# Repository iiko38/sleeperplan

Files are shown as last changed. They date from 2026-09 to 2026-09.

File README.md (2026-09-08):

# Sleeperplan

**A local workshop tool for repeatable timber sleeper flower beds.**

A job file goes in. Labelled parts, exact stock allocations, saw bands, fixing coordinates, purchases, costs and technical drawings come out. The same positioned timber model drives the cut list, the fixing schedule, the SVG drawings, the optional PDF and the OpenSCAD model.

No LLM calls. Core planner runtime: Python 3.11+ and its standard library. Optional PDF dependency: ReportLab.

The planning engine remains deterministic and local/offline. A static client visualiser is now included under `site/` for showing 1/2/3 course options in-browser. It uses generated JSON artifacts and does not require a database.

## Start here on Windows

Extract the ZIP and open PowerShell **inside the `sleeperplan` folder**, alongside this README.

```powershell
py -m sleeperplan plan examples\neighbour.json --out build\neighbour
```

Open `build\neighbour\BUILD.md` and the files in `build\neighbour\drawings`. SVGs open locally in a browser or suitable image/vector viewer.

If OpenSCAD is installed, open the generated 3D model directly:

```cmd
view-cad.cmd build\neighbour\model.scad
```

Compare two and three courses:

```powershell
py -m sleeperplan compare examples\neighbour.json --courses 2 3 --out build\heights
```

To generate printable PDFs too:

```powershell
py -m pip install -e ".[pdf]"
py -m sleeperplan compare examples\neighbour.json --courses 2 3 --out build\heights-pdf --pdf
```

`height-comparison.pdf` is the same-scale comparison. `options-and-build.pdf` is a single combined document covering every requested height: an options table, the same-scale comparison drawing, then a per-option build section (build sequence, assembled view, one plan page per course, cutting diagrams, process and parts boards). Each height's directory also contains a full `workshop.pdf` with the parts and drilling/mark-out sheets.

For Linux, replace `py` with `python3` and use `/` in paths. Installing the package is unnecessary for the core commands when run from this folder. An optional `pip install -e .` also installs the `sleeperplan` command.

**Output directories must be new.** The tool refuses to overwrite an existing folder. Use a revision name such as `build\neighbour-r02`.

## What to edit for a real job

Copy `examples/neighbour.json` to a new file **in the examples folder** to preserve the relative catalogue path. Change the name, bed dimensions, number of courses and quantity. Measurements are **outside dimensions in whole millimetres**. Prices are **integer pence**.

The example is a **2,400 x 1,200 mm outside footprint**, not the neighbour's surveyed dimensions. It uses the same 100 x 200 mm timber section throughout, on edge: 100 mm wall thickness and 200 mm per course. Two courses are 400 mm; three are 600 mm. `orientation: "flat"` swaps these dimensions and selects different screw lengths.

```json
{
  "id": "front",
  "length_mm": 2400,
  "width_mm": 1200,
  "courses": 3,
  "quantity": 2,
  "corner_pattern": "alternating",
  "freeboard_mm": 50,
  "access_sides": 2,
  "site_type": "level_open_ground"
}
```

Put several designs in `beds` and the tool cuts them as **one batch**, sharing stock capacity and rounding screw packs once across the whole job. `examples/batch.json` demonstrates this. `examples/with-offcut.json` adds one measured piece of existing stock.

The catalogue is ordinary editable JSON in `catalogues/`. It contains a dated Wickes price snapshot, not a live stock integration. Duplicate the catalogue for a new date or a different uniform timber profile. Every stock length in one catalogue must have the stated section, treatment/material and finish. Do not mix mismatched timber under one profile.

The supplier description says Wickes in the Clapham / West Sussex area, as requested. **The exact branch is unconfirmed.** The official Worthing store is documented in `docs/SOURCES.md`; no branch availability has been asserted.

## The outputs

| File | Purpose |
|---|---|
| `plan.json` | Full model, normalised inputs, source URLs, date, review gates and input hash. |
| `parts.csv` | Unique piece IDs, lengths, course, orientation, assembly coordinates and allocated stock board. |
| `stock.csv` | Every purchased/existing sleeper used, trims, cost and remaining offcut. |
| `cuts.csv` | Sequential saw operations; exact kerf start, end and blade centre from the original stock datum A. |
| `fixings.csv` | Each screw's entry face, local/global coordinates, direction, receiving piece, nominal penetration and pilot status. |
| `shopping.csv` | Sleeper quantities, whole screw packs, spares and explicit extras/labour. All monetary columns are pence. |
| `web-manifest.json` | Static-web manifest for viewer/links/camera defaults. |
| `quality-report.json` | Deterministic export checks (sections, drawing inventory, callout coverage). |
| `operations.json` | Compiled ordered workshop schedule (receive/label/cut/treat, place/clamp, mark-STOP or drill + drive per fixing, dependencies). Drives the web assembly player. |
| `assembly-manual.pdf` | Optional IKEA-style step-by-step guide compiled from the same operations: one action per numbered panel, 3D keyframes with active/installed/ghost parts, scaled joint sections, explicit repeat counts and mark-out sheet references. |
| `BUILD.md` | Job-specific dimensions, review gates, workflow and assembly instructions. |
| `inventory-proposal.json` | Unused existing inventory and useful new offcuts; merge only after the physical job is completed. |
| `drawings/` | Assembled views, each course, cutting diagrams and an individual fixing sheet for every part. |
| `model.scad` | OpenSCAD geometry; set `explode_mm` to inspect courses and `show_fixing_paths` to show screw paths. |
| `workshop.pdf` | Optional vector workshop pack, generated from the same drawing scene graph. |

The comparison command creates complete **independent alternatives**. It does not consume inventory between options or add their purchases together. It resets review records because changing a design needs a new review.

## What is checked, not guessed

**Joinery.** With alternating corners, courses 1/3 use two full-length long members and shorter cross-members; course 2 reverses which sides pass through the corners. There are no mid-side splices. A length that cannot be cut as one piece is rejected, rather than quietly joined.

**Saw allowance.** Two exact 1,200 mm parts do not fit a 2,400 mm sleeper with a non-zero saw kerf. A final piece that exactly reaches a sound stock end does not get charged an imaginary final cut. End trims are explicit and include their own kerf. Tiny terminal slivers that require edge-shaving are rejected by this full-crosscut model.

**Stock optimisation.** A bounded exact dynamic programme enumerates feasible cutting patterns across stock lengths and finite inventory. Its objective is purchase price, then purchased sleeper count, then total input length. If its deterministic work budget is exhausted, it emits a valid greedy fallback labelled **heuristic**, never “optimal”. If that fallback fails it does not claim infeasibility was proven.

**Screw paths.** Corner and vertical fixing paths are checked against the actual positioned timber. Receivers must exist; tips must stay in the receiving member; modelled shafts must not collide. Upper-course screws are staggered to avoid previously installed screws. Extra intermediate entries are added when collision avoidance would otherwise exceed the configured maximum spacing. These are geometric checks, not strength calculations.

**Purchases and costs.** Screw packs round upwards after the configured spares allowance. Existing stock does not incur a second cash purchase, but its value is left as an explicit cost to resolve. Transport, fill, supports, liner, preparation, treatment, consumables and labour cannot vanish silently: missing values remain `null`/`UNPRICED`, and a complete-cost figure and margin target are withheld.

## Important: the supplied plans are drafts

The code is tested. **The construction detail has not been field-validated.** Do not use an unreviewed pack as a completed engineering design.

The starting Wickes catalogue confirms the screw products, sizes and prices, **not a specific pilot-hole diameter/depth**. All fixing centres are calculated, but `pilot_mode` deliberately starts as `unconfirmed`. After obtaining the actual product/timber instruction or recording an appropriate supervised trial, enter either:

* `pilot_mode: "pilot"`, with the confirmed `pilot_diameter_mm`, `pilot_depth_mm` and `pilot_evidence`; or
* `pilot_mode: "none"`, with evidence supporting no pilot for that exact use.

Both also require `pilot_evidence_kind`: `manufacturer_instruction` or `recorded_trial`. The value `fixture` marks test/demonstration data and **can never issue a workshop plan**, even with a matching approval hash.

There is no automatic “screw diameter minus 2 mm” rule.

Before releasing a pack, measure timber/kerf and review the site, supports and fixing design. Then bind the review to the exact physical design: run a draft plan, copy the printed `Physical design hash` into the job's review block as `approved_physical_design_hash`, and run:

```powershell
py -m sleeperplan plan examples\your-job.json --out build\your-job-reviewed --release --pdf
```

`--release` refuses missing checks, unconfirmed pilots, fixture evidence, out-of-scope sites/heights, and any mismatch between the recorded approval and the current physical design (a changed dimension, screw or machining spec invalidates the old approval; a price-only update does not — hardware selection is price-independent). A missing approval hash blocks draft/check as well (`release_ready: false`), so a draft never looks clearer than its release would be. A released status means the review was recorded, **not** that the software certified a structure. Any changed dimensions, hardware, stock or site require renewed review.

`examples/reviewed-example.json` and `catalogues/wickes-reviewed-2026-09-06.json` are **DEMONSTRATION fixtures** for the release gate. Their pilot "trials" and reviewer records are placeholders, not real workshop evidence.

Generated `build/` output is never distributed from the repo. The only tracked result bundles live under `published/`, which publication tests keep free of issued plans and hash-verified against their manifests.

Every export also compiles an ordered workshop schedule, `operations.json` — receive/label/cut/treat per board, place/clamp per course, then mark (STOP) or drill + drive per fixing with explicit dependencies. The customer site plays that schedule step by step with deterministic screw-insertion animation.

V1 covers **rectangular, open-bottom flower beds on level ground**, with nominal heights up to 600 mm for reviewed output. That height is a software scope boundary, not a universally safe height. Retaining walls, slopes, roofs/decks, hard-surface drainage details, structural calculations, bespoke support/bracing layouts and mid-side splice designs are not implemented. The app will not supply missing engineering by inventing it. See `docs/ENGINEERING.md`.

## Cost entry

Example **syntax**, not recommended prices:

```json
"costs": {
  "labour_minutes": 240,
  "labour_rate_pence_per_hour": 3000,
  "target_margin_bps": 2500,
  "extras": [
    {
      "id": "transport",
      "description": "Collection travel",
      "quantity": 1,
      "unit": "job",
      "unit_price_pence": 1500
    }
  ]
}
```

Here `2500` basis points means 25% gross margin, calculated as cost / (1 - margin), **not** a 25% markup. The target remains blank until every required cost line is supplied. Set a line explicitly to zero only when genuinely not required or already allowed elsewhere. This is an internal cost tool, not an invoice or VAT accounting system.

Fill litres come from the clear opening and specified freeboard. They do not include settlement/compaction allowances, existing soil, displaced supports or a planting recipe. Liner area is a net internal-wall measure, not a roll cutting/nesting plan. Price the actual required materials separately.

## Reproducibility and testing

```powershell
py -m unittest discover -v
py -m sleeperplan plan examples\neighbour.json --as-of 2026-09-06 --out build\reproduction
py -m sleeperplan check examples\neighbour.json --as-of 2026-09-06
```

`check` exits 3 for a geometrically valid but unreviewed draft, 2 for invalid/infeasible input, 0 for a clear review gate. Normal draft `plan` output exits 0 so design iterations are usable. `--release` turns missing review into an error.

The tests include an independent exhaustive subset solver for small cutting cases, seeded geometry/material-conservation cases, stock limits, screw-path collisions, golden worked examples, monetary rounding, review gates, deterministic exports, CLI behaviour and optional PDF generation. `docs/VALIDATION.md` records what was actually run and what remains to be tested on site / native Windows.

## Code map

```
sleeperplan/
  model.py       typed job, stock, timber and fixing records
  config.py      strict JSON/unit/money validation
  geometry.py    positioned pieces, connections and path checks
  cutting.py     exact cutting stock solver, fallback and saw bands
  costing.py     purchases, pack rounding, extras and labour
  planner.py     pipeline, provenance hash and review gates
  drawing.py     shared vector scenes and OpenSCAD export
  export.py      transactional CSV/JSON/drawing/build-note output
  pdf.py         optional print rendering
  cli.py         plan / check / compare
```

`AGENTS.md` gives coding agents the invariants to preserve. Start improvements by reproducing a physical or mathematical failure in a test. Scope now also includes the static customer visualiser in `site/`.

## Customer visualiser

`site/` is a static client-facing page for presenting offer options:

- 1, 2 and 3 course variants loaded from generated `web-manifest.json` bundles.
- Interactive 3D rotate/pan/zoom with Z-up orientation and visible course edges.
- Client-friendly metrics and process flow with links to assembled/process/manual/PDF artifacts.

Run locally:

```powershell
py -m http.server 4173
```

Then open:

```text
http://localhost:4173/site/
```

Optional direct offer links:

```text
http://localhost:4173/site/?offer=c1
http://localhost:4173/site/?offer=c2
http://localhost:4173/site/?offer=c3
```

## Repo harness

This repository follows the NAS repo-harness pattern with current-state files at repo root:

- `AGENTS.md`
- `state.yaml`
- `backlog.md`
- `implementationstatus.md`
- `checklists/2026-09-07-field-trial-wave.md`

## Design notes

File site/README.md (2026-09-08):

# Sleeperplan Viewer

Static customer-facing WebGL showcase for Sleeperplan offer options.

## Features

- Presents 1-course, 2-course and 3-course offer variants
- Interactive 3D orbit/pan/zoom using browser WebGL (Z-up, vendored three.js, no CDN dependency)
- Deterministic **assembly player**: play/pause/step/scrub through the compiled
  operation schedule (`operations.json`) — receive/label/cut per board,
  place/clamp per course, mark-STOP or drill + drive per fixing. Screw insertion
  is deterministic (`head(u) = E - d*(L+g)*(1-u)`); the final frame equals the
  approved model exactly.
- Status & blockers panel showing the loaded plan's real unresolved issues
- Uses manifest camera defaults for a zoomed-out start view; batch beds render
  side by side via display-only offsets
- Links to generated docs/drawings from the same bundle

## Run locally

```sh
python -m http.server 4173
```

Open `http://localhost:4173/site/` and use the option tabs.

Optional direct option query:

```txt
http://localhost:4173/site/?offer=c1
```

## Deploy

Deploy this folder with Vercel:

```sh
vercel --prod
```

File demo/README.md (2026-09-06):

# Worked outputs

Generated with Sleeperplan 0.1.0 and the dated Wickes catalogue, as of 6 September 2026.
These are hypothetical dimensions, not a survey of the neighbour's beds.
All packs deliberately remain DRAFT_MARK_OUT_ONLY: fixing pilots and site/connection details require review.

- `height-options/height-comparison.pdf`: same-scale two- and three-course comparison.
- `height-options/2-courses/workshop.pdf`: full 400 mm high example pack.
- `height-options/3-courses/workshop.pdf`: full 600 mm high example pack.
- `batch/`: three beds optimised as one cutting and purchasing job.
- `with-offcut/`: an existing measured sleeper/offcut included in the allocation.

The 2,400 x 1,200 mm outside footprint has a 2,200 x 1,000 mm clear opening.
Two courses: 6 purchased sleepers, 6 saw cuts, 30 fixing entries, GBP 189.30 timber and screws.
Three courses: 9 purchased sleepers, 8 saw cuts, 52 fixing entries, GBP 294.60 timber and screws.
Those are not complete installation prices: unresolved costs are explicitly unpriced in each plan.

See the main README for commands to generate a new job. Do not modify generated outputs to change a design; edit the input and regenerate into a new directory.

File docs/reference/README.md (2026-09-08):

# Reference: construction pack exemplar (commit 37db13b)

These files are an externally produced visual-construction pack for the
2400 x 1400 x 600 mm long-through model at repo commit `37db13b`. They set the
design standard for Sleeperplan's generated assembly manuals.

## Contents

- `Sleeperplan_Construction_Manual_37db13b_DRAFT.pdf` — 20-page visual step-by-step manual (landscape A4, course-coloured isometrics, stage-per-page narrative, do/don't callouts, per-course stack cards, drill/drive storyboard frames).
- `Sleeperplan_Workshop_Markout_37db13b_DRAFT.pdf` — 6-page workshop cut/mark-out reference cards.
- `Sleeperplan_Construction_PDF_Pack_37db13b_DRAFT.zip` — original distribution bundle.
- `pack/` — extracted bundle: `mark_out_2400x1400_three_courses.csv` (56-fixing register),
  `independent_checks.json`, `pack_manifest.json`, and the generator source
  (`pack/source/make_construction_pack.py`, `pack/source/review_model.py`).

## Provenance

- `pack_manifest.json`: source commit `37db13b`, model `examples/first-model-2400x1400.json`,
  model hash `94ab5b0d...`, status `DRAFT_VISUAL_CONSTRUCTION_PACK`.
- The geometry is an independent transcription (`review_model.py`) cross-checked against
  the committed r08 build artifacts; the pack's own manifest lists the unresolved items
  (pilot diameter/depth, head seat/recess, connection capacity, supports/drainage/site).
- **This is a DRAFT visual pack, not issued drilling instructions.** The manual itself
  says centres are known but drill settings are not; treat it exactly like our own
  DRAFT_MARK_OUT_ONLY outputs.

## How we use it

Adopted as the design target for `assembly-manual.pdf` (v0.5+): the "Book" page
system (kicker / declarative headline / callout boxes / course-colour coding /
stage aggregation instead of one page per fixing), ported to be **generated from
`operations.json` + `plan.json`** so it covers every height and footprint
automatically instead of being a hand-transcribed three-course exemplar.

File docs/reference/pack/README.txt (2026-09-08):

Sleeperplan construction PDF pack for commit 37db13b378fc868f2d4e6b73f8ba19f6e5f4b526

Files:
- Sleeperplan_Construction_Manual_37db13b_DRAFT.pdf : visual step-by-step construction manual
- Sleeperplan_Workshop_Markout_37db13b_DRAFT.pdf : workshop cut / mark-out reference cards
- mark_out_2400x1400_three_courses.csv : full transcribed 56-fixing register
- pack_manifest.json : provenance and unresolved release items

Status: DRAFT. Exact cutting locations and fixing centres are shown. Pilot-hole and head-seat instructions remain unconfirmed and are deliberately shown as TBC.

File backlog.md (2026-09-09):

# Sleeperplan Backlog & Roadmap

A deterministic, offline workshop tool for repeatable timber sleeper flower beds.

## Current Milestone: MVP Complete & Hardened (v0.1.0)
- [x] Deterministic 3D solids coordinate model with alternating corner joinery.
- [x] Exact DP cutting stock solver with bounded heuristic fallback.
- [x] Axis-aligned screw path clearance and 3D collision avoidance.
- [x] Global screw pack rounding with spares allowance.
- [x] Complete transactional exports: CSV BOMs, cut list, SVG technical drawings, OpenSCAD 3D model, vector PDF workshop pack.
- [x] Independent multi-option height comparison tool (`compare`).
- [x] Release review gating (`--release`) blocking unreviewed drafts or unconfirmed pilot specs.
- [x] 83-test comprehensive test suite with property and oracle checks.
- [x] Windows native execution verified (`health.cmd`, `health.ps1`, `sleeperplan.cmd`).
- [x] OpenSCAD workstation integration verified (`view-cad.cmd`, OpenSCAD 2021.01, health smoke compile).
- [x] Deterministic static web manifest + quality report export (`web-manifest.json`, `quality-report.json`).
- [x] Customer-facing static offer visualiser (`site/`) for 1/2/3 course options with interactive 3D and process walkthrough.
- [x] Vercel static deployment pipeline verified for `site/`.

## v0.2.0 / v0.3.0 Hardening (review-driven) — complete
- [x] Physical-design approval binding (`approved_physical_design_hash`); price-only revisions keep approval; machining changes invalidate it (v0.2.0).
- [x] Screw heads/seats declared unmodelled with explicit `head_seat_unmodeled` issue and docs (v0.2.0).
- [x] DEMONSTRATION fixture marking on reviewed example/catalogue with regression test (v0.2.0).
- [x] Combined `options-and-build.pdf` covering 1/2/3 course options + build guides (v0.2.0).
- [x] Deterministic operations model (`operations.json`) + web assembly player with deterministic screw-insertion animation (v0.3.0).
- [x] Price-independent screw selection; commercial rules excluded from physical hash; generator version included (v0.3.0).
- [x] Evidence-kind gate (`fixture` can never issue) (v0.3.0).
- [x] Unified draft/check/release readiness (`release_ready`) (v0.3.0).
- [x] Publication quarantine: stale packs removed, `published/` allowlist with identity checks; legacy viewer defaults to published pack and escapes HTML (v0.3.0).
- [x] Viewer hardening: DPR resize, per-bed display groups, recursive disposal, manifest/plan hash check, blockers panel (v0.3.0).
- [x] Print sizing: paginated parts/stock pages with readable continuation tables (v0.3.0).

---

## Next Milestone: Physical Shop & Field Validation

- [ ] **HIGH PRIORITY — 3-tier 9-sleeper optimisation:**
  - Replace the current 12-sleeper 2400 x 1400 example with a near-identical-width design that uses **9 x 2400 mm sleepers total**.
  - Six 2400 mm sleepers remain full length for the long sides; the remaining three 2400 mm sleepers each produce two short sides.
  - Do **not** preserve an exact 1400 mm outside width if that forces three extra sleepers. Accept a few millimetres of width change to fit real kerf efficiently.
  - Current integer-mm planner target: **1197 mm short sides / 1397 mm outside width**, which fits two identical shorts in a 2400 mm board under the existing conservative 3 mm kerf model (`1197 + 3 + 1197 + 3 = 2400`).
  - Re-run BOM, cuts, costs, operations, animation and PDF packs after the geometry change; regression-test that the 3-course option purchases exactly 9 sleepers.
  - Reconfirm against the measured real sleeper lengths and actual saw kerf before finalising the physical prototype.

- [x] **Session Harness Refresh (2026-09-07):**
  - Verified repo core harness files against `P:\homelab\patterns\repo-harness` (`AGENTS.md`, `state.yaml`, `backlog.md`, `implementationstatus.md`).
  - Added a dated active checklist under `checklists/` for the current field-validation wave.

- [ ] **Stock Dimension & Kerf Calibration:**
  - Measure 3-5 real 100 x 200 x 2400 mm sleepers from Wickes Worthing / regional store.
  - Measure actual saw kerf on 100x200 crosscuts with the target workshop circular/mitre saw.
  - Check end squareness and measure minimum squaring trim required on factory ends.
- [ ] **Fastener & Pilot Testing:**
  - Test drive Wickes 7x150 mm and 7x250 mm washer-head screws into scrap treated softwood sleepers.
  - Compare direct driving vs 4 mm / 5 mm pilot hole: measure split risk near edges/end-grain and torque resistance.
  - Document confirmed pilot diameter, depth, and driving technique in `docs/SOURCES.md`.
- [ ] **First Prototype Assembly (Controlled Trial):**
  - Cut and assemble a 2-course prototype according to generated `cuts.csv` and `BUILD.md`.
  - Validate physical alignment, hole mark-outs, and corner interlocks against SVG drawings.
  - Inspect vertical screw staggering in real timber.

---

## Future Feature Backlog (Post-Field Validation)

### Joinery & Structural Support
- [ ] **Support & Bracing Module:**
  - Automated corner post / internal stake sizing and screw calculation for beds on soft ground or heights > 400 mm.
  - Ground anchor and staking schedules.
- [ ] **Liner & Drainage Detailer:**
  - Per-bed liner cutting layout and membrane overlap calculation.
  - Freeboard and base gravel drainage calculator.

### Catalogue & Stock Expansion
- [ ] **Multi-Supplier Catalogues:**
  - Snapshots for Travis Perkins, B&Q, Jewson, and local timber merchants.
  - Support for alternate sleeper sections (e.g. 125 x 250 mm oak, 100 x 150 mm softwood).
- [ ] **Reusable Offcut Management:**
  - Automated ingestion of `inventory-proposal.json` from completed jobs into a workshop stock registry.

### Workshop Productivity
- [ ] **Mark-Out & Jig Templates:**
  - 1:1 printable drill hole drilling templates for corner and stack fixings.
  - Cut stop / stop-block setup sheet for batch cutting.

### Client Experience (Static Site)
- [ ] **Operations-driven PDF keyframes:**
  - Render step keyframes from `operations.json` into the printable packs so PDF and player share one schedule.
- [ ] **Joint Recipe & Machining Operations (blocked on physical trial):**
  - Per-joint recipe records (head seat, bore preparation, depth datum, evidence) consumed by operations, drawings and CSVs.
  - Per-recipe fastener cards instead of one card per SKU (F08).
- [ ] **Sales Narrative Pass:**
  - Add clearer option positioning text (best-fit use cases) without overstating engineering claims.
  - Add optional branded hero imagery/background assets while keeping page load fast.
- [ ] **Visual Comparison Enhancements:**
  - Add side-by-side mini thumbnails for 1/2/3 course profiles.
  - Add optional animated transition between course options.

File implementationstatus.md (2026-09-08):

# Implementation Status

## Current Snapshot
- **Version:** 0.3.0
- **Status:** Planner + operations model + assembly player live; approval/evidence/publication gates enforced; physical joint-recipe trial still required
- **Host Platform:** Windows 11 Native (Verified on `DESKTOP`)
- **Python Version:** CPython 3.12.10 (64-bit)
- **Test Results:** 99 tests passed (unittest, 100% passing)
- **Core Dependencies:** Standard Library only (`reportlab 4.5.1` for PDF export, `pytest 9.1.1` for test execution)

## Verified Functionality
1. **Core Geometry Engine:**
   - Uniform timber profiles on edge (e.g. 100x200 mm) or flat.
   - Alternating corner joints across courses (odd/even course interlocking).
   - Exact piece coordinates, clear opening, and cavity volume calculations.
2. **Cutting Stock Optimizer:**
   - Linear stock cutting optimizer using bounded exact dynamic programming.
   - Heuristic best-fit fallback when budget is exceeded (never claims false infeasibility).
   - Strict material conservation accounting for kerf and squaring trims.
3. **Fixing & Fastener Geometry:**
   - 3D axis-aligned clearance checking preventing screw collisions.
   - Vertical stack screw staggering between adjacent courses.
   - Full-penetration checks into target receiving timber.
4. **Costing & Procurement:**
   - Exact sleeper purchases from inventory and store catalogues.
   - Global screw pack rounding with spares allowance across whole batches.
   - Strict unknown-cost withholding (never silently assumes £0 for missing materials/labour).
5. **Multi-Format Export Pipeline:**
   - Technical mark-out and assembly drawings in SVG.
   - 3D OpenSCAD model generation (`model.scad`).
   - Vector PDF workshop packs and comparative height sheets (`workshop.pdf`, `height-comparison.pdf`).
   - CSV outputs: `cuts.csv`, `parts.csv`, `fixings.csv`, `stock.csv`, `shopping.csv`.
6. **Safety & Scope Enforcing Gates:**
   - Strict review gating (`--release`) rejecting drafts without recorded human measurement, site check, fixing check, and confirmed pilot hole evidence.
   - Hard boundary at 600 mm max height and open-bottom level-ground beds for v1 release.
7. **Static Web Export + Client Visualiser:**
   - Export now includes `web-manifest.json` (artifact/drawing pointers + viewer camera defaults) and `quality-report.json` (deterministic export checks).
   - Customer-facing static site in `site/` presents 1/2/3 course offer options with interactive 3D orbit/zoom/pan.
   - Course separation is visually explicit via per-piece black edge outlines; viewer uses Z-up axis to match generated geometry.
   - Client view includes at-a-glance metrics and process walkthrough, with direct links to assembled drawing, process sheet, manual, and printable PDF.
   - Vercel deployment verified and aliased to: `https://site-rho-six-fdck1jw7c6.vercel.app`.
8. **Combined Height-Options PDF:**
   - `compare --pdf` additionally renders `options-and-build.pdf`: options table, same-scale comparison, then per-option build sequence + course plans + cutting/process/parts/stock pages.
9. **Deterministic Operations Model + Assembly Player:**
   - `sleeperplan/operations.py` compiles an ordered, typed workshop schedule (`operations.json`, schema `sleeperplan.operations.v1`) from the same geometry: receive/label/cut/treat per board, place/clamp per course, mark-STOP or drill + drive per fixing, supports/final checks, with explicit dependencies.
   - The customer site plays that schedule: play/pause/step/scrub, pieces appear when placed, screws animate insertion via `head(u) = E - d*(L+g)*(1-u)` (final frame equals the approved model exactly), per-step camera framing, active-piece highlighting, per-bed display groups for batch jobs.
10. **Approval, Evidence and Publication Gates:**
    - `--release` binds `review.approved_physical_design_hash` to the current physical design hash (price-only revisions keep approval; dimension/hardware/machining changes invalidate it). Screw selection is price-independent, so repricing can never swap hardware under an approval.
    - `pilot_evidence_kind` (`fixture` | `manufacturer_instruction` | `recorded_trial`) is required for confirmed pilot modes; fixture evidence can never issue a workshop plan.
    - One readiness calculation shared by draft/check/release (`release_ready` field); publication tests keep the public tree (`published/`, `site/demo`) free of issued plans and verify manifest/plan identity.

## Developer Harness & Automation
- `health.cmd` / `health.ps1`: One-command comprehensive environment, dependency, OpenSCAD compile smoke, test suite, and CLI smoke test verification.
- `sleeperplan.cmd`: Root CLI runner directly delegating to `.venv`.
- `view-cad.cmd`: One-command OpenSCAD launcher for generated `model.scad` outputs.
- Directory junction `projects/sleeperplan` linked to `projects/sleepers`.
- Repo harness core files aligned with NAS pattern (`AGENTS.md`, `state.yaml`, `backlog.md`, `implementationstatus.md`) and active checklist tracking in `checklists/`.

## Next Operational Step
Execute physical shop measurement trial on Wickes sleepers and record pilot hole torque/split evidence to promote draft job files to reviewed release packs.

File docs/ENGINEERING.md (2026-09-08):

# Geometry contract, workshop conventions and limits

## One coordinate model

Each bed has its own local XYZ origin at its outside S/W bottom corner. S/N are labels, not compass directions. X follows the nominal long side; Y follows the other side; Z is height. S/N members are placed in +X; W/E members in +Y. All actual geometry uses positioned rectangular solids.

For outside length L, outside width W and wall thickness t:

- Odd alternating courses: S/N lengths L, W/E lengths W - 2t.
- Even alternating courses: S/N lengths L - 2t, W/E lengths W.
- Clear opening: (L - 2t) x (W - 2t).
- Top height: course count x course height.
- Fill volume: clear length x clear width x (height - freeboard), divided by 1,000,000 for litres.

The nominal profile is uniform across every piece. Edge/flat changes the section orientation, not its material. The photograph is inspiration only: no dimensions or buildable corner arrangement have been reverse-engineered from its perspective.

The compiler checks the expected ring area, absence of timber overlap and bed envelope for every course. Drawings never calculate a different length independently. Piece IDs include design, instance, course and side.

## Saw geometry

Every cutting stock item has gross length G, total start/end removals a/b, and kerf k. Usable length U = G - a - b. Trims include their kerf and are either zero or at least k. All cut coordinates are relative to the original stock datum A, before trimming.

A pattern containing n finished pieces with total finished length S is feasible precisely when:

```
S + k*(n-1) == U       # final piece reaches usable stock end: n-1 cuts
or
S + k*n <= U           # a final cut is made: n cuts
```

This is intentionally conservative about edge shaving. It does not assume that a terminal sliver narrower than k can be removed safely with a partially overhanging blade. A sound full-stock piece needs zero crosscuts. A full crosscut through a sleeper may need multiple tool passes; tool capacity and technique are not selected by this code.

Every board must conserve material:

```
gross length = finished parts + retained/discarded tail + complete trims + kerf from part-separating cuts
```

Actual dimensions, timber movement, knots, splits and blade wander can invalidate a nominal plan. Measure and regenerate; do not quietly shorten a component. To allow squaring of a nominal 2,400 mm sleeper, set the actual end removals and choose a feasible footprint. Full-length sides at 2,400 mm assume genuinely usable ends and adequate measured stock length.

The optimiser is exact for its encoded linear-stock/crosscut problem when `optimality_proven` is true. It is not optimising manufacturing time, tool changes, defects, grain, moisture, delivery charges, bulk-price tiers or a speculative resale value of offcuts. Fixed delivery/collection and other costs belong in explicit extras. Store availability is unconfirmed unless quantities are entered after checking.

The search bound counts work deterministically. A completed dynamic programme proves the lowest lexicographic objective over the enumerated stock model. A budget-limited best-fit-decreasing fallback is marked heuristic and may cost more. Independent tests compare exact results against a separate subset-partition solver.

## Fixing geometry is not connection engineering

Corner screws enter the OUTER broad face of the full-through member at t/2 from each end, at one-quarter and three-quarters of the course height. They traverse t before entering end grain of the perpendicular member. These positions form a proposed regular marking pattern, not a Eurocode/manufacturer-certified joint detail.

Stack screws enter the TOP face, on the cross-section centreline, and traverse one course height into the course below. The routine identifies the actual receiver and checks the path. It moves upper-course entries to avoid lower screws and the corner screws. Where a shift enlarges a gap beyond the configured maximum, an intermediate entry is added rather than accepting the gap.

The starting rules are **editable shop-layout assumptions**:

| Rule | Starting value | Meaning / limitation |
|---|---:|---|
| Nominal minimum penetration | 50 mm | Includes screw point; does not establish effective thread engagement or holding capacity. |
| Far-face clearance | 20 mm | Keeps a nominal straight tip away from the opposite timber face. |
| Stack end clearance | 80 mm | Geometric distance from receiving/through member ends for stack fixings only. |
| Side clearance | 20 mm | Geometric cross-section clearance for stack paths. |
| Stack target end inset | 200 mm | Increased when necessary for the section/end-clearance rule. |
| Stack maximum spacing | 600 mm | Layout rule, not proof of resistance to soil pressure. |
| Additional shaft separation | 12 mm | Added to both shaft radii for idealised path collision checks; not a full swept-tool or hardware-head model. |

For two perpendicular or parallel axis-aligned screw segments, minimum segment separation is computed from their interval separations on X/Y/Z. This is exact for these straight, axis-aligned paths. It does not model angled driving, large/irregular heads, countersinks, clamps, drill body access, dimensional tolerances or timber displacement. The installer must check these before execution.

The actual fastener selection must be suitable for treated timber, exterior exposure, end-grain withdrawal, loading and the full site. Manufacturer guidance and competent review take precedence over these geometric defaults. Brackets/posts/through-bolts or other supports may be required; this version does not design or draw them. Their materials and labour must be priced explicitly and their installation detail recorded separately.

**Screw heads, bearing seats, recesses and driver access are not modelled.** Only idealised shafts are collision-checked. On stacked courses a protruding head can stop the next sleeper sitting flat even though every shaft passes the clearance check; recessing a bearing seat deepens the effective hole and moves the tip, so tip clearance must be re-checked after any recess. The plan raises a `head_seat_unmodeled` issue whenever a bed has more than one course. Confirm the head-seat detail with the actual hardware before stacking; an approved joint recipe (hardware, head seat, bore preparation, depth datum, evidence) is a prerequisite for sellable kits.

**Pilot diameter and depth are not inferred.** The selected Wickes product pages did not establish those values. Confirm them against the actual product/timber and record the evidence. A recorded no-pilot instruction is distinct from an unknown pilot instruction. The release gate enforces that distinction, but cannot verify the truth of a human's evidence.

## Site and material limits

The executable v1 design envelope is a rectangular open-bottom flower bed on level ground, no mid-side splices and a reviewed-output height not above 600 mm. The software can draft higher alternatives to demonstrate why review is blocked. The envelope is a scope choice, not proof that every bed inside it is safe.

No structural design is supplied for retaining slopes, roofs/decks, hard surfaces, foundations, lateral loads, soil pressure, posts/bracing, accessibility, buried services or a load-bearing use. No guarantee of timber warranty after cutting is made. The cited Wickes timber instructions say to preserve cut ends, so follow the compatible treatment supplier's method. Follow tool and PPE instructions and assess safe lifting/transport; the stock can be heavy and wet timber weight varies.

Drainage is site-specific. A liner/protection layer must not create an undrained basin. RHS guidance distinguishes construction on hard surfaces; v1 refuses to release that site type because it has not implemented those drainage details. Fill calculations deliberately stop at cavity geometry and do not invent soil recipes, density-based bulk-bag conversions, settlement percentages or planting choices.

The “centre reach over 650 mm” warning is a user-fit prompt only; it is not an accessibility standard. A decorative bed with planting access around it differs from a productive bed worked from one side. Confirm the actual use and reach.

## Release and physical validation

All included examples are drafts. The three review flags plus reviewer/date/notes record that measurements, site/supports and fixings have been checked. `--release` requires them and confirmed pilot specifications, and refuses unsupported sites/heights. This is a workflow gate, not professional certification. Editing a reviewed job does not make its old review applicable to the new design; renew the review after every meaningful change. Height comparison resets reviews automatically.

**Approval binding.** The plan carries a `physical_design_hash` — a SHA-256 over the physical artefact only (generator version, profile, beds, orientation, stock lengths/trims, screw lengths/diameters/pilot spec, geometric rules). Prices, pack sizes, availability, commercial rules (spares allowance, price-age limits), provenance text, the review block and the as-of date are excluded, so a price-only revision does not invalidate a physical approval, while any change to dimensions, hardware or machining does. Hardware selection is itself price-independent (`length, diameter, id`): repricing can never swap the installed screw. `--release` requires `review.approved_physical_design_hash` to equal the current hash: a mismatch blocks release (`stale_approval`), and a missing hash blocks draft, check and release (`approval_hash_required`); plans carry the unified `release_ready` field. Workflow: run a draft plan, copy the printed physical design hash into the job's review block once the physical review is genuinely done, then release. `examples/reviewed-example.json` and `catalogues/wickes-reviewed-2026-09-06.json` are DEMONSTRATION fixtures for this gate — their reviewer/pilot text is not real evidence.

**Evidence kinds.** Confirmed pilot modes require `pilot_evidence_kind`: `manufacturer_instruction`, `recorded_trial`, or `fixture`. Fixture evidence is test/demonstration data and blocks issuance unconditionally (`fixture_evidence`), whatever the evidence text claims. Software cannot verify the truth of a human trial; it can refuse known test data.

**Operations schedule.** Every export compiles `operations.json` (`sleeperplan.operations.v1`): an ordered, typed list of workshop operations compiled from the same geometry — receive/label/cut/treat per stock board, place/clamp per course, then mark-STOP or drill + drive per fixing, then supports/final checks. Dependencies are explicit; a drive operation always follows its course clamp and its own preparation. Unknown physical values (pilot spec, head seat) surface as mark-out-only/STOP operations, never invented machining instructions. The web assembly player renders this schedule deterministically: displayed state is a pure function of plan + operation index + progress, and screw insertion uses `head(u) = E - d*(L+g)*(1-u)` so the final frame equals the approved modelled position exactly.

For the first real bed, use a controlled trial: measure stock/kerf; verify a full-size course; check the saw sequence against one physical board; confirm the exact pilot/driver setup and connection with a competent builder or supplier; then compare the installed course to the drawing. Verify supports and drainage before filling. Record changes and make regression tests before standardising a sellable kit.

Future development should follow failures found in that process. Likely useful extensions are a properly specified support/bracing module, surveyed site constraints, actual-vs-estimated labour, material valuation, price import and manufacturing jigs. A storefront is not needed to validate any of those fundamentals.

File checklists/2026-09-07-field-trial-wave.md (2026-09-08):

# Checklist - 2026-09-07: Field Trial Wave

## Context

This wave starts after MVP software validation and OpenSCAD workstation bedding-in.
The repo remains an offline planning tool and default outputs remain draft until physical evidence is captured.

## Non-Negotiables

- Preserve AGENTS.md invariants, especially geometry/cut/fixing single-model truth.
- Keep units strict (integer mm, integer pence) and avoid inferred pilot rules.
- Do not claim field validation without recorded evidence paths.
- Do not change release status for draft examples without fresh measured review data.

## Phase 1 - Harness And Tooling Baseline

- [x] Confirm OpenSCAD installation on workstation.
- [x] Confirm OpenSCAD compile smoke in health script (`demo/batch/model.scad` -> CSG).
- [x] Confirm repo harness core docs are present (`AGENTS.md`, `state.yaml`, `backlog.md`, `implementationstatus.md`).
- [x] Evidence: OpenSCAD version 2021.01 detected; `health.ps1` run passed with 83 tests and OpenSCAD smoke compile.

## Phase 2 - Physical Stock And Fastener Evidence

- [ ] Measure 3-5 real sleepers (actual section, length, squaring trim).
- [ ] Measure actual workshop kerf on target saw setup.
- [ ] Pilot tests for Wickes 7x150 and 7x250 screws (direct drive vs pilot diameters).
- [ ] Record evidence and source metadata in `docs/SOURCES.md`.
- [ ] Evidence:

## Phase 3 - Controlled Prototype Build

- [ ] Build one 2-course prototype from generated plan outputs.
- [ ] Validate cut list and fixing coordinates against physical assembly outcomes.
- [ ] Record any geometry or workflow deltas as reproducible tests before code changes.
- [ ] Evidence:

## Stop Conditions

- Any measured mismatch that breaks material conservation or fixing clearance assumptions.
- Any screw/pilot finding that invalidates current default fastener assumptions.
- Any release-gate bypass attempt without evidence updates.

## Current Next Step

Collect first stock and kerf measurements and add dated evidence to `docs/SOURCES.md`.

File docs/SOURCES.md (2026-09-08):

# Source register

Checked on **6 September 2026**. These are manual public-page snapshots, not scraped/live integrations. Prices are as displayed and exclude delivery. Recheck prices, product suitability and branch stock before buying. The repository does not copy product imagery or manufacturers' documents.

## Timber catalogue

**Wickes SKU 276785** — UC4 incised light green garden sleeper, nominal 100 x 200 x 2400 mm. Displayed promotional price GBP 28 (previous price shown GBP 33). Product page lists 38.40 kg, approximate sizes, ground-contact treatment and treatment of cut ends. The orientation in Sleeperplan is an explicit job setting; it is not inferred from Wickes' “height/thickness” field names.

https://www.wickes.co.uk/Wickes-UC4-Incised-Light-Green-Garden-Sleeper---100-x-200-x-2400mm/p/276785

**Wickes SKU 256948** — matching nominal 100 x 200 x 1800 mm sleeper. Displayed promotional price GBP 24 (previous price shown GBP 29). No weight is populated in our snapshot, so the software will not invent a complete collection weight for an order containing it.

https://www.wickes.co.uk/Wickes-UC4-Incised-Light-Green-Garden-Sleeper---100-x-200-x-1800mm/p/256948

## Candidate fasteners

**Wickes SKU 287686** — Timber Drive washer-head screw, 7 x 150 mm, pack of 25, GBP 9. The page describes Torx drive, exterior use and a weather-resistant coating for treated timber.

https://www.wickes.co.uk/Wickes-Timber-Drive-Washer-Head-Screws---7-x-150mm---Pack-of-25/p/287686

**Wickes SKU 287688** — matching 7 x 250 mm screws, pack of 25, GBP 12.30.

https://www.wickes.co.uk/Wickes-Timber-Drive-Washer-Head-Screws---7-x-250mm---Pack-of-25/p/287688

**Wickes search API cross-check (same product family):** `/search/suggestProductsSecure` returns the four 7 mm Timber Drive washer-head sizes as one range (`287685`, `287686`, `287687`, `287688`) with product-page links and image IDs `GPID_5000106026`..`GPID_5000106029`. Product pages expose manufacturer model numbers `NEW_45`..`NEW_48` for these four sizes.

https://www.wickes.co.uk/search/suggestProductsSecure?term=timber%20drive%20washer%20head%20screws

**Limitation:** these pages establish the listed products and prices, not the structural adequacy of this proposed bed connection, an exact pilot-hole specification or effective embedment. The catalogue leaves pilot mode unconfirmed. None of the numerical placement/clearance defaults is claimed to be a Wickes-approved engineering schedule.

## General construction context

**Wickes — How to build a raised sleeper bed.** General sequence and fixing guidance; describes two screws at a butt joint and support options. This does not certify our generated design.

https://www.wickes.co.uk/ideas-advice/raised-sleeper-bed

**Wickes — How to build and lay garden sleepers.** General cutting/joining guidance, including pilot holes and different fixing considerations for softwood/hardwood. It does not supply a verified bit diameter for the selected screw SKU.

https://www.wickes.co.uk/ideas-advice/sleeper-techniques

Additional extracted points from the same Wickes guidance snapshot:

- Softwood sleepers: piloting is described as "not always necessary" and dependent on tooling.
- Hardwood sleepers: pilot each fixing hole and use stainless screws (to reduce tannin-corrosion risk).
- Fixing length rule-of-thumb: screw length about one-third longer than timber depth.
- One Wickes sentence says to use a pilot bit matching screw diameter and length; this is recorded as source text only, not accepted as a validated sleeper-joint specification for this repo.

**Royal Horticultural Society — How to make a raised bed.** General raised-bed material, drainage and planting considerations. Hard-surface beds need different drainage detail; v1 keeps that outside its reviewed construction scope.

https://www.rhs.org.uk/garden-features/how-to-make-a-raised-bed

**Wickes — How to build a raised sleeper bed.** Reinforces overlap-and-screw approach and repeats hardwood-specific pilot-hole requirement in narrative guidance, but again provides no product-specific pilot diameter/depth values for Wickes screw SKUs.

https://www.wickes.co.uk/ideas-advice/raised-sleeper-bed

**FastenMaster TimberLOK product page (US).** States "No Pre-Drilling Required" for that structural screw line. This is useful as comparative context only; it is not a Wickes 287686/287688 instruction and should not be copied directly into UK sleeper plans.

https://www.fastenmaster.com/products/timberlok

**DIYdata wood screw pilot table (general carpentry reference).** Gives generic clearance/pilot tables by gauge and timber hardness (for example, larger pilot in hardwood than softwood). Useful for broad sanity checking only; not a manufacturer instruction for the selected Wickes timber-drive products.

https://www.diydata.com/carpentry/screw-holes/wood-screw-holes.php

## Manual structure references

**IKEA UK assembly-guides support page.** Used as a structure cue for manual flow (clear "find docs", ordered steps, and visual-first guidance style), not as technical authority for sleeper construction.

https://www.ikea.com/gb/en/customer-service/product-support/assembly-guides/

**IKEA product page document layout example (PAX frame).** Used as a formatting cue for grouping "Assembly and documents", "Good to know", and "Safety and compliance" sections.

https://www.ikea.com/gb/en/p/pax-wardrobe-frame-white-20214571/

## Branch clarification

The user's supplier description was Wickes in Clapham, West Sussex. The exact intended branch was not established. The official Wickes Worthing page lists **114 Dominion Road, Worthing, West Sussex, BN14 8JP**. That is a verified store listing, not confirmation that it is the branch intended, the nearest branch to the job or that any product is locally available.

https://www.wickes.co.uk/store/8221

## Evidence versus assumptions

Source-backed values: dated product dimensions, identifiers and displayed prices; the noted product weight; general supplier/RHS guidance.

Source-backed guidance now also includes: softwood-vs-hardwood pilot treatment from Wickes article guidance, and comparative manufacturer/reference context showing that predrill policy is product-family specific.

Software-derived values: lengths, ring geometry, saw coordinates, board allocation, part IDs, fixing path intersections, volumes and arithmetic totals.

Human/shop assumptions requiring review: actual measurements, kerf, end condition, fixing layout and suitability, exact pilot diameter/depth for Wickes 287686/287688 in this build, support/foundation design, drainage, stock availability, transport, labour and extra materials.

## Pilot-hole status for this repo

Current external research is still insufficient to claim a manufacturer-verified pilot diameter/depth for the specific Wickes screw SKUs used in this project (`287686`, `287688`) in 100 x 200 mm treated sleeper joints. Therefore, default catalogues remain `pilot_mode: "unconfirmed"` unless a documented physical trial or primary manufacturer instruction is recorded for the exact use case.

Additional negative evidence checks were run against likely Wickes media-document patterns for the Timber Drive range (`GPID_5000106026`..`GPID_5000106029`, `NEW_45`..`NEW_48`, and variants such as `_TECH_0`, `_INST_0`), and returned not found responses in this snapshot. This strengthens the decision to keep pilot mode unconfirmed by default.

Direct product API probes that might expose structured technical attachments (`/rest/v2/wickes/products/<sku>?fields=FULL`) returned access denied responses for these SKUs in this environment, so they did not provide usable pilot-hole data.

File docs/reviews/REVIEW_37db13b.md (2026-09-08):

# Sleeperplan — code review and assembly-instructions plan

**Repository:** `iiko38/sleeperplan`  
**Reviewed commit:** `37db13b378fc868f2d4e6b73f8ba19f6e5f4b526`  
**Review date:** 8 September 2026  
**Goal:** exact cuts, explicit drilling operations, visible screw insertion, and an IKEA-like colour manual generated from the same build model.

## Verdict

Keep the deterministic planner. It is a useful geometry, cutting and costing foundation. Do not treat the current outputs as a complete, drill-ready kit specification or an assembly animation.

The essential missing layer is an **ordered, validated list of workshop operations**. The repo knows where the timber and screws end up; it does not yet describe every action that gets them there. That list should drive both the PDF and the player. Adding a prettier picture or another separately written instruction template will not close the gap.

## Scope and verification

Read the handwritten planning/configuration, geometry/cutting/costing interfaces, CLI, export and PDF code, relevant drawing functions, both viewer implementations, all four test modules, catalogue/example changes, and selected generated packs at the pinned commit. Unchanged core modules were also cross-checked by their Git blob identities against the previously inspected source. This was not an audit of every line of vendored Three.js or every duplicated generated file.

GitHub Actions run `34240224252` is successful. Its four core jobs cover Windows and Ubuntu on Python 3.11 and 3.13; the separate PDF job also passed. The PDF-job log reports **91 tests, OK**, followed by a successful PDF smoke export. These are GitHub's executions, not a locally rerun full suite.

A local checkout could not be obtained because outbound GitHub access from the execution environment failed. Repository reads succeeded through the GitHub connection. The supplied `probes/review_probes.py` was executed locally: it copies the relevant selection/hash functions into small synthetic fixtures and reproduces renderer arithmetic. It does **not** execute the full application or a live browser. Fresh PDFs from this commit were not visually rendered in this review; print-size findings below are calculated from the renderer source, not claimed screenshot observations. No physical construction or connection testing took place. No repository files were changed.

## Improvements since the earlier review

- `planner.py` now exposes a physical-design hash and refuses an explicitly mismatched approval. `config.py` validates the hash format; CLI/build notes surface the hash.
- The source reviewed catalogue and example now identify their evidence as demonstrations instead of claiming a real workshop trial.
- `piece_scene` reserves a separate right-hand area for callout circles rather than laying those circles directly over the timber view.
- PDF parts boards can be split into 18-row pages. This is a useful start, although physical printed font sizes remain too small.
- CI for this commit is green. Do not carry forward the old failed-CI finding.

---

# Findings

Priorities here mean: **P1 — fix before issuing workshop/customer kit instructions; P2 — correctness or usability work required for the stated product; P3 — secondary hardening.** A missing product capability is identified as such, rather than presented as a newly introduced regression.

## F01 / P1 — old public output still claims reviewed status

**Locations:** `build/reviewed/BUILD.md`; new tracked `build/` outputs; `tools/viewer.py` default target.

The source catalogue now calls its pilot values demonstration placeholders, but `build/reviewed/BUILD.md` still opens with `REVIEWED_WORKSHOP_PLAN`, has no physical-design hash, and presents complete job costs. It is an older output that did not acquire the new warnings and approval logic. The legacy viewer defaults to `build/reviewed`, which increases the chance of opening it.

**Why it matters:** editing input evidence does not revoke already exported instructions. Making old outputs public can distribute the very unsupported approval that the new code attempts to correct.

**Change:** remove or clearly quarantine obsolete packs from the publishable tree; keep a small, explicit set of current draft examples. Restore a default ignore for working build directories and publish allowlisted, generated artefacts separately. Give published bundles a manifest containing source commit, generator version, resolved build hash, status and file checksums. A publication check must reject demonstration evidence paired with a reviewed/customer-issued status.

**Acceptance:** scanning the public example/export tree finds no demo-based `REVIEWED_WORKSHOP_PLAN`; published instructions can be traced to their exact source and evidence.

## F02 / P1 — price changes can change hardware without changing approval

**Locations:** `planner.py::physical_design`, `physical_design_hash`; `geometry.py::select_screw`; `tests/test_config_costs.py::test_price_only_change_keeps_physical_approval`.

`physical_design` hashes the candidate screw catalogue without pack prices or pack sizes. `select_screw` chooses the shortest fitting screw, then uses **price per screw** to break ties. Two same-length products with different diameters or pilot requirements can therefore switch places after repricing while the approved hash stays unchanged.

**Executed focused reproduction:** synthetic product A is 150 mm long, 7 mm diameter and initially cheaper than product B, which is 150 mm long and 9 mm diameter. Increasing only A's pack price changes selection to B. The physical-design hashes remain identical. This is a catalogue-extension defect; it does not claim the shipped two-length catalogue already makes that substitution.

The existing price-only test increases timber prices but does not exercise competing screw products.

**Change:** pin a screw/recipe selection in the approved build, or hash the resolved physical output, including selected fastener IDs, dimensions, machining recipes and relevant generator/recipe revision. Keep quote prices outside that record. If repricing really changes hardware or manufacturing instructions, it is not a price-only revision and must require renewed approval.

**Acceptance:** repricing cannot change any installed screw, machining operation or approved connection while leaving approval valid.

**Related lower-priority issue:** the hash includes all `Rules`, including spare percentage and price-age settings. A spare-percentage-only change invalidates the hash even though selected hardware is unchanged; the probe reproduces this too. Conversely, the hash does not include the physical generator version or resolved geometry, so changes in physical algorithms need an explicit version/hash policy.

## F03 / P1 — head-seat handling is warned about, not specified or enforced

**Locations:** `model.py::Screw`, `Fixing`; `geometry.py::make_fixing`; `planner.py::plan` (`head_seat_unmodeled`); viewer screw construction.

The hardware model still lacks head type, head dimensions, bearing-seat location, recess geometry, driver envelope and effective threaded engagement. The new head-seat message is explicitly non-blocking. A release can therefore succeed without a modelled or linked issued detail for an interface where the next course must sit over screw heads.

A note is an improvement in disclosure, not a physical solution. The exact default screw's seating behaviour must be confirmed rather than assumed to protrude or assumed to bury cleanly. Where a recess changes the bearing seat, the resulting shaft, tip and available timber geometry must be recalculated.

**Change:** add an approved joint/machining recipe and require it for affected interfaces. Either model the seating detail or make an explicitly reviewed, versioned supplementary detail a required part of the issued pack. The animation must show that same detail; it must not hide a protruding head merely to make the next course appear flush.

**Acceptance:** no issued sequence can place the next member over unresolved head geometry. Changes to the seat update penetration, collisions, machining depths and the approved build hash.

## F04 / P1 — demonstration evidence is text, not an enforced evidence type

**Locations:** `config.py::parse_screw`; `catalogues/wickes-reviewed-2026-09-06.json`; `planner.py::plan`; demo test in `tests/test_config_costs.py`.

For `pilot` or `none`, `parse_screw` requires a non-empty evidence string. The explicit text `DEMONSTRATION PLACEHOLDER - NOT REAL EVIDENCE` meets that requirement. The release checks do not distinguish a fixture from a manufacturer instruction or a recorded trial. The new test verifies the presence of warning words, not that demonstration data cannot produce an issued status once a matching approval hash is supplied.

**Change:** model evidence kind and provenance separately, for example `fixture`, `manufacturer_instruction`, `recorded_trial`, with the applicable hardware/joint/material, record ID and reviewer where relevant. Normal release must refuse fixtures. Fixture-only testing should not generate a real-looking issued status or publishable customer pack. This does not mean software can independently certify the truth of a human's trial; it means it can reject known test data.

**Acceptance:** the distributed demonstration catalogue cannot issue a real workshop plan, even with a correct copied hash.

## F05 / P2 — check and release disagree about missing approval

**Locations:** `planner.py::plan` (`elif approval is None and release`); `cli.py::main`.

A missing approval hash becomes a blocker only when `release=True`. With the other fields populated, a normal draft/check run can report `review_gate_clear=True` and exit 0, while release of the same job fails for the missing hash.

**Change:** calculate one full release-readiness result in all modes. Drafting may still export a valid draft, but it must report the same outstanding blockers. Release should decide whether those blockers prevent output, not whether they exist.

**Acceptance:** absent approval produces `release_ready=False` in a draft, a non-clear check result, and release refusal. Preserve a separate geometry-valid status for useful draft work.

## F06 / P1 product gap — neither viewer implements the requested assembly process

**Locations:** `site/app.js::buildSceneFromPlan`, `renderFrame`; `tools/viewer.py::generate_viewer_html`; `model.py`.

The main site places every timber solid and screw cylinder in its final position. Its animation frame loop updates camera controls and redraws the scene; it does not advance a construction timeline. Cylinders have no screw heads or drill features. Since their shafts are inside opaque timber, much of the fixing information is hidden.

The legacy viewer offers a useful course-explode slider and screw lines. That is a different, partly duplicated viewer, not a drill/cut/drive sequence. It drops receiver, pilot and detailed hardware information when converting CSV rows into its embedded scene data.

Missing capabilities include raw-stock cut stages, preconditions, drill approach and withdrawal, persistent holes, screw approach/insertion, clamping, tool changes, step selection, scrubbing and deliberate close-up cameras.

**Change:** keep the Three.js viewer and introduce a deterministic operation model. Drive the player and PDF steps from it. Use transparent or sectioned receiving timber for a drilling close-up and restore ordinary timber for the assembled view. Preserve IDs on scene objects so the active step can select the actual part and fixing.

**Acceptance:** one real modelled fixing can be followed from labelled stock to prepared joint, verified drilling operation, insertion and seated screw; then the same mechanism handles every fixing in every configured height.

## F07 / P2 — instruction order is duplicated and already inconsistent

**Locations:** `drawing.py::process_scene`; `export.py::build_notes`, `manual_notes`; `pdf.py::write_options_pdf`; `site/index.html`.

The process drawing says “Drill and drive” at step 5, then “Assemble course-by-course” at step 6. Other instructions say to assemble/clamp a course before fixing. Pre-drilling individual parts can be valid; driving into an absent receiver is not. The current prose does not encode that distinction.

Multiple templates separately write their own process. They will drift further when head preparation, supports or product-specific drilling is added. Some generic 7 mm pilot advisory text is emitted for all jobs, even though the catalogue accepts other diameters. It is labelled trial context, but should not appear as a generic fallback near an exact drilling schedule.

**Change:** generate descriptions and step numbering from typed operations and dependencies. Treat through-member preparation, receiver drilling and joint driving as distinct operations where the approved recipe requires them. Remove uncited, product-agnostic pilot-number suggestions from issued instructions.

**Acceptance:** every drive operation depends on the required members being placed and clamped and on all required preparation being complete. All output formats show the same ordering and requirements.

## F08 / P2 — one pilot setting per SKU cannot describe every joint

**Locations:** `model.py::Screw`; `geometry.py::make_fixing`; `drawing.py::fastener_scene`.

A catalogue screw has only a single pilot diameter and depth, copied to every fixing. This cannot express a different through-member bore, receiver pilot, approved head recess or operation-specific depth reference. The same screw could be used in multiple connection geometries.

`fastener_scene` groups solely by screw ID and takes its first fixing's through thickness and penetration as the representative section. That is only valid when all uses of the SKU share those properties. For a supported catalogue/profile extension where the same length serves different joint geometries, the diagram can describe one use as if it represents all uses.

**Change:** separate product properties from `JointRecipe` and per-fixing `MachiningOperation`. Group explanatory cards by recipe/geometry, not only screw SKU. Dimensions should identify whether depth is measured from the untouched outer face, approved seat or receiver face. Do not infer pilot diameter from nominal screw diameter.

**Acceptance:** one SKU used in two different valid recipes produces two correct preparation descriptions and sections, rather than inheriting the first one's values.

## F09 / P2 — parts pagination still produces tiny printed labels

**Locations:** `drawing.py::parts_scene`, `stock_scene`; `pdf.py::SceneFlow` in both PDF writers; `export.py::_populate`.

The renderer scales the whole vector scene to at most 770 × 525 points. With two fastener types (one row of fastener cards), a 12-part board has scene height 960 and its nominal 12-unit labels print at about **6.56 pt**. An 18-part page is 1140 units high and those labels print at about **5.53 pt**. These values were reproduced from the source arithmetic.

The stock-arrival board remains unpaginated. At 20 boards its 14-unit labels print at about **4.45 pt**. The separate SVG parts export still calls the unpaginated variant. Text widths are not measured before insertion into fixed columns.

**Change:** design in final page units, impose a minimum physical text size, and paginate by available page area. Separate the tool/hardware overview from repeated part tables so every continuation page does not carry a large header. Apply equivalent pagination rules to all intended printable formats.

**Acceptance:** workshop-critical text remains at an agreed minimum print size (recommend 9–10 pt minimum, larger for action instructions); no table/label overlap for maximum-length IDs and representative maximum-size batches. Do not pass the test simply by shrinking a complete scene.

## F10 / P2 — fixing callouts do not explain vertical drilling

**Locations:** `drawing.py::piece_scene`, `fastener_scene`.

Zoom callouts still select only the first three fixings, prioritising corners. A mixed corner/stack piece can therefore use all three bubbles on corners, leaving no stack example. In a stack-only example, the direction graphic reads `dx, dy, _`; a vertical direction `(0, 0, -1)` becomes a zero-length line in that calculation. The circular mark remains, but there is no explanatory view of the drilling direction/depth.

The current fastener section draws receiving material only for the nominal penetration distance. It should distinguish penetration depth from total receiving-member size so the illustration does not imply that the tip is at a real free edge.

**Change:** choose representative callouts per operation/recipe and draw a genuine local section or an explicit into-page symbol as appropriate. Show the bit, head seat, mating plane, receiver continuation and depth datum. Use a separate magnified instructional view rather than treating a larger dot as a drilled-hole explanation.

**Acceptance:** every distinct preparation/drive operation used in the plan has a readable detail, with a non-ambiguous direction and depth reference.

## F11 / P2 — high-DPI resize condition does not converge

**Location:** `site/app.js::renderFrame`.

After `setPixelRatio`, `canvas.width` and `canvas.height` are backing-buffer pixels, while `clientWidth` and `clientHeight` are CSS pixels. The frame loop compares these directly, so at DPR 2 it can call `setSize` and update the projection every frame despite no layout change. The supplied arithmetic probe reproduces 60 resize requests over 60 static frames. This is not a measured FPS or battery benchmark.

**Change:** track CSS dimensions and DPR separately, or use a resize observer and update only when either changes. Guard zero dimensions. Once a step player exists, stop continuous rendering while idle unless camera damping or an active animation requires it.

**Acceptance:** a static DPR-2 view does not repeatedly resize its drawing buffer; resizing/orientation changes still update the projection correctly.

## F12 / P2 — batch beds overlap in the main viewer

**Locations:** `site/app.js::buildSceneFromPlan`, `populateClientPanel`; `geometry.py::compile_geometry`; contrast `drawing.py::scad_model`.

The engine deliberately uses a separate local origin per bed. The main viewer adds every piece at its local coordinates in one scene without a per-bed display transform. Batch beds therefore overlap. Its metrics show `beds[0]` dimensions but a job-level cost. The supplied offer views contain one bed, so this is a supported-input extension problem, not a claim that the present offer demo contains overlapping beds.

OpenSCAD already applies per-bed display offsets, illustrating the missing adaptation in the web viewer.

**Change:** add explicit per-bed display groups/transforms, or restrict the viewer to one selected bed and clearly identify job totals separately. Display transforms must not alter manufacturing coordinates.

**Acceptance:** a three-bed fixture shows distinct beds and correctly scoped dimensions, counts and costs.

## F13 / P2 — the quality report is an inventory check, not visual validation

**Locations:** `export.py::_quality_report`; `tests/test_cli_exports.py`.

The report checks heading presence, expected drawing counts and callouts inferred from the fixing data. It does not inspect the rendered output. The PDF tests check a PDF header and repeatable bytes; the test named `test_options_pdf_covers_each_height` does not actually inspect per-height content.

**Change:** keep deterministic-output tests, but name them accurately and add semantic/visual checks: required operation coverage, correct labels and counts, minimum printed font size, no clipping, no overlaps, expected per-height sections and consistent build identities. Add browser tests for viewer controls and final animation transforms.

**Acceptance:** removing a drilling step, making a label unreadably small or mixing a manifest with the wrong plan causes a test failure.

## F14 / P3 — secondary viewer and export hardening

**Locations:** `site/app.js::clearGroup`, `loadManifestFromUrl`; `tools/viewer.py::generate_viewer_html`; comparison PDF overview.

- `clearGroup` disposes only immediate geometries. Timber meshes contain nested `EdgesGeometry` objects that are not explicitly disposed when offers are switched. Remove objects using the scene API and recursively dispose owned geometries; keep shared materials alive until application teardown.
- The main viewer does not validate the manifest schema or compare its plan hash to the loaded plan. A generic draft footnote exists in the HTML, but the panel does not expose the plan's actual unresolved blockers. Keep that footnote, add explicit status/blockers, and reject mismatched bundles.
- The legacy HTML generator interpolates the configurable plan title without HTML escaping. Treat incoming job/CSV values as untrusted in a public workflow; escape HTML and make embedded JSON safe for script contexts. This is a conditional injection exposure, not a finding that the current title contains malicious content.
- The combined options PDF mixes first-bed dimensions with whole-job counts/costs for multi-bed inputs. Make batch versus per-bed scope explicit.
- Two independent viewers and several prose-generating functions multiply maintenance work. Consolidate around one plan adapter and operation model rather than expanding both implementations.

---

# Recommended implementation

## 1. Keep the physical planner, add operations

Use a small typed model, not a new general-purpose framework. Suggested ownership:

| Module | Responsibility |
|---|---|
| `model.py` | Product, piece, joint, evidence and operation records |
| `machining.py` | Approved preparation/seat/receiver operations per joint |
| `assembly.py` | Ordered operations, dependencies and step grouping |
| `validation.py` or a small extension of `planner.py` | One readiness result and resolved build identity |
| `drawing.py` | Technical diagrams and instructional keyframes |
| `pdf.py` | Fixed-size page layout over the shared operations |
| `site/assembly-player.js` | Deterministic play/pause/step/scrub state |
| `site/scene-adapter.js` | Piece/fixing/tool objects and display-only transforms |

Do not split tiny concerns into dozens of services. These can begin as a few dataclasses and pure functions.

A useful operation has: unique ID; action type; stock, part and fixing IDs; dependency IDs; entry face and coordinate reference; axis; confirmed diameter/depth/seat parameters where applicable; tool/recipe/evidence IDs; before/after state; close-up camera hint; and a short instruction key. Unknown physical values remain unknown and block issued machining instructions.

Core actions include receive/inspect, label, cut, treat cut end, place, clamp, square/level check, drill, prepare seat, drive, inspect seat, add reviewed supports, and final check. Not every recipe requires every drilling operation.

## 2. First working sequence

Build one source-driven sequence for the current 2400 × 1400 long-through draft:

1. Select the one-, two- or three-course variant and show its scope/status.
2. Show each original stock board, labelled datum and required finished piece.
3. Show each cutting band's actual start/end, with keep/waste sides clearly identified.
4. Label the finished member and treat the cut end under the applicable instruction.
5. Place and clamp the first corner's two actual members.
6. Mark the exact centre, then display the recipe's preparation operations in order.
7. Show the screw outside the timber, aligned with the approved axis, then inserting and seating.
8. Repeat through all other required fixings, with a per-step count and the active fixing ID.
9. Add further courses only after the preceding interfaces are ready, using their own staggered coordinates.
10. Show the approved restraint/drainage detail before an issued pack depicts final filling.

The current first-model file is a draft, not a surveyed neighbour design. Its long-through variant and the older alternating-corner neighbour example must have separate expected counts and layouts; do not conflate their 56- and 52-fixing three-course patterns.

## 3. Deterministic animation

Each displayed state should be a pure function of **plan + operation ID + progress**. Seeking backwards or taking a PDF keyframe must produce the same geometry without depending on how many animation frames have previously run.

For a screw with known under-bearing length `L`, insertion direction `d`, final approved bearing point `E` and approach gap `g`, a simple insertion phase can place the head at:

`head(u) = E - d * (L + g) * (1 - u)`, for `0 <= u <= 1`.

The tip is `head(u) + d * L`; the shaft centre is `head(u) + d * L/2`. At the final frame this must agree with the approved geometric model. If `E` is a recessed bearing point, it must be derived from the actual approved preparation, not substituted to hide a seating problem. Product length conventions need to be explicit.

Pilot progress uses its approved drill depth, not the screw length. Provide local section/ghost timber when necessary to show what is happening. Thread rotation is illustrative unless genuine pitch/turn data is available; do not present an arbitrary spin as a validated installation setting.

No generative imagery is needed for dimensioned construction geometry. Use rendered or vector keyframes from the model. A PDF can use clean vector diagrams while the browser uses 3D meshes, provided both consume the same operation data and assertions.

## 4. Manual layout

Split the customer-friendly assembly guide from the dense workshop schedule, but bind both to the same revision. The visual guide should show one action per panel: active part/tool in colour, already-installed parts subdued, clear arrows, a small orientation thumbnail and a short sentence. Show where to clamp, the correct entry face, the depth datum, waste side and completion check.

Use a dedicated joint close-up rather than a whole-bed image to explain drilling. A magnified section should show the mating plane, preparation bore(s), head seat and tip within the full receiver. A repeated-operation count is useful only when the actual locations and details are equivalent; provide a location map for the other instances. Keep IDs and labels consistent with the physical kit.

Critical measurements belong on the relevant panel, not only in a distant CSV. Do not print a pseudo-1:1 jig without a verified physical scale and calibration marks. Do not silently round away a distinction needed by the approved machining tolerance.

## 5. Acceptance tests before calling it ready

- Repricing cannot silently select new hardware under an old approval.
- Fixtures and missing head/recipe details cannot produce an issued status.
- Draft/check/release share one complete readiness calculation.
- Every fixing has exactly one drive operation; required drill/seat tasks precede it.
- No drive occurs before the named through and receiving members are positioned and clamped.
- Final player positions agree with the plan's approved shaft/head/tip coordinates.
- Drilling uses its own diameter, depth and datum, including changes between recipes.
- All cuts conserve stock, kerf, trim and offcuts; visual blade bands use the same coordinates as the cutting list.
- One-, two- and three-course long-through and alternating variants are tested separately.
- Manifest, plan, CSVs, PDFs and animation share a validated resolved build identity.
- Printable pages pass minimum-font, clipping, overlap and required-content checks.
- High-DPI resizing converges; switching offers disposes old owned geometry.
- Batch views separate bed-local frames without altering manufacturing coordinates.
- Every issued support/head detail is included or explicitly linked and revision-controlled; unresolved detail is not replaced by a reassuring picture.

## Suggested order

**First:** quarantine stale approved outputs and repair evidence/hash/readiness handling.  
**Second:** specify one complete joint recipe with the actual hardware and timber; model head seating and tool preparation.  
**Third:** compile and animate one truthful corner sequence, including drilling and screw insertion.  
**Fourth:** extend to the whole bed and all heights; drive manual pages from the same operations.  
**Fifth:** add browser and print-layout acceptance tests, then publish a controlled draft/customer bundle.

The next milestone is not a nicer full-bed render. It is **one correct corner, explained completely**, whose data can scale to every corner, stack fixing, cut and manual page.

---

# Sources

All paths below are pinned to the reviewed commit; repository source is the primary evidence.

- Repository: https://github.com/iiko38/sleeperplan/tree/37db13b378fc868f2d4e6b73f8ba19f6e5f4b526
- CI run: https://github.com/iiko38/sleeperplan/actions/runs/34240224252
- PDF CI job: https://github.com/iiko38/sleeperplan/actions/runs/34240224252/job/102108179881
- Planner/hash/gates: https://github.com/iiko38/sleeperplan/blob/37db13b378fc868f2d4e6b73f8ba19f6e5f4b526/sleeperplan/planner.py
- Configuration/evidence: https://github.com/iiko38/sleeperplan/blob/37db13b378fc868f2d4e6b73f8ba19f6e5f4b526/sleeperplan/config.py
- Domain records: https://github.com/iiko38/sleeperplan/blob/37db13b378fc868f2d4e6b73f8ba19f6e5f4b526/sleeperplan/model.py
- Geometry/selection: https://github.com/iiko38/sleeperplan/blob/37db13b378fc868f2d4e6b73f8ba19f6e5f4b526/sleeperplan/geometry.py
- Cutting: https://github.com/iiko38/sleeperplan/blob/37db13b378fc868f2d4e6b73f8ba19f6e5f4b526/sleeperplan/cutting.py
- Export/quality: https://github.com/iiko38/sleeperplan/blob/37db13b378fc868f2d4e6b73f8ba19f6e5f4b526/sleeperplan/export.py
- Drawing: https://github.com/iiko38/sleeperplan/blob/37db13b378fc868f2d4e6b73f8ba19f6e5f4b526/sleeperplan/drawing.py
- PDF: https://github.com/iiko38/sleeperplan/blob/37db13b378fc868f2d4e6b73f8ba19f6e5f4b526/sleeperplan/pdf.py
- CLI: https://github.com/iiko38/sleeperplan/blob/37db13b378fc868f2d4e6b73f8ba19f6e5f4b526/sleeperplan/cli.py
- Main viewer: https://github.com/iiko38/sleeperplan/blob/37db13b378fc868f2d4e6b73f8ba19f6e5f4b526/site/app.js
- Main page: https://github.com/iiko38/sleeperplan/blob/37db13b378fc868f2d4e6b73f8ba19f6e5f4b526/site/index.html
- Legacy viewer: https://github.com/iiko38/sleeperplan/blob/37db13b378fc868f2d4e6b73f8ba19f6e5f4b526/tools/viewer.py
- Source demonstration catalogue: https://github.com/iiko38/sleeperplan/blob/37db13b378fc868f2d4e6b73f8ba19f6e5f4b526/catalogues/wickes-reviewed-2026-09-06.json
- Stale reviewed output: https://github.com/iiko38/sleeperplan/blob/37db13b378fc868f2d4e6b73f8ba19f6e5f4b526/build/reviewed/BUILD.md
- Current offer example: https://github.com/iiko38/sleeperplan/blob/37db13b378fc868f2d4e6b73f8ba19f6e5f4b526/examples/first-model-2400x1400.json
- Tests: https://github.com/iiko38/sleeperplan/tree/37db13b378fc868f2d4e6b73f8ba19f6e5f4b526/tests

All implementation proposals and acceptance thresholds in this review are recommendations, not claims that the current code already implements them or that a physical kit is certified.

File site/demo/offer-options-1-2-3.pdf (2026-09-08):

Sleeperplan | bff3700ad86b | DRAFT_MARK_OUT_ONLY | height options | 1

# SLEEPERPLAN / HEIGHT OPTIONS & BUILD GUIDE

## First rectangular bed draft - 2400 x 1400

As of 2026-09-06 | Generator 0.4.0 | Status DRAFT_MARK_OUT_ONLY
Independent alternatives at the same footprint: each option is planned from the same starting inventory and none consumes another. Purchases are not cumulative across options. Until the review gates are recorded, every option remains a draft for mark-out, not a build permission.
OPTION | OUTSIDE L x W x H (mm) | COURSES | PIECES | FIXINGS | SLEEPERS | SAW CUTS | TIMBER + SCREWS
1 course | 2400 x 1400 x 200 | 1 | 4 | 8 | 4 | 2 | GBP 113.00
2 courses | 2400 x 1400 x 400 | 2 | 8 | 32 | 8 | 4 | GBP 229.30
3 courses | 2400 x 1400 x 600 | 3 | 12 | 56 | 12 | 6 | GBP 354.60

How to read this pack: the option pages that follow give the build sequence, the assembled view, one plan page per course, the cutting diagram and the process/parts boards for that height. Full per-piece drilling coordinates stay in each option's own workshop.pdf and fixings.csv inside this compare folder.
Fill volumes are geometric cavity measures to the stated freeboard, without settlement or compaction allowances. Pilot entries marked UNCONFIRMED are mark-out only and are never a drilling instruction.

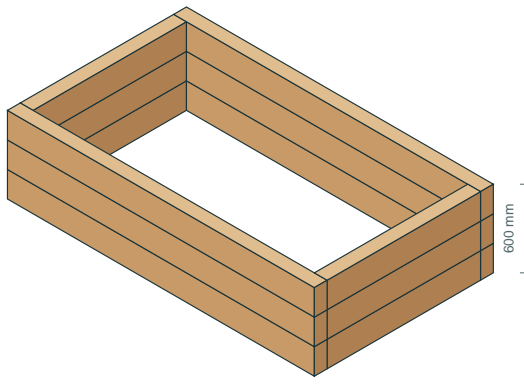
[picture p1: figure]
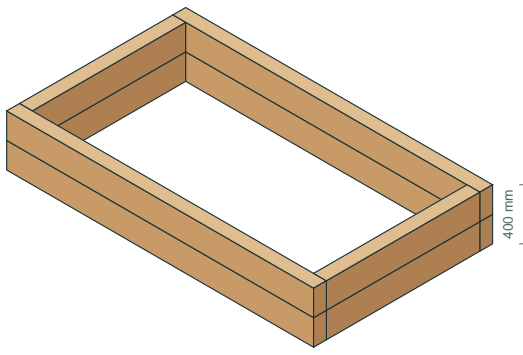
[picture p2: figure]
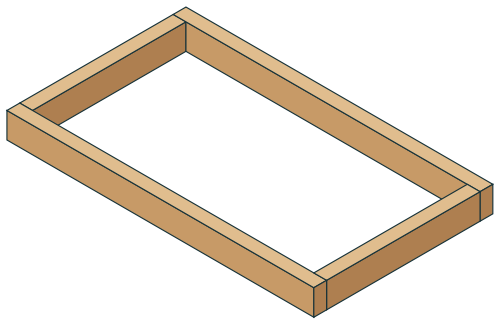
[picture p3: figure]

Sleeperplan | bff3700ad86b | DRAFT_MARK_OUT_ONLY | height options | 2

first-bed / height alternatives at the SAME scale

Draft alternatives, not cumulative purchases. Timber orientation and outside footprint are unchanged. 200 mm

### 1 course / 200 mm high

2400 x 1400 mm outside / 396 litres fill

### 2 courses / 400 mm high

2400 x 1400 mm outside / 924 litres fill

### 3 courses / 600 mm high

2400 x 1400 mm outside / 1452 litres fill

Sleeperplan | bff3700ad86b | DRAFT_MARK_OUT_ONLY | height options | 3

# OPTION 1 - 200 mm OUTSIDE HEIGHT (1 COURSE)

4 labelled pieces | 8 fixing entries | 4 purchased sleepers | 2 saw cuts | cutting exact | timber + screws GBP 113.00

Long-through corners: the same pair of sides passes through the corner on every course; follow each course page exactly.
Build sequence for this option:
1. Survey the footprint and access; confirm a level base and an open drainage path before any ground work.
2. Inspect and measure the timber; measure the real saw kerf with a test cut and set end trims before regenerating if they differ.
3. Cut stock exactly as the cutting pages show. Each kerf_start..kerf_end band is waste; coordinates run from the ORIGINAL stock datum A.
4. Label every produced piece with its ID and keep the A / TOP / OUTER orientation from the stock board.
5. Assemble course 1 square and level. Corner screws enter the OUTER side face of the through member, never its cut end.
6. Add each further course using its own plan page. Stack screws enter vertically through the TOP and are staggered against the course below.
7. Pilots: where the schedule says UNCONFIRMED, stop and confirm diameter/depth evidence before drilling. This is a hard stop, not advice.
8. Fit the separately reviewed supports, liner and drainage details, then fill to the stated freeboard and record actual purchases and offcuts.

Full per-piece drilling sheets for this option: 1-courses/workshop.pdf with cuts.csv and fixings.csv in the same folder.

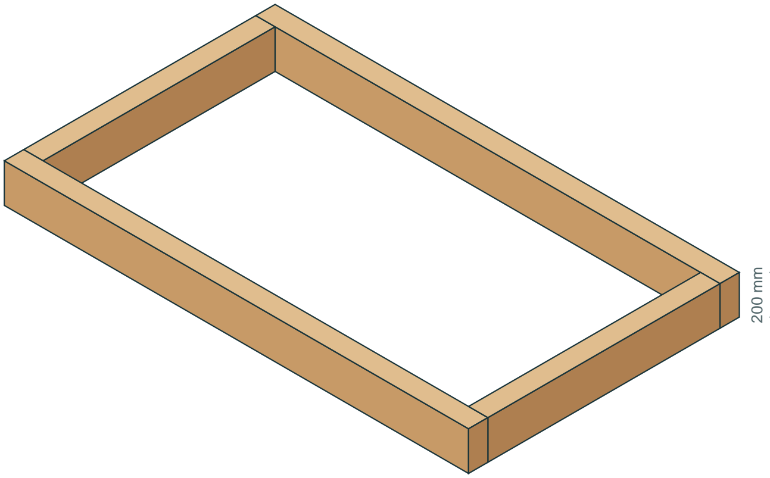
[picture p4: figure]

Sleeperplan | bff3700ad86b | DRAFT_MARK_OUT_ONLY | height options | 4

# first-bed-01 / 1 courses / assembled view

DRAFT_MARK_OUT_ONLY | Same timber section throughout | Schematic colour, not a finish sample

## Outside: 2400 x 1400 x 200 mm | Clear opening: 2200 x 1200 mm

Geometric fill: 396 litres at 50 mm below the top. No settlement allowance.

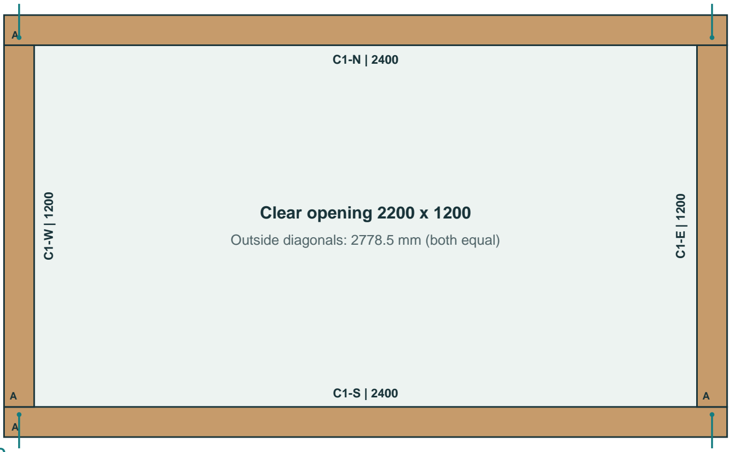
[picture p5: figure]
Clear opening 2200 x 1200

Sleeperplan | bff3700ad86b | DRAFT_MARK_OUT_ONLY | height options | 5

# first-bed-01 / course 1 / plan view

DRAFT_MARK_OUT_ONLY | All dimensions mm | Origin O = outside S/W corner | NOT a 1:1 template

### Outside 2400

Outside 1400

### Outside diagonals: 2778.5 mm (both equal)

O S / +X runs left to right; +Y runs towards N

Circles = top fixing entries. Arrows = two corner screws at different heights.
Piece sheets give the entry face, datum, coordinates and hardware. A is each piece's lower-X / lower-Y end.

Sleeperplan | bff3700ad86b | DRAFT_MARK_OUT_ONLY | height options | 6

# Stock allocation / cutting diagram

Measure every kerf band from ORIGINAL stock datum A. Finished pieces are exact; this drawing is NOT to scale for tracing.

### B001 | wickes-276785 | 2400 mm | 0 saw cuts | offcut 0 mm

first-bed-01-C1-N

2400

A

Waste kerf bands from original A (mm): none - use the sound full length

### B002 | wickes-276785 | 2400 mm | 0 saw cuts | offcut 0 mm

first-bed-01-C1-S

2400

A

Waste kerf bands from original A (mm): none - use the sound full length

### B003 | wickes-256948 | 1800 mm | 1 saw cuts | offcut 597 mm

first-bed-01-C1-E

1200

A

Waste kerf bands from original A (mm): 1200..1203

### B004 | wickes-256948 | 1800 mm | 1 saw cuts | offcut 597 mm

first-bed-01-C1-W

1200

A

Waste kerf bands from original A (mm): 1200..1203

Exact saw band positions and blade-centre coordinates are in cuts.csv. Kerf widths here may be exaggerated for visibility.

Sleeperplan | bff3700ad86b | DRAFT_MARK_OUT_ONLY | height options | 7

# Workshop process / script-driven sequence

DRAFT_MARK_OUT_ONLY | Follow these steps with BUILD.md, cuts.csv and fixings.csv
1. Receive and inspect timber stock; reject twisted/split members.
2. Label each stock board Bxx and mark datum A before any cut.
3. Execute cuts.csv in sequence; kerf_start..kerf_end is waste band.
4. Re-label produced parts and preserve A / TOP / OUTER orientation.
5. Drill and drive by piece fixing sheets (exact U, V, W coordinates).
6. Assemble course-by-course using per-course plan sheets.

CORRECT

Check entry face, direction arrow and quantity before each action.

INCORRECT

Never drill or drive when pilot_mode is UNCONFIRMED.

All positions, lengths and hardware IDs are generated from plan geometry; do not freehand from screenshots.

Sleeperplan | bff3700ad86b | DRAFT_MARK_OUT_ONLY | height options | 8

# Parts and fixings board / visual checklist

DRAFT_MARK_OUT_ONLY | Verify quantity and ID before each step

TOOLS / HANDLING

[2x] two people for long/heavy members
[CHECK] confirm A/TOP/OUTER labels [STOP] resolve blockers before drilling Hammer + driver/bit set + square/level FASTENERS

wickes-287686

7 x 150 mm
Need 8 entries

Pilot UNCONFIRMED

TIMBER PARTS

PIECE ID | BED | COURSE | SIDE | LENGTH | SECTION | BOARD | A DATUM
first-bed-01-C1-E first-bed-01 | 1 | E | 1200 | 100x200 | B003 | Lower X/Y end
first-bed-01-C1-N first-bed-01 | 1 | N | 2400 | 100x200 | B001 | Lower X/Y end
first-bed-01-C1-S first-bed-01 | 1 | S | 2400 | 100x200 | B002 | Lower X/Y end
first-bed-01-C1-W first-bed-01 | 1 | W | 1200 | 100x200 | B004 | Lower X/Y end

Use this board as the pre-flight checklist. Exact cut order and coordinates remain in cuts.csv and fixings.csv.

Sleeperplan | bff3700ad86b | DRAFT_MARK_OUT_ONLY | height options | 9

# Stock arrival, board IDs and datum A

Label before cutting; keep original A datum for every stock item

B001 | wickes-276785 | gross 2400 mm

A

2400 mm
B002 | wickes-276785 | gross 2400 mm

A

2400 mm
B003 | wickes-256948 | gross 1800 mm

A

1800 mm
B004 | wickes-256948 | gross 1800 mm

A

1800 mm

Use these B IDs in parts.csv and cuts.csv. Datum A in cut coordinates always refers to original stock, not the finished part.

Sleeperplan | bff3700ad86b | DRAFT_MARK_OUT_ONLY | height options | 10

# OPTION 2 - 400 mm OUTSIDE HEIGHT (2 COURSES)

8 labelled pieces | 32 fixing entries | 8 purchased sleepers | 4 saw cuts | cutting exact | timber + screws GBP 229.30

Long-through corners: the same pair of sides passes through the corner on every course; follow each course page exactly.
Build sequence for this option:
1. Survey the footprint and access; confirm a level base and an open drainage path before any ground work.
2. Inspect and measure the timber; measure the real saw kerf with a test cut and set end trims before regenerating if they differ.
3. Cut stock exactly as the cutting pages show. Each kerf_start..kerf_end band is waste; coordinates run from the ORIGINAL stock datum A.
4. Label every produced piece with its ID and keep the A / TOP / OUTER orientation from the stock board.
5. Assemble course 1 square and level. Corner screws enter the OUTER side face of the through member, never its cut end.
6. Add each further course using its own plan page. Stack screws enter vertically through the TOP and are staggered against the course below.
7. Pilots: where the schedule says UNCONFIRMED, stop and confirm diameter/depth evidence before drilling. This is a hard stop, not advice.
8. Fit the separately reviewed supports, liner and drainage details, then fill to the stated freeboard and record actual purchases and offcuts.

Full per-piece drilling sheets for this option: 2-courses/workshop.pdf with cuts.csv and fixings.csv in the same folder.

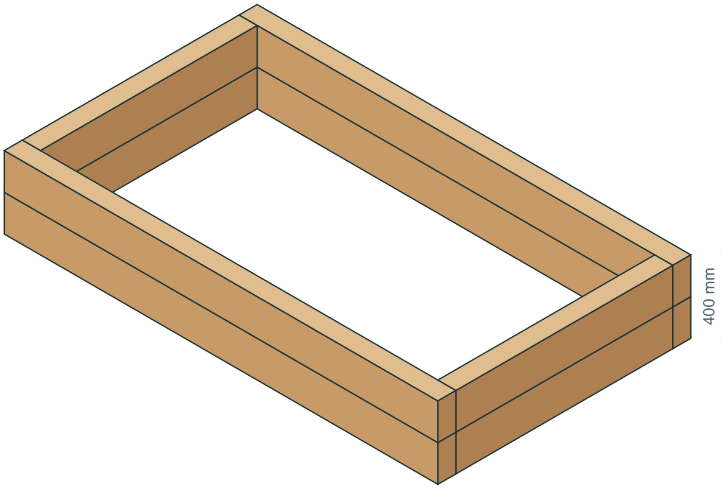
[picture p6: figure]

Sleeperplan | bff3700ad86b | DRAFT_MARK_OUT_ONLY | height options | 11

# first-bed-01 / 2 courses / assembled view

DRAFT_MARK_OUT_ONLY | Same timber section throughout | Schematic colour, not a finish sample

## Outside: 2400 x 1400 x 400 mm | Clear opening: 2200 x 1200 mm

Geometric fill: 924 litres at 50 mm below the top. No settlement allowance.

Sleeperplan | bff3700ad86b | DRAFT_MARK_OUT_ONLY | height options | 12

# first-bed-01 / course 1 / plan view

DRAFT_MARK_OUT_ONLY | All dimensions mm | Origin O = outside S/W corner | NOT a 1:1 template

### Outside 2400

Outside 1400

### Outside diagonals: 2778.5 mm (both equal)

O S / +X runs left to right; +Y runs towards N

Circles = top fixing entries. Arrows = two corner screws at different heights.
Piece sheets give the entry face, datum, coordinates and hardware. A is each piece's lower-X / lower-Y end.

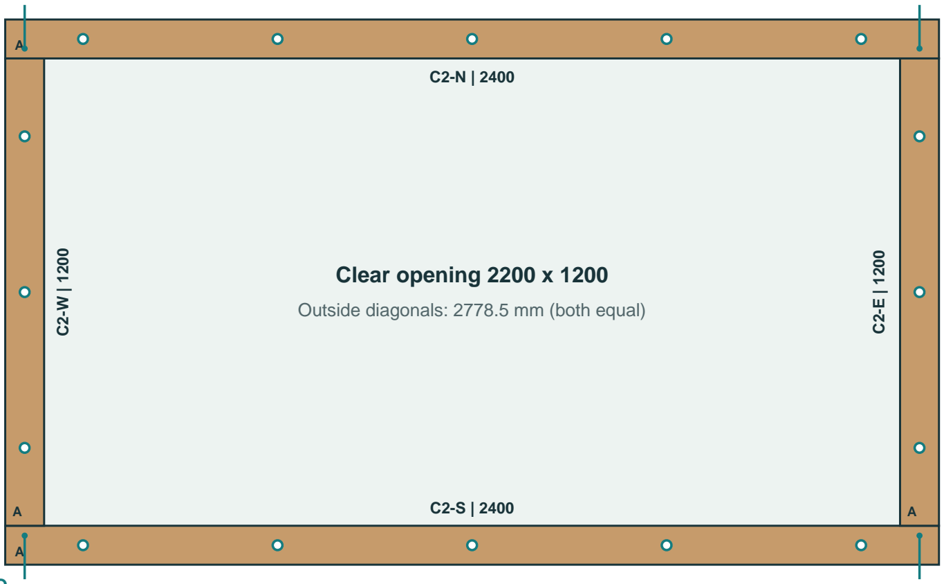
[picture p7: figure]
Clear opening 2200 x 1200

Sleeperplan | bff3700ad86b | DRAFT_MARK_OUT_ONLY | height options | 13

# first-bed-01 / course 2 / plan view

DRAFT_MARK_OUT_ONLY | All dimensions mm | Origin O = outside S/W corner | NOT a 1:1 template

### Outside 2400

Outside 1400

### Outside diagonals: 2778.5 mm (both equal)

O S / +X runs left to right; +Y runs towards N

Circles = top fixing entries. Arrows = two corner screws at different heights.
Piece sheets give the entry face, datum, coordinates and hardware. A is each piece's lower-X / lower-Y end.

Sleeperplan | bff3700ad86b | DRAFT_MARK_OUT_ONLY | height options | 14

# Stock allocation / cutting diagram

Measure every kerf band from ORIGINAL stock datum A. Finished pieces are exact; this drawing is NOT to scale for tracing.

### B001 | wickes-276785 | 2400 mm | 0 saw cuts | offcut 0 mm

first-bed-01-C1-N

2400

A

Waste kerf bands from original A (mm): none - use the sound full length

### B002 | wickes-276785 | 2400 mm | 0 saw cuts | offcut 0 mm

first-bed-01-C1-S

2400

A

Waste kerf bands from original A (mm): none - use the sound full length

### B003 | wickes-276785 | 2400 mm | 0 saw cuts | offcut 0 mm

first-bed-01-C2-N

2400

A

Waste kerf bands from original A (mm): none - use the sound full length

### B004 | wickes-276785 | 2400 mm | 0 saw cuts | offcut 0 mm

first-bed-01-C2-S

2400

A

Waste kerf bands from original A (mm): none - use the sound full length

### B005 | wickes-256948 | 1800 mm | 1 saw cuts | offcut 597 mm

first-bed-01-C1-E

1200

A

Waste kerf bands from original A (mm): 1200..1203

Exact saw band positions and blade-centre coordinates are in cuts.csv. Kerf widths here may be exaggerated for visibility.

Sleeperplan | bff3700ad86b | DRAFT_MARK_OUT_ONLY | height options | 15

# Stock allocation / cutting diagram

Measure every kerf band from ORIGINAL stock datum A. Finished pieces are exact; this drawing is NOT to scale for tracing.

### B006 | wickes-256948 | 1800 mm | 1 saw cuts | offcut 597 mm

first-bed-01-C1-W

1200

A

Waste kerf bands from original A (mm): 1200..1203

### B007 | wickes-256948 | 1800 mm | 1 saw cuts | offcut 597 mm

first-bed-01-C2-E

1200

A

Waste kerf bands from original A (mm): 1200..1203

### B008 | wickes-256948 | 1800 mm | 1 saw cuts | offcut 597 mm

first-bed-01-C2-W

1200

A

Waste kerf bands from original A (mm): 1200..1203

Exact saw band positions and blade-centre coordinates are in cuts.csv. Kerf widths here may be exaggerated for visibility.

Sleeperplan | bff3700ad86b | DRAFT_MARK_OUT_ONLY | height options | 16

# Workshop process / script-driven sequence

DRAFT_MARK_OUT_ONLY | Follow these steps with BUILD.md, cuts.csv and fixings.csv
1. Receive and inspect timber stock; reject twisted/split members.
2. Label each stock board Bxx and mark datum A before any cut.
3. Execute cuts.csv in sequence; kerf_start..kerf_end is waste band.
4. Re-label produced parts and preserve A / TOP / OUTER orientation.
5. Drill and drive by piece fixing sheets (exact U, V, W coordinates).
6. Assemble course-by-course using per-course plan sheets.

CORRECT

Check entry face, direction arrow and quantity before each action.

INCORRECT

Never drill or drive when pilot_mode is UNCONFIRMED.

All positions, lengths and hardware IDs are generated from plan geometry; do not freehand from screenshots.

Sleeperplan | bff3700ad86b | DRAFT_MARK_OUT_ONLY | height options | 17

# Parts and fixings board / visual checklist

DRAFT_MARK_OUT_ONLY | Verify quantity and ID before each step

TOOLS / HANDLING

[2x] two people for long/heavy members
[CHECK] confirm A/TOP/OUTER labels [STOP] resolve blockers before drilling Hammer + driver/bit set + square/level FASTENERS

wickes-287686

7 x 150 mm
Need 16 entries

Pilot UNCONFIRMED

wickes-287688

7 x 250 mm
Need 16 entries

Pilot UNCONFIRMED

TIMBER PARTS

PIECE ID | BED | COURSE | SIDE | LENGTH | SECTION | BOARD | A DATUM
first-bed-01-C1-E first-bed-01 | 1 | E | 1200 | 100x200 | B005 | Lower X/Y end
first-bed-01-C1-N first-bed-01 | 1 | N | 2400 | 100x200 | B001 | Lower X/Y end
first-bed-01-C1-S first-bed-01 | 1 | S | 2400 | 100x200 | B002 | Lower X/Y end
first-bed-01-C1-W first-bed-01 | 1 | W | 1200 | 100x200 | B006 | Lower X/Y end
first-bed-01-C2-E first-bed-01 | 2 | E | 1200 | 100x200 | B007 | Lower X/Y end
first-bed-01-C2-N first-bed-01 | 2 | N | 2400 | 100x200 | B003 | Lower X/Y end
first-bed-01-C2-S first-bed-01 | 2 | S | 2400 | 100x200 | B004 | Lower X/Y end
first-bed-01-C2-W first-bed-01 | 2 | W | 1200 | 100x200 | B008 | Lower X/Y end

Use this board as the pre-flight checklist. Exact cut order and coordinates remain in cuts.csv and fixings.csv.

Sleeperplan | bff3700ad86b | DRAFT_MARK_OUT_ONLY | height options | 18

# Stock arrival, board IDs and datum A

Label before cutting; keep original A datum for every stock item

B001 | wickes-276785 | gross 2400 mm

A

2400 mm
B002 | wickes-276785 | gross 2400 mm

A

2400 mm
B003 | wickes-276785 | gross 2400 mm

A

2400 mm
B004 | wickes-276785 | gross 2400 mm

A

2400 mm
B005 | wickes-256948 | gross 1800 mm

A

1800 mm
B006 | wickes-256948 | gross 1800 mm

A

1800 mm
B007 | wickes-256948 | gross 1800 mm

A

1800 mm
B008 | wickes-256948 | gross 1800 mm

A

1800 mm

Use these B IDs in parts.csv and cuts.csv. Datum A in cut coordinates always refers to original stock, not the finished part.

Sleeperplan | bff3700ad86b | DRAFT_MARK_OUT_ONLY | height options | 19

# OPTION 3 - 600 mm OUTSIDE HEIGHT (3 COURSES)

12 labelled pieces | 56 fixing entries | 12 purchased sleepers | 6 saw cuts | cutting exact | timber + screws GBP 354.60

Long-through corners: the same pair of sides passes through the corner on every course; follow each course page exactly.
Build sequence for this option:
1. Survey the footprint and access; confirm a level base and an open drainage path before any ground work.
2. Inspect and measure the timber; measure the real saw kerf with a test cut and set end trims before regenerating if they differ.
3. Cut stock exactly as the cutting pages show. Each kerf_start..kerf_end band is waste; coordinates run from the ORIGINAL stock datum A.
4. Label every produced piece with its ID and keep the A / TOP / OUTER orientation from the stock board.
5. Assemble course 1 square and level. Corner screws enter the OUTER side face of the through member, never its cut end.
6. Add each further course using its own plan page. Stack screws enter vertically through the TOP and are staggered against the course below.
7. Pilots: where the schedule says UNCONFIRMED, stop and confirm diameter/depth evidence before drilling. This is a hard stop, not advice.
8. Fit the separately reviewed supports, liner and drainage details, then fill to the stated freeboard and record actual purchases and offcuts.

Full per-piece drilling sheets for this option: 3-courses/workshop.pdf with cuts.csv and fixings.csv in the same folder.

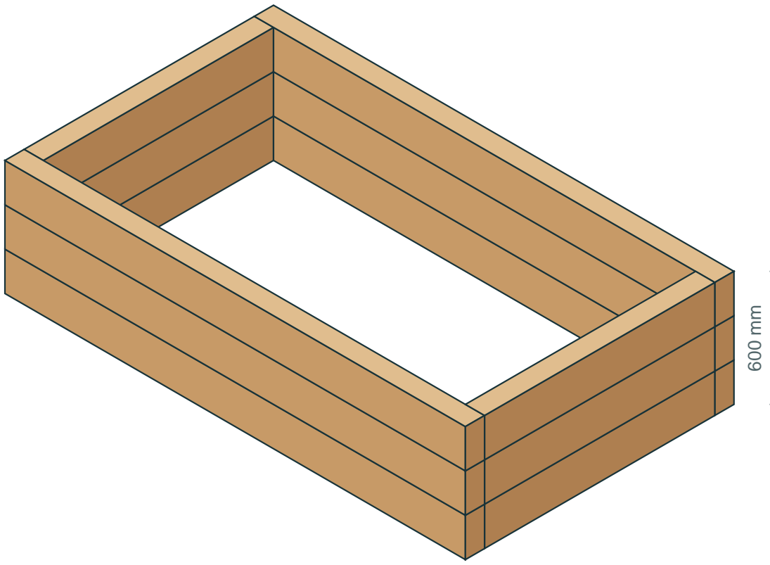
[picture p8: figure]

Sleeperplan | bff3700ad86b | DRAFT_MARK_OUT_ONLY | height options | 20

# first-bed-01 / 3 courses / assembled view

DRAFT_MARK_OUT_ONLY | Same timber section throughout | Schematic colour, not a finish sample

## Outside: 2400 x 1400 x 600 mm | Clear opening: 2200 x 1200 mm

Geometric fill: 1452 litres at 50 mm below the top. No settlement allowance.

Sleeperplan | bff3700ad86b | DRAFT_MARK_OUT_ONLY | height options | 21

# first-bed-01 / course 1 / plan view

DRAFT_MARK_OUT_ONLY | All dimensions mm | Origin O = outside S/W corner | NOT a 1:1 template

### Outside 2400

Outside 1400

### Outside diagonals: 2778.5 mm (both equal)

O S / +X runs left to right; +Y runs towards N

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

Sleeperplan | bff3700ad86b | DRAFT_MARK_OUT_ONLY | height options | 22

# first-bed-01 / course 2 / plan view

DRAFT_MARK_OUT_ONLY | All dimensions mm | Origin O = outside S/W corner | NOT a 1:1 template

### Outside 2400

Outside 1400

### Outside diagonals: 2778.5 mm (both equal)

O S / +X runs left to right; +Y runs towards N

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

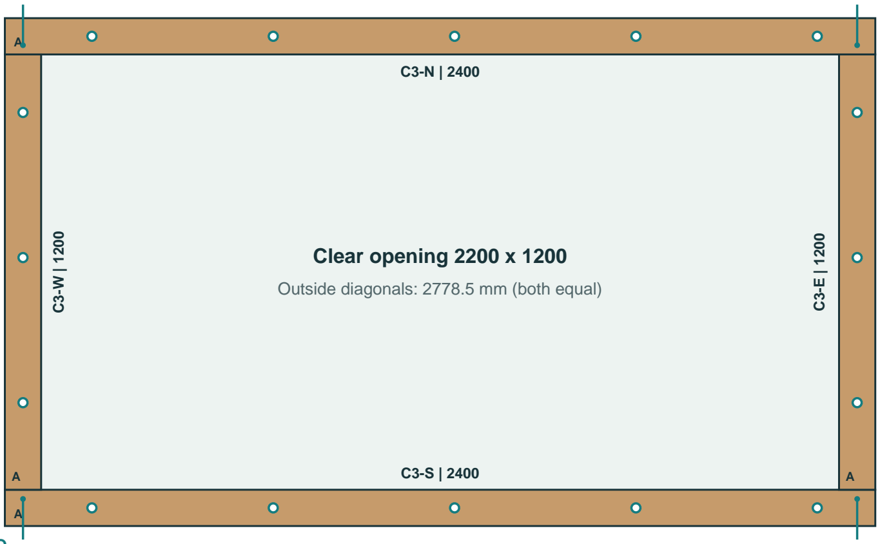
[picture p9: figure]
Clear opening 2200 x 1200

Sleeperplan | bff3700ad86b | DRAFT_MARK_OUT_ONLY | height options | 23

# first-bed-01 / course 3 / plan view

DRAFT_MARK_OUT_ONLY | All dimensions mm | Origin O = outside S/W corner | NOT a 1:1 template

### Outside 2400

Outside 1400

### Outside diagonals: 2778.5 mm (both equal)

O S / +X runs left to right; +Y runs towards N

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

Sleeperplan | bff3700ad86b | DRAFT_MARK_OUT_ONLY | height options | 24

# Stock allocation / cutting diagram

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

### B001 | wickes-276785 | 2400 mm | 0 saw cuts | offcut 0 mm

first-bed-01-C1-N

2400

A

Waste kerf bands from original A (mm): none - use the sound full length

### B002 | wickes-276785 | 2400 mm | 0 saw cuts | offcut 0 mm

first-bed-01-C1-S

2400

A

Waste kerf bands from original A (mm): none - use the sound full length

### B003 | wickes-276785 | 2400 mm | 0 saw cuts | offcut 0 mm

first-bed-01-C2-N

2400

A

Waste kerf bands from original A (mm): none - use the sound full length

### B004 | wickes-276785 | 2400 mm | 0 saw cuts | offcut 0 mm

first-bed-01-C2-S

2400

A

Waste kerf bands from original A (mm): none - use the sound full length

### B005 | wickes-276785 | 2400 mm | 0 saw cuts | offcut 0 mm

first-bed-01-C3-N

2400

A

Waste kerf bands from original A (mm): none - use the sound full length

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

Sleeperplan | bff3700ad86b | DRAFT_MARK_OUT_ONLY | height options | 25

# Stock allocation / cutting diagram

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

### B006 | wickes-276785 | 2400 mm | 0 saw cuts | offcut 0 mm

first-bed-01-C3-S

2400

A

Waste kerf bands from original A (mm): none - use the sound full length

### B007 | wickes-256948 | 1800 mm | 1 saw cuts | offcut 597 mm

first-bed-01-C1-E

1200

A

Waste kerf bands from original A (mm): 1200..1203

### B008 | wickes-256948 | 1800 mm | 1 saw cuts | offcut 597 mm

first-bed-01-C1-W

1200

A

Waste kerf bands from original A (mm): 1200..1203

### B009 | wickes-256948 | 1800 mm | 1 saw cuts | offcut 597 mm

first-bed-01-C2-E

1200

A

Waste kerf bands from original A (mm): 1200..1203

### B010 | wickes-256948 | 1800 mm | 1 saw cuts | offcut 597 mm

first-bed-01-C2-W

1200

A

Waste kerf bands from original A (mm): 1200..1203

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

Sleeperplan | bff3700ad86b | DRAFT_MARK_OUT_ONLY | height options | 26

# Stock allocation / cutting diagram

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

### B011 | wickes-256948 | 1800 mm | 1 saw cuts | offcut 597 mm

first-bed-01-C3-E

1200

A

Waste kerf bands from original A (mm): 1200..1203

### B012 | wickes-256948 | 1800 mm | 1 saw cuts | offcut 597 mm

first-bed-01-C3-W

1200

A

Waste kerf bands from original A (mm): 1200..1203

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

Sleeperplan | bff3700ad86b | DRAFT_MARK_OUT_ONLY | height options | 27

# Workshop process / script-driven sequence

DRAFT_MARK_OUT_ONLY | Follow these steps with BUILD.md, cuts.csv and fixings.csv
1. Receive and inspect timber stock; reject twisted/split members.
2. Label each stock board Bxx and mark datum A before any cut.
3. Execute cuts.csv in sequence; kerf_start..kerf_end is waste band.
4. Re-label produced parts and preserve A / TOP / OUTER orientation.
5. Drill and drive by piece fixing sheets (exact U, V, W coordinates).
6. Assemble course-by-course using per-course plan sheets.

CORRECT

Check entry face, direction arrow and quantity before each action.

INCORRECT

Never drill or drive when pilot_mode is UNCONFIRMED.

All positions, lengths and hardware IDs are generated from plan geometry; do not freehand from screenshots.

Sleeperplan | bff3700ad86b | DRAFT_MARK_OUT_ONLY | height options | 28

## Parts and fixings board / visual checklist (page 1 of 2)

DRAFT_MARK_OUT_ONLY | Verify quantity and ID before each step

TOOLS / HANDLING

[2x] two people for long/heavy members
[CHECK] confirm A/TOP/OUTER labels [STOP] resolve blockers before drilling Hammer + driver/bit set + square/level

FASTENERS

wickes-287686

7 x 150 mm
Need 24 entries

Pilot UNCONFIRMED

wickes-287688

7 x 250 mm
Need 32 entries

Pilot UNCONFIRMED

TIMBER PARTS

PIECE ID | BED | COURSE | SIDE | LENGTH | SECTION | BOARD | A DATUM
first-bed-01-C1-E first-bed-01 | 1 | E | 1200 | 100x200 | B007 | Lower X/Y end
first-bed-01-C1-N first-bed-01 | 1 | N | 2400 | 100x200 | B001 | Lower X/Y end
first-bed-01-C1-S first-bed-01 | 1 | S | 2400 | 100x200 | B002 | Lower X/Y end
first-bed-01-C1-W first-bed-01 | 1 | W | 1200 | 100x200 | B008 | Lower X/Y end
first-bed-01-C2-E first-bed-01 | 2 | E | 1200 | 100x200 | B009 | Lower X/Y end
first-bed-01-C2-N first-bed-01 | 2 | N | 2400 | 100x200 | B003 | Lower X/Y end
first-bed-01-C2-S first-bed-01 | 2 | S | 2400 | 100x200 | B004 | Lower X/Y end
first-bed-01-C2-W first-bed-01 | 2 | W | 1200 | 100x200 | B010 | Lower X/Y end
first-bed-01-C3-E first-bed-01 | 3 | E | 1200 | 100x200 | B011 | Lower X/Y end
first-bed-01-C3-N first-bed-01 | 3 | N | 2400 | 100x200 | B005 | Lower X/Y end

Use this board as the pre-flight checklist. Exact cut order and coordinates remain in cuts.csv and fixings.csv.

Sleeperplan | bff3700ad86b | DRAFT_MARK_OUT_ONLY | height options | 29

# Parts and fixings board / visual checklist (page 2 of 2)

DRAFT_MARK_OUT_ONLY | Verify quantity and ID before each step
TIMBER PARTS (continued)
PIECE ID | BED | COURSE | SIDE | LENGTH | SECTION | BOARD | A DATUM
first-bed-01-C3-S first-bed-01 | 3 | S | 2400 | 100x200 | B006 | Lower X/Y end
first-bed-01-C3-W first-bed-01 | 3 | W | 1200 | 100x200 | B012 | Lower X/Y end

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

Sleeperplan | bff3700ad86b | DRAFT_MARK_OUT_ONLY | height options | 30

# Stock arrival, board IDs and datum A (page 1 of 2)

Label before cutting; keep original A datum for every stock item

B001 | wickes-276785 | gross 2400 mm

A

2400 mm
B002 | wickes-276785 | gross 2400 mm

A

2400 mm
B003 | wickes-276785 | gross 2400 mm

A

2400 mm
B004 | wickes-276785 | gross 2400 mm

A

2400 mm
B005 | wickes-276785 | gross 2400 mm

A

2400 mm
B006 | wickes-276785 | gross 2400 mm

A

2400 mm
B007 | wickes-256948 | gross 1800 mm

A

1800 mm
B008 | wickes-256948 | gross 1800 mm

A

1800 mm

Use these B IDs in parts.csv and cuts.csv. Datum A in cut coordinates always refers to original stock, not the finished part.

Sleeperplan | bff3700ad86b | DRAFT_MARK_OUT_ONLY | height options | 31

# Stock arrival, board IDs and datum A (page 2 of 2)

Label before cutting; keep original A datum for every stock item

B009 | wickes-256948 | gross 1800 mm

A

1800 mm
B010 | wickes-256948 | gross 1800 mm

A

1800 mm
B011 | wickes-256948 | gross 1800 mm

A

1800 mm
B012 | wickes-256948 | gross 1800 mm

A

1800 mm

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

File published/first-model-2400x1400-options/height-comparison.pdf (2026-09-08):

## first-bed / height alternatives at the SAME scale

Draft alternatives, not cumulative purchases. Timber orientation and outside footprint are unchanged. 200 mm

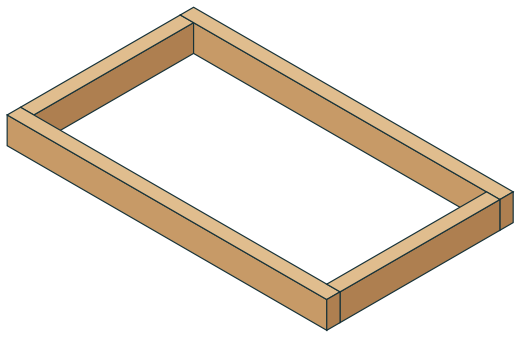
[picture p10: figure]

## 1 course / 200 mm high

2400 x 1400 mm outside / 396 litres fill

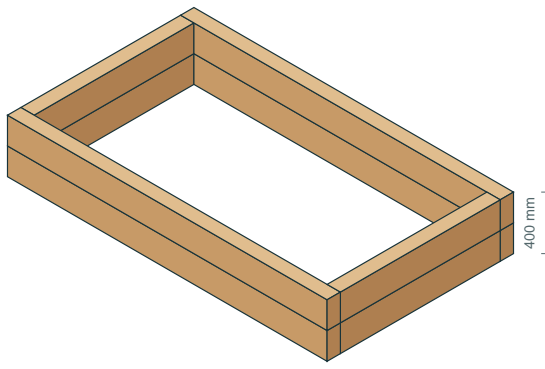
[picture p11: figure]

## 2 courses / 400 mm high

2400 x 1400 mm outside / 924 litres fill

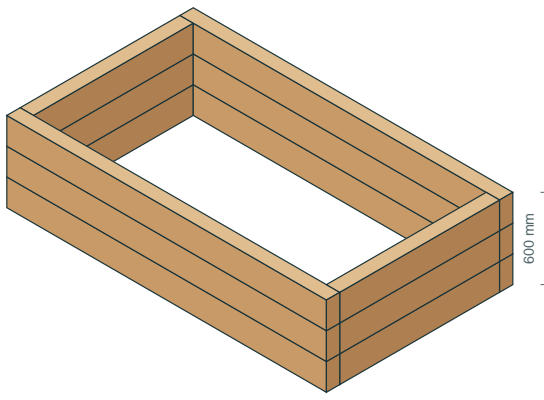
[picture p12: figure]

## 3 courses / 600 mm high

2400 x 1400 mm outside / 1452 litres fill

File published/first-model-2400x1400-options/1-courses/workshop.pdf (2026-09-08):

Sleeperplan | bff3700ad86b | DRAFT_MARK_OUT_ONLY | 1

# SLEEPERPLAN / WORKSHOP PACK

### DRAFT_MARK_OUT_ONLY

## First rectangular bed draft - 2400 x 1400

As of 2026-09-06 | Generator 0.4.0 | Plan bff3700ad86be666
Worked example unless your own surveyed job file has been used. A reviewed status records human checks; it is not structural certification.
BED | OUTSIDE L x W x H (mm) | COURSES | CLEAR OPENING (mm) | FILL (litres)
first-bed-01 | 2400 x 1400 x 200 | 1 | 2200 x 1200 | 396.0

### 4 labelled pieces | 8 fixing entries | 4 purchased sleepers | 2 saw cuts

Timber + screw purchases: GBP 113.00
Known subtotal: GBP 113.00. NOT a completed job cost. Unpriced items remain.
Cutting: exact. All explored cutting patterns and inventory states solved.
Use BUILD.md for the assembly sequence. Use cuts.csv for saw bands and fixings.csv for full coordinates. Treat all pilot entries marked UNCONFIRMED as mark-out only, not a drilling instruction.

# REVIEW GATES & ASSUMPTIONS

TYPE | CHECK
BLOCKER | Measure actual stock length/section, usable ends and saw kerf; update inputs before cutting.
BLOCKER | Review foundations, drainage, soil loads, support/bracing and any buried services on site.
BLOCKER | Review screw suitability, end-grain connections, penetration and spacing with a competent builder / supplier.
BLOCKER | Record reviewer, reviewed_on and review notes before releasing a workshop pack.
BLOCKER | Release readiness requires review.approved_physical_design_hash to equal the current physical design hash, so an edited job cannot inherit an old review. Run a draft plan, then copy the printed physical design hash into the job's review block after a genuine physical review.
BLOCKER | wickes-287686: fixing centres are mark-out only. Confirm pilot diameter/depth or a manufacturer-supported no-pilot instruction; none is inferred.
NOTE | first-bed-01: centre reach is approximately 700 mm from 2 accessible side(s); confirm with the user. 650 mm is a planning prompt, not an accessibility standard.
NOTE | Zero end trim assumes square, sound, usable factory/cut ends. Nominal 2400 mm is not a measurement.
NOTE | Known subtotal only; unpriced: consumables, fill, liner, preservative, site_preparation, supports, transport, labour
NOTE | Catalogue prices are dated snapshots. The configured store and collection stock are NOT confirmed.
NOTE | Geometry and straight screw-path clearance are checked; timber strength, screw capacity, long-term movement and soil pressure are NOT calculated. Supports/bracing, liner detailing and foundations are site-specific and not drawn by v1.

# PURCHASES & COSTS

Catalogue retail purchase prices as displayed; VAT is not recalculated. Explicit extras and labour are added on the same user-supplied basis. Not a tax invoice.

ITEM | NEED / BUY | LINE TOTAL
wickes-256948 - 1800 mm sleeper / matching section | 2 needed / 2 sleeper | GBP 48.00
wickes-276785 - 2400 mm sleeper / matching section | 2 needed / 2 sleeper | GBP 56.00
wickes-287686 - 7 x 150 mm screws; 25/pack | 8 needed / 1 pack | GBP 9.00
consumables - Drill bits, blades, PPE and other consumables | 1 needed / 1 job | UNPRICED
fill - Soil / compost / mulch supply | 1 needed / 1 job | UNPRICED
liner - Liner / protection and attachment (or explicitly not required) | 1 needed / 1 job | UNPRICED
preservative - Compatible cut-end preservative | 1 needed / 1 job | UNPRICED
site_preparation - Ground preparation / bedding / disposal | 1 needed / 1 job | UNPRICED
supports - Site-specific stakes, bracing, brackets and their fixings | 1 needed / 1 job | UNPRICED
transport - Collection / delivery / travel | 1 needed / 1 job | UNPRICED
labour - Labour (nearest penny, half-up) | UNCONFIRMED | UNPRICED

### Known subtotal: GBP 113.00

# Parts and fixings board / visual checklist

DRAFT_MARK_OUT_ONLY | Verify quantity and ID before each step

TOOLS / HANDLING

[2x] two people for long/heavy members
[CHECK] confirm A/TOP/OUTER labels [STOP] resolve blockers before drilling Hammer + driver/bit set + square/level FASTENERS

wickes-287686

7 x 150 mm
Need 8 entries

Pilot UNCONFIRMED

TIMBER PARTS

PIECE ID | BED | COURSE | SIDE | LENGTH | SECTION | BOARD | A DATUM
first-bed-01-C1-E first-bed-01 | 1 | E | 1200 | 100x200 | B003 | Lower X/Y end
first-bed-01-C1-N first-bed-01 | 1 | N | 2400 | 100x200 | B001 | Lower X/Y end
first-bed-01-C1-S first-bed-01 | 1 | S | 2400 | 100x200 | B002 | Lower X/Y end
first-bed-01-C1-W first-bed-01 | 1 | W | 1200 | 100x200 | B004 | Lower X/Y end

Use this board as the pre-flight checklist. Exact cut order and coordinates remain in cuts.csv and fixings.csv.

# Workshop process / script-driven sequence

DRAFT_MARK_OUT_ONLY | Follow these steps with BUILD.md, cuts.csv and fixings.csv
1. Receive and inspect timber stock; reject twisted/split members.
2. Label each stock board Bxx and mark datum A before any cut.
3. Execute cuts.csv in sequence; kerf_start..kerf_end is waste band.
4. Re-label produced parts and preserve A / TOP / OUTER orientation.
5. Drill and drive by piece fixing sheets (exact U, V, W coordinates).
6. Assemble course-by-course using per-course plan sheets.

CORRECT

Check entry face, direction arrow and quantity before each action.

INCORRECT

Never drill or drive when pilot_mode is UNCONFIRMED.

All positions, lengths and hardware IDs are generated from plan geometry; do not freehand from screenshots.
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

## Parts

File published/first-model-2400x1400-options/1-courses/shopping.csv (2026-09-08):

id | category | description | needed | buy_quantity | unit | spares | unit_price_pence | line_pence | source_url | price_checked_on | note
wickes-256948 | timber | 1800 mm sleeper / matching section | 2 | 2 | sleeper | 0 | 2400 | 4800 | https://www.wickes.co.uk/Wickes-UC4-Incised-Light-Green-Garden-Sleeper---100-x-200-x-1800mm/p/256948 | 2026-09-06
wickes-276785 | timber | 2400 mm sleeper / matching section | 2 | 2 | sleeper | 0 | 2800 | 5600 | https://www.wickes.co.uk/Wickes-UC4-Incised-Light-Green-Garden-Sleeper---100-x-200-x-2400mm/p/276785 | 2026-09-06
wickes-287686 | screws | 7 x 150 mm screws; 25/pack | 8 | 1 | pack | 17 | 900 | 900 | https://www.wickes.co.uk/Wickes-Timber-Drive-Washer-Head-Screws---7-x-150mm---Pack-of-25/p/287686 | 2026-09-06
consumables | extra | Drill bits, blades, PPE and other consumables | 1 | 1 | job | 0
fill | extra | Soil / compost / mulch supply | 1 | 1 | job | 0
liner | extra | Liner / protection and attachment (or explicitly not required) | 1 | 1 | job | 0
preservative | extra | Compatible cut-end preservative | 1 | 1 | job | 0
site_preparation | extra | Ground preparation / bedding / disposal | 1 | 1 | job | 0
supports | extra | Site-specific stakes, bracing, brackets and their fixings | 1 | 1 | job | 0
transport | extra | Collection / delivery / travel | 1 | 1 | job | 0
labour | labour | Labour (nearest penny, half-up) |  |  | minute | 0

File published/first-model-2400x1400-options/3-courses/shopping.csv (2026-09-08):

id | category | description | needed | buy_quantity | unit | spares | unit_price_pence | line_pence | source_url | price_checked_on | note
wickes-256948 | timber | 1800 mm sleeper / matching section | 6 | 6 | sleeper | 0 | 2400 | 14400 | https://www.wickes.co.uk/Wickes-UC4-Incised-Light-Green-Garden-Sleeper---100-x-200-x-1800mm/p/256948 | 2026-09-06
wickes-276785 | timber | 2400 mm sleeper / matching section | 6 | 6 | sleeper | 0 | 2800 | 16800 | https://www.wickes.co.uk/Wickes-UC4-Incised-Light-Green-Garden-Sleeper---100-x-200-x-2400mm/p/276785 | 2026-09-06
wickes-287686 | screws | 7 x 150 mm screws; 25/pack | 24 | 2 | pack | 26 | 900 | 1800 | https://www.wickes.co.uk/Wickes-Timber-Drive-Washer-Head-Screws---7-x-150mm---Pack-of-25/p/287686 | 2026-09-06
wickes-287688 | screws | 7 x 250 mm screws; 25/pack | 32 | 2 | pack | 18 | 1230 | 2460 | https://www.wickes.co.uk/Wickes-Timber-Drive-Washer-Head-Screws---7-x-250mm---Pack-of-25/p/287688 | 2026-09-06
consumables | extra | Drill bits, blades, PPE and other consumables | 1 | 1 | job | 0
fill | extra | Soil / compost / mulch supply | 1 | 1 | job | 0
liner | extra | Liner / protection and attachment (or explicitly not required) | 1 | 1 | job | 0
preservative | extra | Compatible cut-end preservative | 1 | 1 | job | 0
site_preparation | extra | Ground preparation / bedding / disposal | 1 | 1 | job | 0
supports | extra | Site-specific stakes, bracing, brackets and their fixings | 1 | 1 | job | 0
transport | extra | Collection / delivery / travel | 1 | 1 | job | 0
labour | labour | Labour (nearest penny, half-up) |  |  | minute | 0

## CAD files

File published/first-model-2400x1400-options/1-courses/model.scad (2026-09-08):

// Generated from plan.json; millimetres. Not a structural design.
// Open in OpenSCAD. Increase explode_mm to inspect courses.
explode_mm = 0;
$fn = 24;
show_fixing_paths = false;

// first-bed-01-C1-S
translate([0, 0, 0+0*explode_mm])
  color([0.70,0.52,0.33]) cube([2400, 100, 200]);
// first-bed-01-C1-N
translate([0, 1300, 0+0*explode_mm])
  color([0.70,0.52,0.33]) cube([2400, 100, 200]);
// first-bed-01-C1-W
translate([0, 100, 0+0*explode_mm])
  color([0.70,0.52,0.33]) cube([100, 1200, 200]);
// first-bed-01-C1-E
translate([2300, 100, 0+0*explode_mm])
  color([0.70,0.52,0.33]) cube([100, 1200, 200]);
if (show_fixing_paths) translate([50.0, 1400, 50.0+0*explode_mm]) rotate([90,0,0]) color([0.8,0.1,0.1]) cylinder(d=7, h=150);
if (show_fixing_paths) translate([50.0, 1400, 150.0+0*explode_mm]) rotate([90,0,0]) color([0.8,0.1,0.1]) cylinder(d=7, h=150);
if (show_fixing_paths) translate([2350.0, 1400, 50.0+0*explode_mm]) rotate([90,0,0]) color([0.8,0.1,0.1]) cylinder(d=7, h=150);
if (show_fixing_paths) translate([2350.0, 1400, 150.0+0*explode_mm]) rotate([90,0,0]) color([0.8,0.1,0.1]) cylinder(d=7, h=150);
if (show_fixing_paths) translate([50.0, 0, 50.0+0*explode_mm]) rotate([-90,0,0]) color([0.8,0.1,0.1]) cylinder(d=7, h=150);
if (show_fixing_paths) translate([50.0, 0, 150.0+0*explode_mm]) rotate([-90,0,0]) color([0.8,0.1,0.1]) cylinder(d=7, h=150);
if (show_fixing_paths) translate([2350.0, 0, 50.0+0*explode_mm]) rotate([-90,0,0]) color([0.8,0.1,0.1]) cylinder(d=7, h=150);
if (show_fixing_paths) translate([2350.0, 0, 150.0+0*explode_mm]) rotate([-90,0,0]) color([0.8,0.1,0.1]) cylinder(d=7, h=150);

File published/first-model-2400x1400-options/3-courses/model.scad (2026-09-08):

// Generated from plan.json; millimetres. Not a structural design.
// Open in OpenSCAD. Increase explode_mm to inspect courses.
explode_mm = 0;
$fn = 24;
show_fixing_paths = false;

// first-bed-01-C1-S
translate([0, 0, 0+0*explode_mm])
  color([0.70,0.52,0.33]) cube([2400, 100, 200]);
// first-bed-01-C1-N
translate([0, 1300, 0+0*explode_mm])
  color([0.70,0.52,0.33]) cube([2400, 100, 200]);
// first-bed-01-C1-W
translate([0, 100, 0+0*explode_mm])
  color([0.70,0.52,0.33]) cube([100, 1200, 200]);
// first-bed-01-C1-E
translate([2300, 100, 0+0*explode_mm])
  color([0.70,0.52,0.33]) cube([100, 1200, 200]);
// first-bed-01-C2-S
translate([0, 0, 200+1*explode_mm])
  color([0.70,0.52,0.33]) cube([2400, 100, 200]);
// first-bed-01-C2-N
translate([0, 1300, 200+1*explode_mm])
  color([0.70,0.52,0.33]) cube([2400, 100, 200]);
// first-bed-01-C2-W
translate([0, 100, 200+1*explode_mm])
  color([0.70,0.52,0.33]) cube([100, 1200, 200]);
// first-bed-01-C2-E
translate([2300, 100, 200+1*explode_mm])
  color([0.70,0.52,0.33]) cube([100, 1200, 200]);
// first-bed-01-C3-S
translate([0, 0, 400+2*explode_mm])
  color([0.70,0.52,0.33]) cube([2400, 100, 200]);
// first-bed-01-C3-N
translate([0, 1300, 400+2*explode_mm])
  color([0.70,0.52,0.33]) cube([2400, 100, 200]);
// first-bed-01-C3-W
translate([0, 100, 400+2*explode_mm])
  color([0.70,0.52,0.33]) cube([100, 1200, 200]);
// first-bed-01-C3-E
translate([2300, 100, 400+2*explode_mm])
  color([0.70,0.52,0.33]) cube([100, 1200, 200]);
if (show_fixing_paths) translate([50.0, 1400, 50.0+0*explode_mm]) rotate([90,0,0]) color([0.8,0.1,0.1]) cylinder(d=7, h=150);
if (show_fixing_paths) translate([50.0, 1400, 150.0+0*explode_mm]) rotate([90,0,0]) color([0.8,0.1,0.1]) cylinder(d=7, h=150);
if (show_fixing_paths) translate([2350.0, 1400, 50.0+0*explode_mm]) rotate([90,0,0]) color([0.8,0.1,0.1]) cylinder(d=7, h=150);
if (show_fixing_paths) translate([2350.0, 1400, 150.0+0*explode_mm]) rotate([90,0,0]) color([0.8,0.1,0.1]) cylinder(d=7, h=150);
if (show_fixing_paths) translate([50.0, 0, 50.0+0*explode_mm]) rotate([-90,0,0]) color([0.8,0.1,0.1]) cylinder(d=7, h=150);
if (show_fixing_paths) translate([50.0, 0, 150.0+0*explode_mm]) rotate([-90,0,0]) color([0.8,0.1,0.1]) cylinder(d=7, h=150);
if (show_fixing_paths) translate([2350.0, 0, 50.0+0*explode_mm]) rotate([-90,0,0]) color([0.8,0.1,0.1]) cylinder(d=7, h=150);
if (show_fixing_paths) translate([2350.0, 0, 150.0+0*explode_mm]) rotate([-90,0,0]) color([0.8,0.1,0.1]) cylinder(d=7, h=150);
if (show_fixing_paths) translate([2350.0, 300.0, 400+1*explode_mm]) rotate([180,0,0]) color([0.8,0.1,0.1]) cylinder(d=7, h=250);
if (show_fixing_paths) translate([2350.0, 700.0, 400+1*explode_mm]) rotate([180,0,0]) color([0.8,0.1,0.1]) cylinder(d=7, h=250);
if (show_fixing_paths) translate([2350.0, 1100.0, 400+1*explode_mm]) rotate([180,0,0]) color([0.8,0.1,0.1]) cylinder(d=7, h=250);
if (show_fixing_paths) translate([50.0, 1400, 250.0+1*explode_mm]) rotate([90,0,0]) color([0.8,0.1,0.1]) cylinder(d=7, h=150);
if (show_fixing_paths) translate([50.0, 1400, 350.0+1*explode_mm]) rotate([90,0,0]) color([0.8,0.1,0.1]) cylinder(d=7, h=150);
if (show_fixing_paths) translate([2350.0, 1400, 250.0+1*explode_mm]) rotate([90,0,0]) color([0.8,0.1,0.1]) cylinder(d=7, h=150);
if (show_fixing_paths) translate([2350.0, 1400, 350.0+1*explode_mm]) rotate([90,0,0]) color([0.8,0.1,0.1]) cylinder(d=7, h=150);
if (show_fixing_paths) translate([200.0, 1350.0, 400+1*explode_mm]) rotate([180,0,0]) color([0.8,0.1,0.1]) cylinder(d=7, h=250);
if (show_fixing_paths) translate([700.0, 1350.0, 400+1*explode_mm]) rotate([180,0,0]) color([0.8,0.1,0.1]) cylinder(d=7, h=250);
if (show_fixing_paths) translate([1200.0, 1350.0, 400+1*explode_mm]) rotate([180,0,0]) color([0.8,0.1,0.1]) cylinder(d=7, h=250);
if (show_fixing_paths) translate([1700.0, 1350.0, 400+1*explode_mm]) rotate([180,0,0]) color([0.8,0.1,0.1]) cylinder(d=7, h=250);
if (show_fixing_paths) translate([2200.0, 1350.0, 400+1*explode_mm]) rotate([180,0,0]) color([0.8,0.1,0.1]) cylinder(d=7, h=250);
if (show_fixing_paths) translate([50.0, 0, 250.0+1*explode_mm]) rotate([-90,0,0]) color([0.8,0.1,0.1]) cylinder(d=7, h=150);
if (show_fixing_paths) translate([50.0, 0, 350.0+1*explode_mm]) rotate([-90,0,0]) color([0.8,0.1,0.1]) cylinder(d=7, h=150);
if (show_fixing_paths) translate([2350.0, 0, 250.0+1*explode_mm]) rotate([-90,0,0]) color([0.8,0.1,0.1]) cylinder(d=7, h=150);
if (show_fixing_paths) translate([2350.0, 0, 350.0+1*explode_mm]) rotate([-90,0,0]) color([0.8,0.1,0.1]) cylinder(d=7, h=150);
if (show_fixing_paths) translate([200.0, 50.0, 400+1*explode_mm]) rotate([180,0,0]) color([0.8,0.1,0.1]) cylinder(d=7, h=250);
if (show_fixing_paths) translate([700.0, 50.0, 400+1*explode_mm]) rotate([180,0,0]) color([0.8,0.1,0.1]) cylinder(d=7, h=250);
if (show_fixing_paths) translate([1200.0, 50.0, 400+1*explode_mm]) rotate([180,0,0]) color([0.8,0.1,0.1]) cylinder(d=7, h=250);
if (show_fixing_paths) translate([1700.0, 50.0, 400+1*explode_mm]) rotate([180,0,0]) color([0.8,0.1,0.1]) cylinder(d=7, h=250);
if (show_fixing_paths) translate([2200.0, 50.0, 400+1*explode_mm]) rotate([180,0,0]) color([0.8,0.1,0.1]) cylinder(d=7, h=250);
if (show_fixing_paths) translate([50.0, 300.0, 400+1*explode_mm]) rotate([180,0,0]) color([0.8,0.1,0.1]) cylinder(d=7, h=250);
if (show_fixing_paths) translate([50.0, 700.0, 400+1*explode_mm]) rotate([180,0,0]) color([0.8,0.1,0.1]) cylinder(d=7, h=250);
if (show_fixing_paths) translate([50.0, 1100.0, 400+1*explode_mm]) rotate([180,0,0]) color([0.8,0.1,0.1]) cylinder(d=7, h=250);
if (show_fixing_paths) translate([2350.0, 340.0, 600+2*explode_mm]) rotate([180,0,0]) color([0.8,0.1,0.1]) cylinder(d=7, h=250);
if (show_fixing_paths) translate([2350.0, 740.0, 600+2*explode_mm]) rotate([180,0,0]) color([0.8,0.1,0.1]) cylinder(d=7, h=250);
if (show_fixing_paths) translate([2350.0, 1140.0, 600+2*explode_mm]) rotate([180,0,0]) color([0.8,0.1,0.1]) cylinder(d=7, h=250);
if (show_fixing_paths) translate([50.0, 1400, 450.0+2*explode_mm]) rotate([90,0,0]) color([0.8,0.1,0.1]) cylinder(d=7, h=150);
if (show_fixing_paths) translate([50.0, 1400, 550.0+2*explode_mm]) rotate([90,0,0]) color([0.8,0.1,0.1]) cylinder(d=7, h=150);
if (show_fixing_paths) translate([2350.0, 1400, 450.0+2*explode_mm]) rotate([90,0,0]) color([0.8,0.1,0.1]) cylinder(d=7, h=150);
if (show_fixing_paths) translate([2350.0, 1400, 550.0+2*explode_mm]) rotate([90,0,0]) color([0.8,0.1,0.1]) cylinder(d=7, h=150);
if (show_fixing_paths) translate([240.0, 1350.0, 600+2*explode_mm]) rotate([180,0,0]) color([0.8,0.1,0.1]) cylinder(d=7, h=250);
if (show_fixing_paths) translate([740.0, 1350.0, 600+2*explode_mm]) rotate([180,0,0]) color([0.8,0.1,0.1]) cylinder(d=7, h=250);
if (show_fixing_paths) translate([1240.0, 1350.0, 600+2*explode_mm]) rotate([180,0,0]) color([0.8,0.1,0.1]) cylinder(d=7, h=250);
if (show_fixing_paths) translate([1740.0, 1350.0, 600+2*explode_mm]) rotate([180,0,0]) color([0.8,0.1,0.1]) cylinder(d=7, h=250);
if (show_fixing_paths) translate([2240.0, 1350.0, 600+2*explode_mm]) rotate([180,0,0]) color([0.8,0.1,0.1]) cylinder(d=7, h=250);
if (show_fixing_paths) translate([50.0, 0, 450.0+2*explode_mm]) rotate([-90,0,0]) color([0.8,0.1,0.1]) cylinder(d=7, h=150);
if (show_fixing_paths) translate([50.0, 0, 550.0+2*explode_mm]) rotate([-90,0,0]) color([0.8,0.1,0.1]) cylinder(d=7, h=150);
if (show_fixing_paths) translate([2350.0, 0, 450.0+2*explode_mm]) rotate([-90,0,0]) color([0.8,0.1,0.1]) cylinder(d=7, h=150);
if (show_fixing_paths) translate([2350.0, 0, 550.0+2*explode_mm]) rotate([-90,0,0]) color([0.8,0.1,0.1]) cylinder(d=7, h=150);
if (show_fixing_paths) translate([240.0, 50.0, 600+2*explode_mm]) rotate([180,0,0]) color([0.8,0.1,0.1]) cylinder(d=7, h=250);
if (show_fixing_paths) translate([740.0, 50.0, 600+2*explode_mm]) rotate([180,0,0]) color([0.8,0.1,0.1]) cylinder(d=7, h=250);
if (show_fixing_paths) translate([1240.0, 50.0, 600+2*explode_mm]) rotate([180,0,0]) color([0.8,0.1,0.1]) cylinder(d=7, h=250);
if (show_fixing_paths) translate([1740.0, 50.0, 600+2*explode_mm]) rotate([180,0,0]) color([0.8,0.1,0.1]) cylinder(d=7, h=250);
if (show_fixing_paths) translate([2240.0, 50.0, 600+2*explode_mm]) rotate([180,0,0]) color([0.8,0.1,0.1]) cylinder(d=7, h=250);
if (show_fixing_paths) translate([50.0, 340.0, 600+2*explode_mm]) rotate([180,0,0]) color([0.8,0.1,0.1]) cylinder(d=7, h=250);
if (show_fixing_paths) translate([50.0, 740.0, 600+2*explode_mm]) rotate([180,0,0]) color([0.8,0.1,0.1]) cylinder(d=7, h=250);
if (show_fixing_paths) translate([50.0, 1140.0, 600+2*explode_mm]) rotate([180,0,0]) color([0.8,0.1,0.1]) cylinder(d=7, h=250);

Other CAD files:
published/first-model-2400x1400-options/2-courses/model.scad
site/demo/offer-c1/model.scad
site/demo/offer-c2/model.scad

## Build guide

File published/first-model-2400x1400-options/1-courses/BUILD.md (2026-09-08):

# First rectangular bed draft - 2400 x 1400

**DRAFT_MARK_OUT_ONLY** | 2026-09-06 | plan `bff3700ad86be6664a13d89ba8bc8b44b8221076ef325c540b815e97a439c8ef` | physical design `ce93662dad847561df0163267d0d4b52195f3c589f74a98bc8d54693df1e58f4`

## Before work starts

This pack checks nominal geometry, stock allocation and straight screw paths. It does not calculate structural capacity, soil pressure, foundation adequacy or long-term timber movement. Do not build from an unreviewed draft. Site-specific supports/bracing are not part of the generated timber model.

- **BLOCKER / timber_and_kerf_measured**: Measure actual stock length/section, usable ends and saw kerf; update inputs before cutting.
- **BLOCKER / site_and_supports_reviewed**: Review foundations, drainage, soil loads, support/bracing and any buried services on site.
- **BLOCKER / fixing_schedule_reviewed**: Review screw suitability, end-grain connections, penetration and spacing with a competent builder / supplier.
- **BLOCKER / review_record**: Record reviewer, reviewed_on and review notes before releasing a workshop pack.
- **BLOCKER / approval_hash_required**: Release readiness requires review.approved_physical_design_hash to equal the current physical design hash, so an edited job cannot inherit an old review. Run a draft plan, then copy the printed physical design hash into the job's review block after a genuine physical review.
- **BLOCKER / pilot_unconfirmed**: wickes-287686: fixing centres are mark-out only. Confirm pilot diameter/depth or a manufacturer-supported no-pilot instruction; none is inferred.
- **Note / reach**: first-bed-01: centre reach is approximately 700 mm from 2 accessible side(s); confirm with the user. 650 mm is a planning prompt, not an accessibility standard.
- **Note / factory_ends**: Zero end trim assumes square, sound, usable factory/cut ends. Nominal 2400 mm is not a measurement.
- **Note / incomplete_cost**: Known subtotal only; unpriced: consumables, fill, liner, preservative, site_preparation, supports, transport, labour
- **Note / supply**: Catalogue prices are dated snapshots. The configured store and collection stock are NOT confirmed.
- **Note / not_structural**: Geometry and straight screw-path clearance are checked; timber strength, screw capacity, long-term movement and soil pressure are NOT calculated. Supports/bracing, liner detailing and foundations are site-specific and not drawn by v1.

## Read the dimensions correctly

All plan dimensions are millimetres. Timber wall thickness is **100 mm**; each course adds **200 mm**. Outside dimensions include the walls. Interior dimensions subtract two wall thicknesses. The drawing's S/W labels define a reference frame; they need not point south or west on site.

Piece A is the lower-global-X end for S/N members, or lower-global-Y end for W/E members. U runs from A along the piece. V runs from the lower-coordinate cross-section edge (not always the outside face). W runs upwards from the piece bottom. Top fixings enter at W=course height; outer-face entries have V=0 for S/W and V=wall thickness for N/E. Use labelled piece sheets instead of guessing the orientation.

## Assembly sequence

1. Survey the footprint and access. Identify buried services before any ground work. Confirm a level, open-bottom site and adequate drainage. Record the separate support/foundation plan. Check the purchase list and collection/handling arrangements.

2. Inspect and measure the timber: actual usable lengths, section, straightness and end condition. Measure actual saw kerf with a test cut. Set end trims explicitly, update the catalogue/job and regenerate. A nominal 2400 mm sleeper is not guaranteed to yield a square 2400 mm part.

3. Lay out the proposed frame full-size. Check external dimensions and equal outside diagonals. Confirm access to plant the centre. Label every stock item with its B-number and original end A before cutting.

4. Make the listed end trims, then the sequential crosscuts. In cuts.csv, each kerf_start..kerf_end band is WASTE. Do not centre the blade on the finished-length boundary. Coordinates stay relative to the ORIGINAL stock datum A, even after squaring it. A saw cut means one complete crosscut through the section; it does not specify a particular saw or number of machine passes. Use a suitable saw, stable supports/clamps and appropriate dust/eye/hearing protection following the tool instructions.

5. Mark the resulting piece IDs on the timber and preserve the A end / TOP / OUTER orientation. Check finished lengths. Treat exposed cut ends with the compatible product and method specified for the timber.

6. Assemble course 1 on the prepared base. Clamp and verify square and level before fixing. Corner screws enter the OUTER side face of the full-through member and pass into the end of its adjoining member. They do not enter through the cut end of that full-through member.

7. Follow the per-course drawing; the corner pattern stays the same on every course. Position and clamp the next course, then use its own fixing sheet. Stack screws enter vertically through the TOP and into the previous course. The schedule offsets them to avoid modelled existing screws. Re-check that real timber, hardware heads and installation tolerances match the model before drilling or driving. Screw HEADS and bearing seats are NOT modelled: before stacking any course, confirm the head-seat detail for the actual hardware (a protruding head can stop the next sleeper sitting flat, and recessing a seat deepens the hole and moves the tip).

8. For every fixing use the confirmed pilot instruction for the actual screw and timber. UNCONFIRMED is a STOP, not permission to choose a bit. Hole coordinates are entry centres; pilot depth is measured from that entry face along the stated direction. Nominal screw penetration includes its point, so it is not the same as effective threaded embedment.

9. Install and inspect the separately reviewed supports, protection/liner and drainage details. Do not turn an open-bottom bed into an undrained tank. Then fill to the specified freeboard. Fill quantity is cavity geometry only, without compaction, settlement, existing soil or displaced supports.

10. Record actual purchases, labour, corrections and useful offcuts. Only AFTER completing the cut plan, merge the inventory proposal into the next job. Measure retained offcuts again; running a plan does not consume physical stock.

## Draft workshop advisory (not confirmed pilot evidence)

Use this only as trial planning context while pilot mode remains unconfirmed. It is not manufacturer approval and must not be copied into release evidence without a recorded source or physical trial for the exact screw/timber pair.

- Pilot-hole trial start points for 7 mm timber-drive screws: treated softwood receiving piece around 4.5-5.0 mm; denser/harder timber often larger (around 5.5-6.0 mm).

- For long screws (for example 250 mm), test deeper pilot depths to reduce drive torque and wandering, and stop if splitting, lift or burning appears.

- Near edges/ends: clamp, reduce drive speed, and favour piloting to reduce splitting risk.

- Sleeper planter practice: keep base level and drained, preserve open-bottom drainage path, treat cut ends, and use corrosion-resistant fixings suitable for treated timber.

## Bed schedule

| Bed | Outside L x W x H | Courses | Clear opening | Fill litres | Outside diagonal |

|---|---|---:|---|---:|---:|

| first-bed-01 | 2400 x 1400 x 200 | 1 | 2200 x 1200 | 396.0 | 2778.5 |

## Purchase / cutting summary

4 purchased sleepers; 0 existing stock pieces used; 2 full crosscuts. Optimiser: **exact**. All explored cutting patterns and inventory states solved.

Finished timber: 7200 mm. Input stock: 8400 mm. Remaining offcuts: 1194 mm. Kerf + trim loss: 6 mm.

Offcuts are not all waste. No speculative offcut resale credit is used to reduce today's purchase cost.

Timber and screw purchases: **GBP 113.00**. Known subtotal: **GBP 113.00**.

Complete job cost: UNPRICED. Unpriced: consumables, fill, liner, preservative, site_preparation, supports, transport, labour.

Internal margin-based target: UNPRICED. Margin target is suppressed until all required costs are supplied. Zero is an explicit decision that an item is not needed/already allowed, not a missing price.

## Files

`plan.json` contains the full model and normalised inputs. `parts.csv` ties each member to its stock board. `cuts.csv` gives actual saw bands, including trim cuts. `stock.csv` lists every used stock item. `fixings.csv` gives local/global coordinates, receiver, direction, screw and pilot information. `shopping.csv` rounds purchases to whole screw packs. `model.scad` is an offline OpenSCAD model with optional exploded view. `drawings/` contains assembled, per-course, cutting and individual piece sheets. CSV money columns are integer pence.

The supplier and price snapshot are embedded in plan.json. Read docs/SOURCES.md and docs/ENGINEERING.md in the repository for evidence and model limits.

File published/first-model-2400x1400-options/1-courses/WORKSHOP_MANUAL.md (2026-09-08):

# Workshop manual - First rectangular bed draft - 2400 x 1400

Plan: `bff3700ad86be6664a13d89ba8bc8b44b8221076ef325c540b815e97a439c8ef`  |  Status: DRAFT_MARK_OUT_ONLY  |  As of: 2026-09-06

## Read this first

- [2x] Use two people for heavy lifts and long members.
- [CHECK] Verify level, square and labels at every stage.
- [STOP] Any blocker in `BUILD.md` means stop and resolve before building.

## Prepare before assembly

1. Clear enough floor area to lay out full-length members.
2. Confirm stock IDs, part labels and datum A orientation before cuts.
3. Keep all fixings and driver bits grouped by screw ID.
4. Open the process and drawing sheets before drilling or driving.

## Pack map (use in order)

1. `drawings/parts-fixings-board.svg`
2. `drawings/process-overview.svg`
3. `drawings/stock-arrival-labelling.svg`
4. `drawings/cuts-*.svg` + `cuts.csv`
5. `drawings/*-C*-plan.svg`
6. `drawings/*-fixings.svg` + `fixings.csv`
7. `drawings/fastener-*.svg` + `shopping.csv`

## Step flow

1. Label incoming stock and mark datum A ends.
2. Perform trims and crosscuts in listed sequence only.
3. Mark each finished part ID and orientation (A/TOP/OUTER).
4. Assemble course 1 square and level, then fix.
5. Repeat by course using each course plan and fixing sheet.
6. Fit reviewed support/drainage details before filling.

## Drill and pilot rule

- `pilot_mode=pilot`: use the scripted drill-bit diameter/depth exactly.
- `pilot_mode=none`: no pilot, per recorded evidence.
- `pilot_mode=unconfirmed`: STOP. Do not drill until diameter/depth evidence is recorded.

## Draft workshop advisory (while unconfirmed)

- These are trial planning notes only, not release evidence for `pilot_mode`.
- For 7 mm timber-drive screws, trial softwood pilot around `4.5-5.0 mm`; in denser timber trial larger pilots around `5.5-6.0 mm`.
- For long screws (for example `250 mm`), trial deeper pilots to reduce torque and wandering.
- Near edges/ends: clamp, slow drive speed, and favour piloting to reduce split risk.
- Sleeper planter basics: level drained base, maintain open-bottom drainage, treat cut ends, and use corrosion-resistant fixings.

All coordinates and counts are script-generated from the same geometry model that drives cuts, fixings and drawings.

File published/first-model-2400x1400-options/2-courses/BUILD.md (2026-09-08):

# First rectangular bed draft - 2400 x 1400

**DRAFT_MARK_OUT_ONLY** | 2026-09-06 | plan `533c04a534809d8ed40c918c5806f26e6540c8269873abd87098e54d2a0634e8` | physical design `f8ec8a71b83f37cac37a4a0d633affc1f7577abaf3949b62bc51c68da29bc76c`

## Before work starts

This pack checks nominal geometry, stock allocation and straight screw paths. It does not calculate structural capacity, soil pressure, foundation adequacy or long-term timber movement. Do not build from an unreviewed draft. Site-specific supports/bracing are not part of the generated timber model.

- **BLOCKER / timber_and_kerf_measured**: Measure actual stock length/section, usable ends and saw kerf; update inputs before cutting.
- **BLOCKER / site_and_supports_reviewed**: Review foundations, drainage, soil loads, support/bracing and any buried services on site.
- **BLOCKER / fixing_schedule_reviewed**: Review screw suitability, end-grain connections, penetration and spacing with a competent builder / supplier.
- **BLOCKER / review_record**: Record reviewer, reviewed_on and review notes before releasing a workshop pack.
- **BLOCKER / approval_hash_required**: Release readiness requires review.approved_physical_design_hash to equal the current physical design hash, so an edited job cannot inherit an old review. Run a draft plan, then copy the printed physical design hash into the job's review block after a genuine physical review.
- **Note / head_seat_unmodeled**: Screw heads, bearing seats, recesses and driver access are NOT modelled. On stacked courses a protruding head can stop the next course sitting flat even though all shafts pass the collision check, and recessing a seat deepens the hole and moves the tip. Confirm the head-seat detail with the actual hardware before stacking any course.
- **BLOCKER / pilot_unconfirmed**: wickes-287686: fixing centres are mark-out only. Confirm pilot diameter/depth or a manufacturer-supported no-pilot instruction; none is inferred.
- **BLOCKER / pilot_unconfirmed**: wickes-287688: fixing centres are mark-out only. Confirm pilot diameter/depth or a manufacturer-supported no-pilot instruction; none is inferred.
- **Note / aligned_corners**: first-bed-01: same corner arrangement on every course. Deliberately not interlocked; review the connection.
- **Note / reach**: first-bed-01: centre reach is approximately 700 mm from 2 accessible side(s); confirm with the user. 650 mm is a planning prompt, not an accessibility standard.
- **Note / factory_ends**: Zero end trim assumes square, sound, usable factory/cut ends. Nominal 2400 mm is not a measurement.
- **Note / incomplete_cost**: Known subtotal only; unpriced: consumables, fill, liner, preservative, site_preparation, supports, transport, labour
- **Note / supply**: Catalogue prices are dated snapshots. The configured store and collection stock are NOT confirmed.
- **Note / not_structural**: Geometry and straight screw-path clearance are checked; timber strength, screw capacity, long-term movement and soil pressure are NOT calculated. Supports/bracing, liner detailing and foundations are site-specific and not drawn by v1.

## Read the dimensions correctly

All plan dimensions are millimetres. Timber wall thickness is **100 mm**; each course adds **200 mm**. Outside dimensions include the walls. Interior dimensions subtract two wall thicknesses. The drawing's S/W labels define a reference frame; they need not point south or west on site.

Piece A is the lower-global-X end for S/N members, or lower-global-Y end for W/E members. U runs from A along the piece. V runs from the lower-coordinate cross-section edge (not always the outside face). W runs upwards from the piece bottom. Top fixings enter at W=course height; outer-face entries have V=0 for S/W and V=wall thickness for N/E. Use labelled piece sheets instead of guessing the orientation.

## Assembly sequence

1. Survey the footprint and access. Identify buried services before any ground work. Confirm a level, open-bottom site and adequate drainage. Record the separate support/foundation plan. Check the purchase list and collection/handling arrangements.

2. Inspect and measure the timber: actual usable lengths, section, straightness and end condition. Measure actual saw kerf with a test cut. Set end trims explicitly, update the catalogue/job and regenerate. A nominal 2400 mm sleeper is not guaranteed to yield a square 2400 mm part.

3. Lay out the proposed frame full-size. Check external dimensions and equal outside diagonals. Confirm access to plant the centre. Label every stock item with its B-number and original end A before cutting.

4. Make the listed end trims, then the sequential crosscuts. In cuts.csv, each kerf_start..kerf_end band is WASTE. Do not centre the blade on the finished-length boundary. Coordinates stay relative to the ORIGINAL stock datum A, even after squaring it. A saw cut means one complete crosscut through the section; it does not specify a particular saw or number of machine passes. Use a suitable saw, stable supports/clamps and appropriate dust/eye/hearing protection following the tool instructions.

5. Mark the resulting piece IDs on the timber and preserve the A end / TOP / OUTER orientation. Check finished lengths. Treat exposed cut ends with the compatible product and method specified for the timber.

6. Assemble course 1 on the prepared base. Clamp and verify square and level before fixing. Corner screws enter the OUTER side face of the full-through member and pass into the end of its adjoining member. They do not enter through the cut end of that full-through member.

7. Follow the per-course drawing; the corner pattern stays the same on every course. Position and clamp the next course, then use its own fixing sheet. Stack screws enter vertically through the TOP and into the previous course. The schedule offsets them to avoid modelled existing screws. Re-check that real timber, hardware heads and installation tolerances match the model before drilling or driving. Screw HEADS and bearing seats are NOT modelled: before stacking any course, confirm the head-seat detail for the actual hardware (a protruding head can stop the next sleeper sitting flat, and recessing a seat deepens the hole and moves the tip).

8. For every fixing use the confirmed pilot instruction for the actual screw and timber. UNCONFIRMED is a STOP, not permission to choose a bit. Hole coordinates are entry centres; pilot depth is measured from that entry face along the stated direction. Nominal screw penetration includes its point, so it is not the same as effective threaded embedment.

9. Install and inspect the separately reviewed supports, protection/liner and drainage details. Do not turn an open-bottom bed into an undrained tank. Then fill to the specified freeboard. Fill quantity is cavity geometry only, without compaction, settlement, existing soil or displaced supports.

10. Record actual purchases, labour, corrections and useful offcuts. Only AFTER completing the cut plan, merge the inventory proposal into the next job. Measure retained offcuts again; running a plan does not consume physical stock.

## Draft workshop advisory (not confirmed pilot evidence)

Use this only as trial planning context while pilot mode remains unconfirmed. It is not manufacturer approval and must not be copied into release evidence without a recorded source or physical trial for the exact screw/timber pair.

- Pilot-hole trial start points for 7 mm timber-drive screws: treated softwood receiving piece around 4.5-5.0 mm; denser/harder timber often larger (around 5.5-6.0 mm).

- For long screws (for example 250 mm), test deeper pilot depths to reduce drive torque and wandering, and stop if splitting, lift or burning appears.

- Near edges/ends: clamp, reduce drive speed, and favour piloting to reduce splitting risk.

- Sleeper planter practice: keep base level and drained, preserve open-bottom drainage path, treat cut ends, and use corrosion-resistant fixings suitable for treated timber.

## Bed schedule

| Bed | Outside L x W x H | Courses | Clear opening | Fill litres | Outside diagonal |

|---|---|---:|---|---:|---:|

| first-bed-01 | 2400 x 1400 x 400 | 2 | 2200 x 1200 | 924.0 | 2778.5 |

## Purchase / cutting summary

8 purchased sleepers; 0 existing stock pieces used; 4 full crosscuts. Optimiser: **exact**. All explored cutting patterns and inventory states solved.

Finished timber: 14400 mm. Input stock: 16800 mm. Remaining offcuts: 2388 mm. Kerf + trim loss: 12 mm.

Offcuts are not all waste. No speculative offcut resale credit is used to reduce today's purchase cost.

Timber and screw purchases: **GBP 229.30**. Known subtotal: **GBP 229.30**.

Complete job cost: UNPRICED. Unpriced: consumables, fill, liner, preservative, site_preparation, supports, transport, labour.

Internal margin-based target: UNPRICED. Margin target is suppressed until all required costs are supplied. Zero is an explicit decision that an item is not needed/already allowed, not a missing price.

## Files

`plan.json` contains the full model and normalised inputs. `parts.csv` ties each member to its stock board. `cuts.csv` gives actual saw bands, including trim cuts. `stock.csv` lists every used stock item. `fixings.csv` gives local/global coordinates, receiver, direction, screw and pilot information. `shopping.csv` rounds purchases to whole screw packs. `model.scad` is an offline OpenSCAD model with optional exploded view. `drawings/` contains assembled, per-course, cutting and individual piece sheets. CSV money columns are integer pence.

The supplier and price snapshot are embedded in plan.json. Read docs/SOURCES.md and docs/ENGINEERING.md in the repository for evidence and model limits.

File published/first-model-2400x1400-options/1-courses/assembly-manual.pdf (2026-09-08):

# Assembly guide

## First rectangular bed draft - 2400 x 1400 DRAFT_MARK_OUT_ONLY | as of 2026-09-06 | physical ce93662dad84

### In this pack

13 numbered steps - one dominant action per step
3D keyframes: highlighted = current part, solid = installed, ghost outline = later Scaled joint sections for every preparation/driving operation
4 labelled parts, 8 fixings, 4 sleepers
Full coordinates in fixings.csv; saw bands in cuts.csv

STOP entries are mark-out only:
where a pilot diameter/depth or head-seat detail is unconfirmed, do not drill or drive until confirmed for the actual hardware. This guide is not structural certification.

1

## Prepare board B001

step 1 of 13 | receive
wickes-276785 | gross 2400 mm | reject twisted, split or unsound stock. Trims: start 0
mm, end 0 mm. Write board ID B001 on the timber and mark datum A. All cut coordinates run from this original A datum, even after squaring. Apply the compatible cut-end preservative per the timber supplier's method before assembly.
Sleeperplan | bff3700ad86b | DRAFT_MARK_OUT_ONLY | 1

2

## Prepare board B002

step 2 of 13 | receive
wickes-276785 | gross 2400 mm | reject twisted, split or unsound stock. Trims: start 0
mm, end 0 mm. Write board ID B002 on the timber and mark datum A. All cut coordinates run from this original A datum, even after squaring. Apply the compatible cut-end preservative per the timber supplier's method before assembly.

3

## Prepare board B003

step 3 of 13 | receive
wickes-256948 | gross 1800 mm | reject twisted, split or unsound stock. Trims: start 0
mm, end 0 mm. Write board ID B003 on the timber and mark datum A. All cut coordinates run from this original A datum, even after squaring. Apply the compatible cut-end preservative per the timber supplier's method before assembly.

4

## Crosscut; keep piece on datum side B003 @ 1201.5 mm

step 4 of 13 | cut

crosscut; keep piece on datum side at blade centre 1201.5 mm from A. Kerf band 1200..1203 mm is WASTE - do not centre the blade on a finished-length boundary. One complete crosscut through the section.

5

## Prepare board B004

step 5 of 13 | receive
wickes-256948 | gross 1800 mm | reject twisted, split or unsound stock. Trims: start 0
mm, end 0 mm. Write board ID B004 on the timber and mark datum A. All cut coordinates run from this original A datum, even after squaring. Apply the compatible cut-end preservative per the timber supplier's method before assembly.

6

## Crosscut; keep piece on datum side B004 @ 1201.5 mm

step 6 of 13 | cut

crosscut; keep piece on datum side at blade centre 1201.5 mm from A. Kerf band 1200..1203 mm is WASTE - do not centre the blade on a finished-length boundary. One complete crosscut through the section.

7

## Place first-bed-01 course 1

step 7 of 13 | place

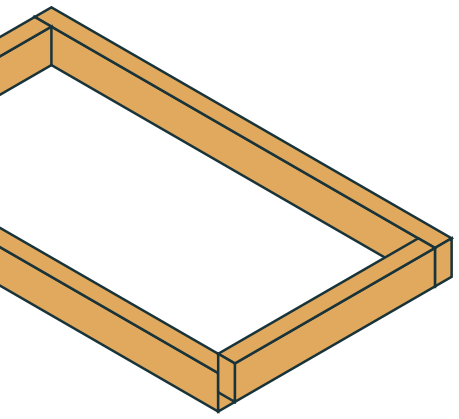
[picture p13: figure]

Lay the course-1 members for first-bed-01 in the drawn positions (outside 2400 x 1400 mm).

8

## Clamp and check first-bed-01 course 1

step 8 of 13 | clamp

Clamp the course, check square (equal outside diagonals) and level. Do not release the clamps until this course's fixings are driven.

9

## Fit corner screws - first-bed-01-C1-N

step 9 of 13 | mark

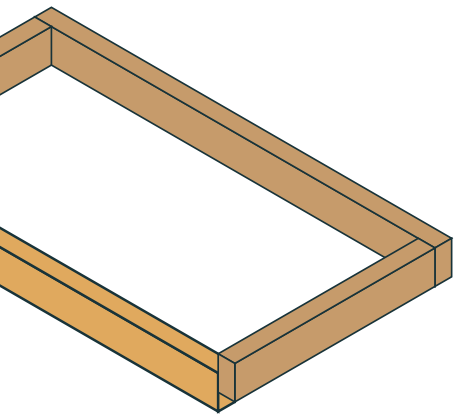
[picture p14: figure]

through member | receiver

mating plane

MARK ONLY - do not drill
100 mm

Scaled section along the fixed screw axis; not a 1:1 template.

Pilot spec UNCONFIRMED: mark the centre only. Do NOT drill or drive until a recorded trial or manufacturer instruction confirms diameter and depth. horizontally into the
OUTER face at U 50 / V 100 / W 50 mm from piece datum A (50, 1400, 50 global). Drive wickes-287686 square to the entry face into receiver first-bed-01-C1-W. Nominal penetration 50 mm (includes the point; not rated embedment). Head seat: confirm against
the actual hardware - heads and recesses are NOT modelled. Repeat identically at all 4 corner positions on this member (coordinates differ; preparation is identical).

Scaled section along the screw axis. All positions for this member: mark-out sheet first-bed-01-C1-N-fixings.svg.

10

## Seated view - corner screws

step 10 of 13 | drive
through member | receiver

mating plane

head

pen 50 mm

Head bears on the entry face; confirm the seat detail with the actual hardware.

100 mm

Scaled section along the fixed screw axis; not a 1:1 template.

This is how a correctly seated screw looks in section: head bearing on the entry face, point inside the receiver. The head-seat detail must be confirmed with the actual hardware before any course is stacked over driven screws.

Seated view along the screw axis.

11

## Fit corner screws - first-bed-01-C1-S

step 11 of 13 | mark

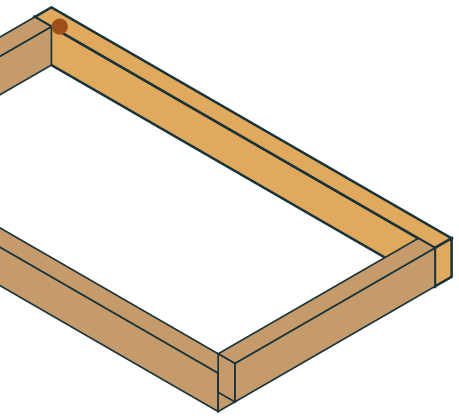
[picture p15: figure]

through member | receiver

mating plane

MARK ONLY - do not drill
100 mm

Scaled section along the fixed screw axis; not a 1:1 template.

Pilot spec UNCONFIRMED: mark the centre only. Do NOT drill or drive until a recorded trial or manufacturer instruction confirms diameter and depth. horizontally into the
OUTER face at U 50 / V 0 / W 50 mm from piece datum A (50, 0, 50 global). Drive wickes-287686 square to the entry face into receiver first-bed-01-C1-W. Nominal penetration 50 mm (includes the point; not rated embedment). Head seat: confirm against
the actual hardware - heads and recesses are NOT modelled. Repeat identically at all 4 corner positions on this member (coordinates differ; preparation is identical).

Scaled section along the screw axis. All positions for this member: mark-out sheet first-bed-01-C1-S-fixings.svg.

12

## Install reviewed supports, liner and drainage

step 12 of 13 | supports

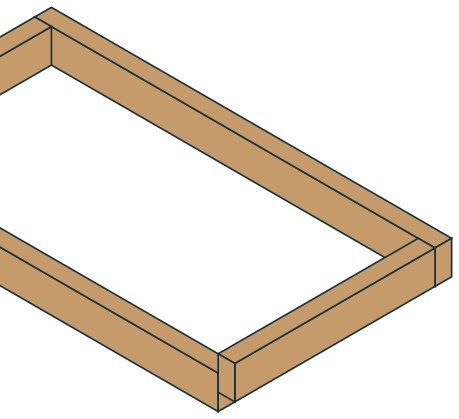
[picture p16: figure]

Fit the separately reviewed restraint/bracing and protection details. Keep the base open-bottomed and drained; never turn the bed into an undrained tank.

13

## Final check and fill to freeboard

step 13 of 13 | final

Re-check level, square and all fixing seats. Fill to the specified freeboard. Record actual purchases, labour, corrections and useful offcuts; merge the inventory proposal only after the job is completed.

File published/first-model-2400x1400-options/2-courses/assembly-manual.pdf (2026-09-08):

# Assembly guide

## First rectangular bed draft - 2400 x 1400 DRAFT_MARK_OUT_ONLY | as of 2026-09-06 | physical f8ec8a71b83f

### In this pack

28 numbered steps - one dominant action per step
3D keyframes: highlighted = current part, solid = installed, ghost outline = later Scaled joint sections for every preparation/driving operation
8 labelled parts, 32 fixings, 8 sleepers
Full coordinates in fixings.csv; saw bands in cuts.csv

STOP entries are mark-out only:
where a pilot diameter/depth or head-seat detail is unconfirmed, do not drill or drive until confirmed for the actual hardware. This guide is not structural certification.

1

## Prepare board B001

step 1 of 28 | receive

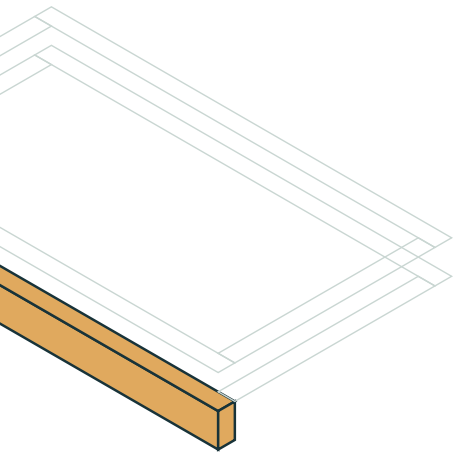
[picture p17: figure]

wickes-276785 | gross 2400 mm | reject twisted, split or unsound stock. Trims: start 0
mm, end 0 mm. Write board ID B001 on the timber and mark datum A. All cut coordinates run from this original A datum, even after squaring. Apply the compatible cut-end preservative per the timber supplier's method before assembly.
Sleeperplan | 533c04a53480 | DRAFT_MARK_OUT_ONLY | 1

2

## Prepare board B002

step 2 of 28 | receive

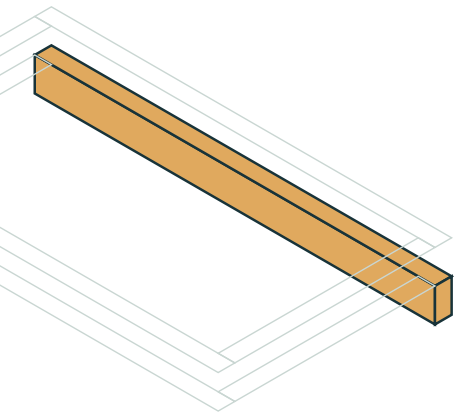
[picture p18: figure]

wickes-276785 | gross 2400 mm | reject twisted, split or unsound stock. Trims: start 0
mm, end 0 mm. Write board ID B002 on the timber and mark datum A. All cut coordinates run from this original A datum, even after squaring. Apply the compatible cut-end preservative per the timber supplier's method before assembly.

3

## Prepare board B003

step 3 of 28 | receive

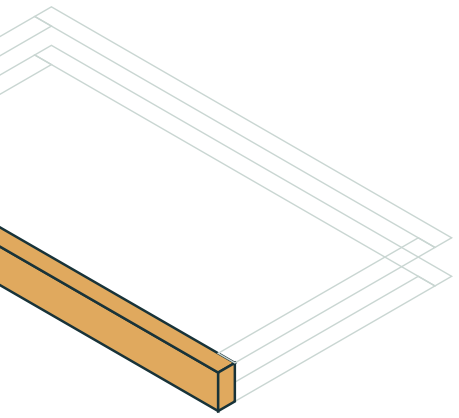
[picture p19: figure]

wickes-276785 | gross 2400 mm | reject twisted, split or unsound stock. Trims: start 0
mm, end 0 mm. Write board ID B003 on the timber and mark datum A. All cut coordinates run from this original A datum, even after squaring. Apply the compatible cut-end preservative per the timber supplier's method before assembly.

4

## Prepare board B004

step 4 of 28 | receive

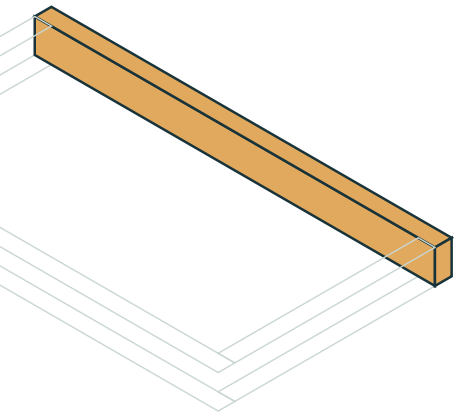
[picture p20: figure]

wickes-276785 | gross 2400 mm | reject twisted, split or unsound stock. Trims: start 0
mm, end 0 mm. Write board ID B004 on the timber and mark datum A. All cut coordinates run from this original A datum, even after squaring. Apply the compatible cut-end preservative per the timber supplier's method before assembly.

5

## Prepare board B005

step 5 of 28 | receive

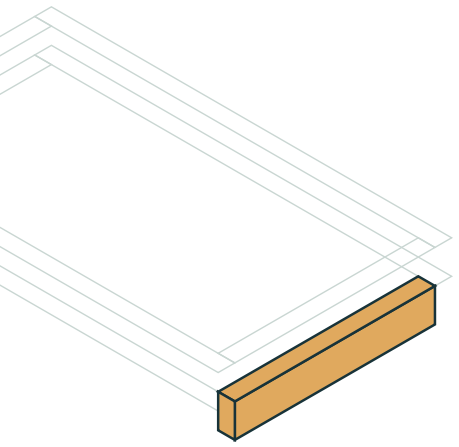
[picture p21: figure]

wickes-256948 | gross 1800 mm | reject twisted, split or unsound stock. Trims: start 0
mm, end 0 mm. Write board ID B005 on the timber and mark datum A. All cut coordinates run from this original A datum, even after squaring. Apply the compatible cut-end preservative per the timber supplier's method before assembly.

6

## Crosscut; keep piece on datum side B005 @ 1201.5 mm

step 6 of 28 | cut

crosscut; keep piece on datum side at blade centre 1201.5 mm from A. Kerf band 1200..1203 mm is WASTE - do not centre the blade on a finished-length boundary. One complete crosscut through the section.

7

## Prepare board B006

step 7 of 28 | receive

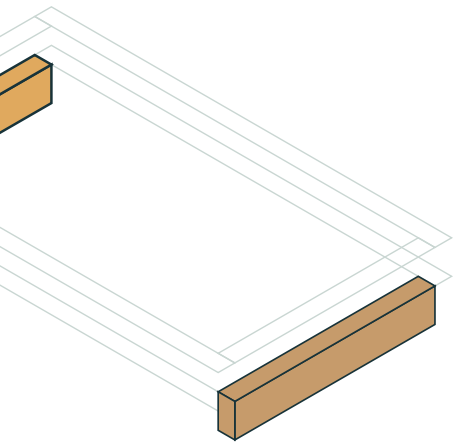
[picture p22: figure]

wickes-256948 | gross 1800 mm | reject twisted, split or unsound stock. Trims: start 0
mm, end 0 mm. Write board ID B006 on the timber and mark datum A. All cut coordinates run from this original A datum, even after squaring. Apply the compatible cut-end preservative per the timber supplier's method before assembly.

8

## Crosscut; keep piece on datum side B006 @ 1201.5 mm

step 8 of 28 | cut

crosscut; keep piece on datum side at blade centre 1201.5 mm from A. Kerf band 1200..1203 mm is WASTE - do not centre the blade on a finished-length boundary. One complete crosscut through the section.

9

## Prepare board B007

step 9 of 28 | receive

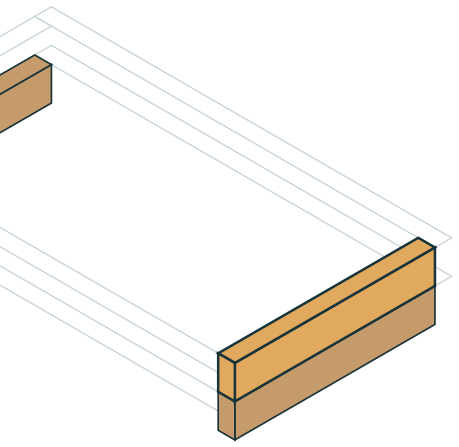
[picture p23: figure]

wickes-256948 | gross 1800 mm | reject twisted, split or unsound stock. Trims: start 0
mm, end 0 mm. Write board ID B007 on the timber and mark datum A. All cut coordinates run from this original A datum, even after squaring. Apply the compatible cut-end preservative per the timber supplier's method before assembly.

10

## Crosscut; keep piece on datum side B007 @ 1201.5 mm

step 10 of 28 | cut

crosscut; keep piece on datum side at blade centre 1201.5 mm from A. Kerf band 1200..1203 mm is WASTE - do not centre the blade on a finished-length boundary. One complete crosscut through the section.

11

## Prepare board B008

step 11 of 28 | receive
wickes-256948 | gross 1800 mm | reject twisted, split or unsound stock. Trims: start 0
mm, end 0 mm. Write board ID B008 on the timber and mark datum A. All cut coordinates run from this original A datum, even after squaring. Apply the compatible cut-end preservative per the timber supplier's method before assembly.

12

## Crosscut; keep piece on datum side B008 @ 1201.5 mm

step 12 of 28 | cut

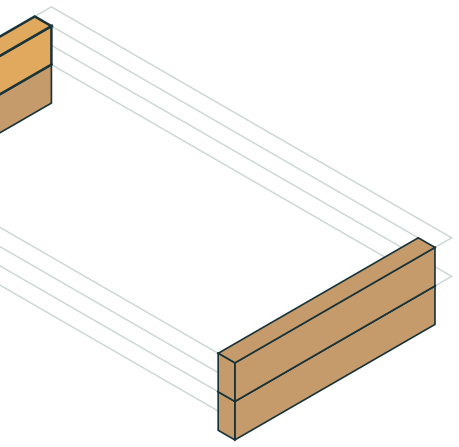
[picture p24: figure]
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

13

## Place first-bed-01 course 1

step 13 of 28 | place

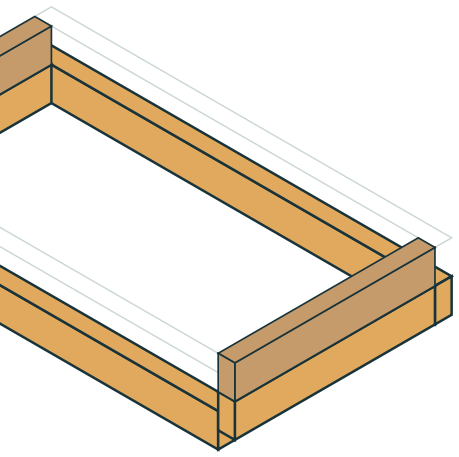
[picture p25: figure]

Lay the course-1 members for first-bed-01 in the drawn positions (outside 2400 x 1400 mm).

14

## Clamp and check first-bed-01 course 1

step 14 of 28 | clamp

Clamp the course, check square (equal outside diagonals) and level. Do not release the clamps until this course's fixings are driven.

15

## Fit corner screws - first-bed-01-C1-N

step 15 of 28 | mark

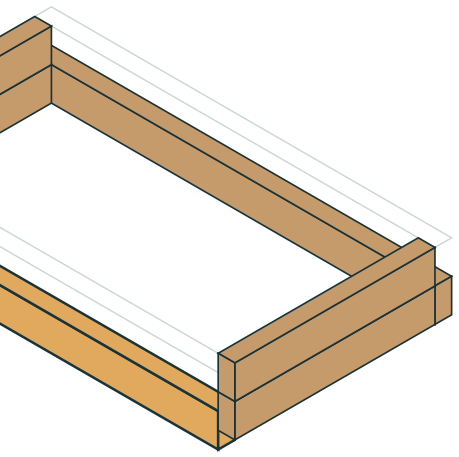
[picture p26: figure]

through member | receiver

mating plane

MARK ONLY - do not drill
100 mm

Scaled section along the fixed screw axis; not a 1:1 template.

Pilot spec UNCONFIRMED: mark the centre only. Do NOT drill or drive until a recorded trial or manufacturer instruction confirms diameter and depth. horizontally into the
OUTER face at U 50 / V 100 / W 50 mm from piece datum A (50, 1400, 50 global). Drive wickes-287686 square to the entry face into receiver first-bed-01-C1-W. Nominal penetration 50 mm (includes the point; not rated embedment). Head seat: confirm against
the actual hardware - heads and recesses are NOT modelled. Repeat identically at all 4 corner positions on this member (coordinates differ; preparation is identical).

Scaled section along the screw axis. All positions for this member: mark-out sheet first-bed-01-C1-N-fixings.svg.

16

## Seated view - corner screws

step 16 of 28 | drive
through member | receiver

mating plane

head

pen 50 mm

Head bears on the entry face; confirm the seat detail with the actual hardware.

100 mm

Scaled section along the fixed screw axis; not a 1:1 template.

This is how a correctly seated screw looks in section: head bearing on the entry face, point inside the receiver. The head-seat detail must be confirmed with the actual hardware before any course is stacked over driven screws.

Seated view along the screw axis.

17

## Fit corner screws - first-bed-01-C1-S

step 17 of 28 | mark

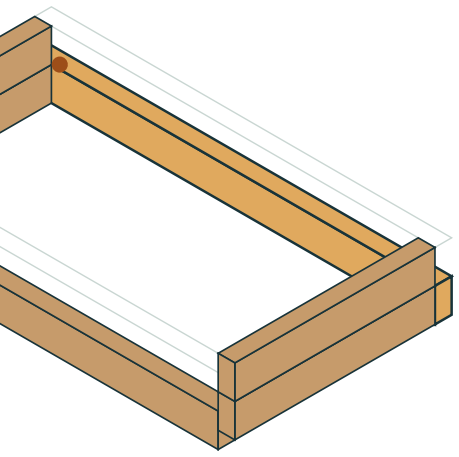
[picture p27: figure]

through member | receiver

mating plane

MARK ONLY - do not drill
100 mm

Scaled section along the fixed screw axis; not a 1:1 template.

Pilot spec UNCONFIRMED: mark the centre only. Do NOT drill or drive until a recorded trial or manufacturer instruction confirms diameter and depth. horizontally into the
OUTER face at U 50 / V 0 / W 50 mm from piece datum A (50, 0, 50 global). Drive wickes-287686 square to the entry face into receiver first-bed-01-C1-W. Nominal penetration 50 mm (includes the point; not rated embedment). Head seat: confirm against
the actual hardware - heads and recesses are NOT modelled. Repeat identically at all 4 corner positions on this member (coordinates differ; preparation is identical).

Scaled section along the screw axis. All positions for this member: mark-out sheet first-bed-01-C1-S-fixings.svg.

18

## Place first-bed-01 course 2

step 18 of 28 | place

Lay the course-2 members for first-bed-01 in the drawn positions (outside 2400 x 1400 mm).

19

## Clamp and check first-bed-01 course 2

step 19 of 28 | clamp

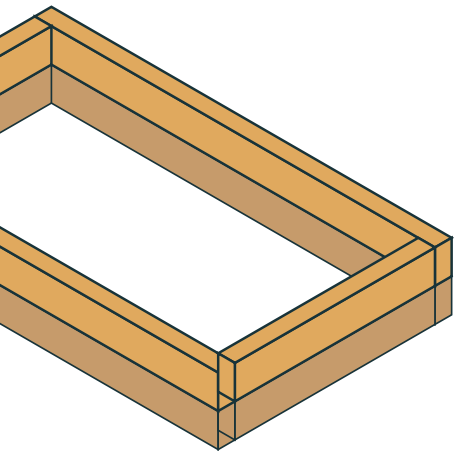
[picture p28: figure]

Clamp the course, check square (equal outside diagonals) and level. Do not release the clamps until this course's fixings are driven.

20

## Fit stack screws - first-bed-01-C2-E

step 20 of 28 | mark

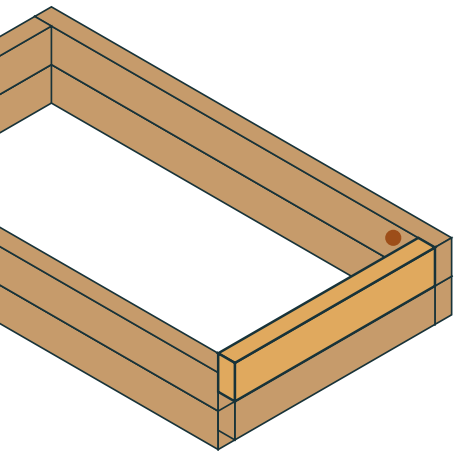
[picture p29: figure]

through member | receiver

mating plane

MARK ONLY - do not drill
200 mm

Scaled section along the fixed screw axis; not a 1:1 template.

Pilot spec UNCONFIRMED: mark the centre only. Do NOT drill or drive until a recorded trial or manufacturer instruction confirms diameter and depth. vertically through the
TOP face at U 200 / V 50 / W 200 mm from piece datum A (2350, 300, 400 global). Drive wickes-287688 square to the entry face into receiver first-bed-01-C1-E. Nominal penetration 50 mm (includes the point; not rated embedment). Head seat: confirm against
the actual hardware - heads and recesses are NOT modelled. Repeat identically at all 3
stack positions on this member (coordinates differ; preparation is identical).

Scaled section along the screw axis. All positions for this member: mark-out sheet first-bed-01-C2-E-fixings.svg.

21

## Seated view - stack screws

step 21 of 28 | drive
through member | receiver

mating plane

head

pen 50 mm

Head bears on the entry face; confirm the seat detail with the actual hardware.

200 mm

Scaled section along the fixed screw axis; not a 1:1 template.

This is how a correctly seated screw looks in section: head bearing on the entry face, point inside the receiver. The head-seat detail must be confirmed with the actual hardware before any course is stacked over driven screws.

Seated view along the screw axis.

22

## Fit corner screws - first-bed-01-C2-N

step 22 of 28 | mark

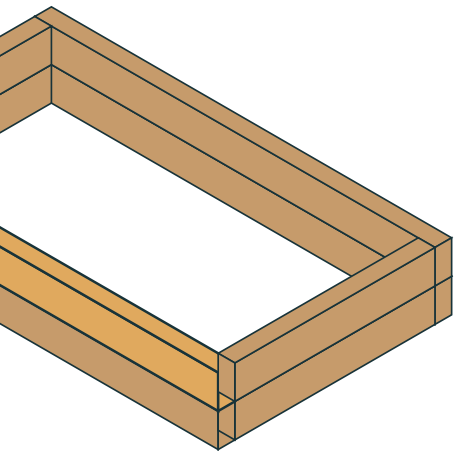
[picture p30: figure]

through member | receiver

mating plane

MARK ONLY - do not drill
100 mm

Scaled section along the fixed screw axis; not a 1:1 template.

Pilot spec UNCONFIRMED: mark the centre only. Do NOT drill or drive until a recorded trial or manufacturer instruction confirms diameter and depth. horizontally into the
OUTER face at U 50 / V 100 / W 50 mm from piece datum A (50, 1400, 250 global). Drive wickes-287686 square to the entry face into receiver first-bed-01-C2-W. Nominal penetration 50 mm (includes the point; not rated embedment). Head seat: confirm against
the actual hardware - heads and recesses are NOT modelled. Repeat identically at all 4 corner positions on this member (coordinates differ; preparation is identical).

Scaled section along the screw axis. All positions for this member: mark-out sheet first-bed-01-C2-N-fixings.svg.

23

## Fit stack screws - first-bed-01-C2-N

step 23 of 28 | mark
through member | receiver

mating plane

MARK ONLY - do not drill
200 mm

Scaled section along the fixed screw axis; not a 1:1 template.

Pilot spec UNCONFIRMED: mark the centre only. Do NOT drill or drive until a recorded trial or manufacturer instruction confirms diameter and depth. vertically through the
TOP face at U 200 / V 50 / W 200 mm from piece datum A (200, 1350, 400 global). Drive wickes-287688 square to the entry face into receiver first-bed-01-C1-N. Nominal penetration 50 mm (includes the point; not rated embedment). Head seat: confirm against
the actual hardware - heads and recesses are NOT modelled. Repeat identically at all 5
stack positions on this member (coordinates differ; preparation is identical).

Scaled section along the screw axis. All positions for this member: mark-out sheet first-bed-01-C2-N-fixings.svg.

24

## Fit corner screws - first-bed-01-C2-S

step 24 of 28 | mark

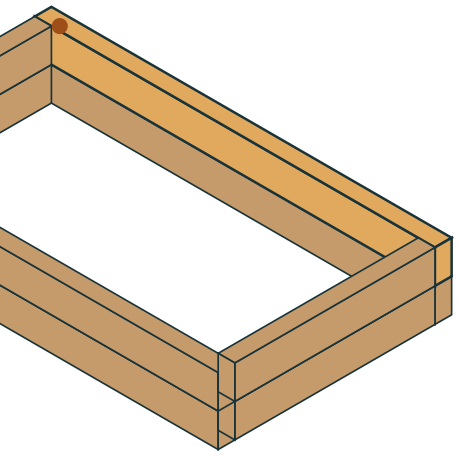
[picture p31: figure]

through member | receiver

mating plane

MARK ONLY - do not drill
100 mm

Scaled section along the fixed screw axis; not a 1:1 template.

Pilot spec UNCONFIRMED: mark the centre only. Do NOT drill or drive until a recorded trial or manufacturer instruction confirms diameter and depth. horizontally into the
OUTER face at U 50 / V 0 / W 50 mm from piece datum A (50, 0, 250 global). Drive wickes-287686 square to the entry face into receiver first-bed-01-C2-W. Nominal penetration 50 mm (includes the point; not rated embedment). Head seat: confirm against
the actual hardware - heads and recesses are NOT modelled. Repeat identically at all 4 corner positions on this member (coordinates differ; preparation is identical).

Scaled section along the screw axis. All positions for this member: mark-out sheet first-bed-01-C2-S-fixings.svg.

25

## Fit stack screws - first-bed-01-C2-S

step 25 of 28 | mark

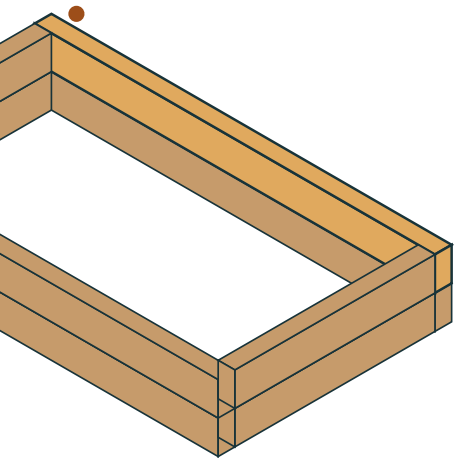
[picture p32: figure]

through member | receiver

mating plane

MARK ONLY - do not drill
200 mm

Scaled section along the fixed screw axis; not a 1:1 template.

Pilot spec UNCONFIRMED: mark the centre only. Do NOT drill or drive until a recorded trial or manufacturer instruction confirms diameter and depth. vertically through the
TOP face at U 200 / V 50 / W 200 mm from piece datum A (200, 50, 400 global). Drive wickes-287688 square to the entry face into receiver first-bed-01-C1-S. Nominal penetration 50 mm (includes the point; not rated embedment). Head seat: confirm against
the actual hardware - heads and recesses are NOT modelled. Repeat identically at all 5
stack positions on this member (coordinates differ; preparation is identical).

Scaled section along the screw axis. All positions for this member: mark-out sheet first-bed-01-C2-S-fixings.svg.

26

## Fit stack screws - first-bed-01-C2-W

step 26 of 28 | mark

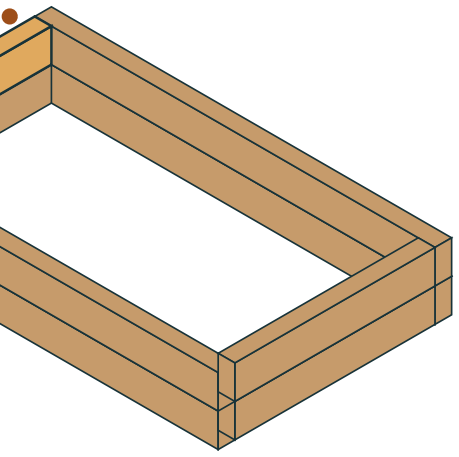
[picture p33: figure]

through member | receiver

mating plane

MARK ONLY - do not drill
200 mm

Scaled section along the fixed screw axis; not a 1:1 template.

Pilot spec UNCONFIRMED: mark the centre only. Do NOT drill or drive until a recorded trial or manufacturer instruction confirms diameter and depth. vertically through the
TOP face at U 200 / V 50 / W 200 mm from piece datum A (50, 300, 400 global). Drive wickes-287688 square to the entry face into receiver first-bed-01-C1-W. Nominal penetration 50 mm (includes the point; not rated embedment). Head seat: confirm against
the actual hardware - heads and recesses are NOT modelled. Repeat identically at all 3
stack positions on this member (coordinates differ; preparation is identical).

Scaled section along the screw axis. All positions for this member: mark-out sheet first-bed-01-C2-W-fixings.svg.

27

## Install reviewed supports, liner and drainage

step 27 of 28 | supports

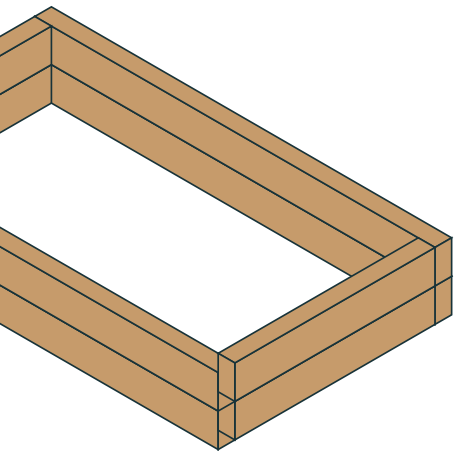
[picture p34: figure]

Fit the separately reviewed restraint/bracing and protection details. Keep the base open-bottomed and drained; never turn the bed into an undrained tank.

28

## Final check and fill to freeboard

step 28 of 28 | final

Re-check level, square and all fixing seats. Fill to the specified freeboard. Record actual purchases, labour, corrections and useful offcuts; merge the inventory proposal only after the job is completed.

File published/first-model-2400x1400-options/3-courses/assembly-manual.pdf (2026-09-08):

# Assembly guide

## First rectangular bed draft - 2400 x 1400 DRAFT_MARK_OUT_ONLY | as of 2026-09-06 | physical 2724d16028a0

### In this pack

42 numbered steps - one dominant action per step
3D keyframes: highlighted = current part, solid = installed, ghost outline = later Scaled joint sections for every preparation/driving operation
12 labelled parts, 56 fixings, 12 sleepers
Full coordinates in fixings.csv; saw bands in cuts.csv

STOP entries are mark-out only:
where a pilot diameter/depth or head-seat detail is unconfirmed, do not drill or drive until confirmed for the actual hardware. This guide is not structural certification.

1

## Prepare board B001

step 1 of 42 | receive

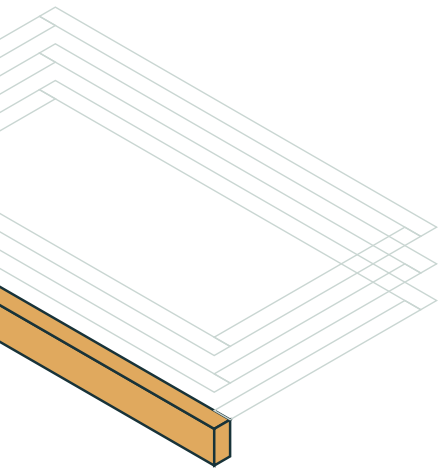
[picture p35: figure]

wickes-276785 | gross 2400 mm | reject twisted, split or unsound stock. Trims: start 0
mm, end 0 mm. Write board ID B001 on the timber and mark datum A. All cut coordinates run from this original A datum, even after squaring. Apply the compatible cut-end preservative per the timber supplier's method before assembly.
Sleeperplan | 9d70b40ac2ba | DRAFT_MARK_OUT_ONLY | 1

2

## Prepare board B002

step 2 of 42 | receive

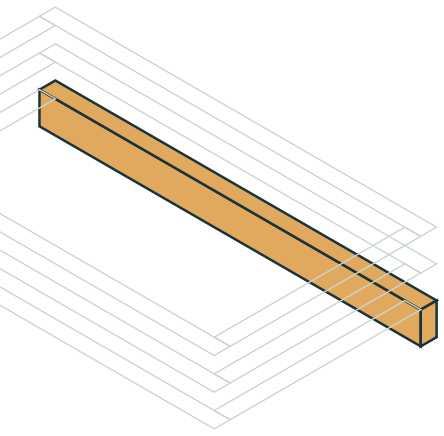
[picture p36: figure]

wickes-276785 | gross 2400 mm | reject twisted, split or unsound stock. Trims: start 0
mm, end 0 mm. Write board ID B002 on the timber and mark datum A. All cut coordinates run from this original A datum, even after squaring. Apply the compatible cut-end preservative per the timber supplier's method before assembly.

3

## Prepare board B003

step 3 of 42 | receive

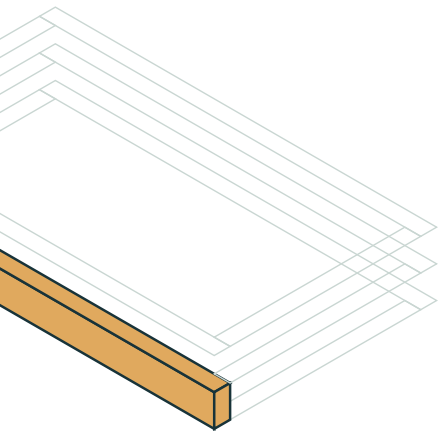
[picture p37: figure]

wickes-276785 | gross 2400 mm | reject twisted, split or unsound stock. Trims: start 0
mm, end 0 mm. Write board ID B003 on the timber and mark datum A. All cut coordinates run from this original A datum, even after squaring. Apply the compatible cut-end preservative per the timber supplier's method before assembly.

4

## Prepare board B004

step 4 of 42 | receive

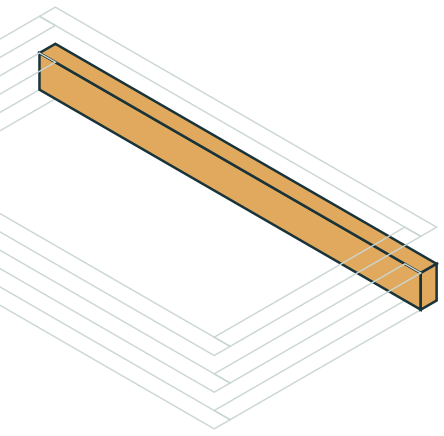
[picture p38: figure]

wickes-276785 | gross 2400 mm | reject twisted, split or unsound stock. Trims: start 0
mm, end 0 mm. Write board ID B004 on the timber and mark datum A. All cut coordinates run from this original A datum, even after squaring. Apply the compatible cut-end preservative per the timber supplier's method before assembly.

5

## Prepare board B005

step 5 of 42 | receive

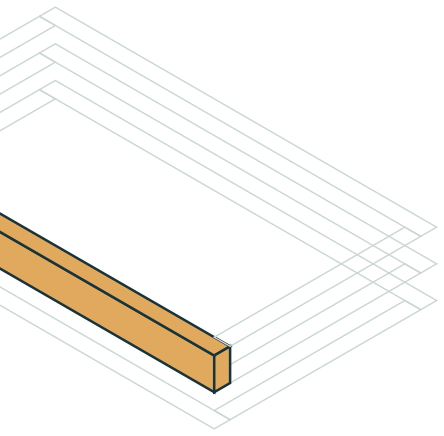
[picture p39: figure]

wickes-276785 | gross 2400 mm | reject twisted, split or unsound stock. Trims: start 0
mm, end 0 mm. Write board ID B005 on the timber and mark datum A. All cut coordinates run from this original A datum, even after squaring. Apply the compatible cut-end preservative per the timber supplier's method before assembly.

6

## Prepare board B006

step 6 of 42 | receive

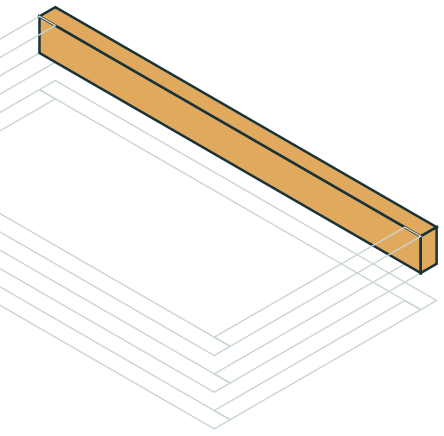
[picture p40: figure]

wickes-276785 | gross 2400 mm | reject twisted, split or unsound stock. Trims: start 0
mm, end 0 mm. Write board ID B006 on the timber and mark datum A. All cut coordinates run from this original A datum, even after squaring. Apply the compatible cut-end preservative per the timber supplier's method before assembly.

7

## Prepare board B007

step 7 of 42 | receive

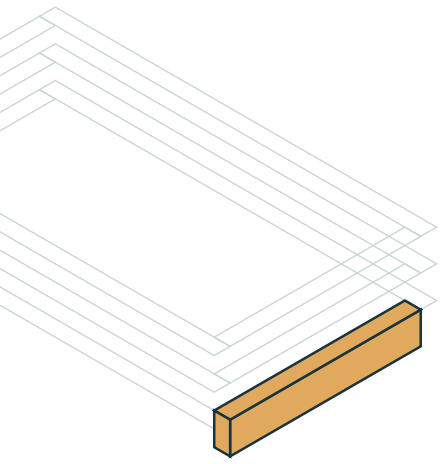
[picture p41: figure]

wickes-256948 | gross 1800 mm | reject twisted, split or unsound stock. Trims: start 0
mm, end 0 mm. Write board ID B007 on the timber and mark datum A. All cut coordinates run from this original A datum, even after squaring. Apply the compatible cut-end preservative per the timber supplier's method before assembly.

8

## Crosscut; keep piece on datum side B007 @ 1201.5 mm

step 8 of 42 | cut

crosscut; keep piece on datum side at blade centre 1201.5 mm from A. Kerf band 1200..1203 mm is WASTE - do not centre the blade on a finished-length boundary. One complete crosscut through the section.

9

## Prepare board B008

step 9 of 42 | receive
wickes-256948 | gross 1800 mm | reject twisted, split or unsound stock. Trims: start 0
mm, end 0 mm. Write board ID B008 on the timber and mark datum A. All cut coordinates run from this original A datum, even after squaring. Apply the compatible cut-end preservative per the timber supplier's method before assembly.

10

## Crosscut; keep piece on datum side B008 @ 1201.5 mm

step 10 of 42 | cut

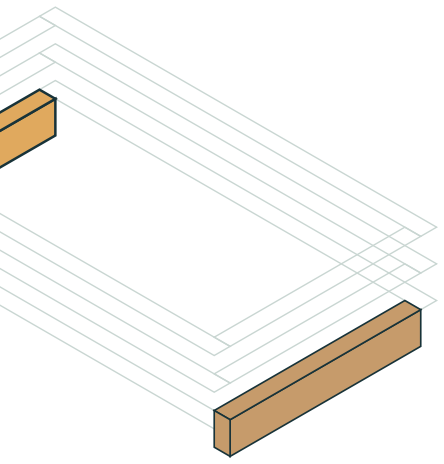
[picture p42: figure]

crosscut; keep piece on datum side at blade centre 1201.5 mm from A. Kerf band 1200..1203 mm is WASTE - do not centre the blade on a finished-length boundary. One complete crosscut through the section.

11

## Prepare board B009

step 11 of 42 | receive
wickes-256948 | gross 1800 mm | reject twisted, split or unsound stock. Trims: start 0
mm, end 0 mm. Write board ID B009 on the timber and mark datum A. All cut coordinates run from this original A datum, even after squaring. Apply the compatible cut-end preservative per the timber supplier's method before assembly.

12

## Crosscut; keep piece on datum side B009 @ 1201.5 mm

step 12 of 42 | cut

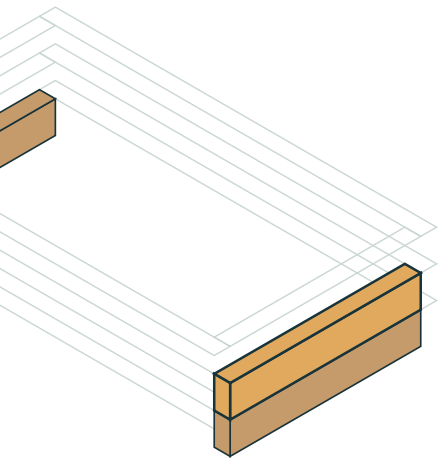
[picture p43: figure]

crosscut; keep piece on datum side at blade centre 1201.5 mm from A. Kerf band 1200..1203 mm is WASTE - do not centre the blade on a finished-length boundary. One complete crosscut through the section.

13

## Prepare board B010

step 13 of 42 | receive
wickes-256948 | gross 1800 mm | reject twisted, split or unsound stock. Trims: start 0
mm, end 0 mm. Write board ID B010 on the timber and mark datum A. All cut coordinates run from this original A datum, even after squaring. Apply the compatible cut-end preservative per the timber supplier's method before assembly.

14

## Crosscut; keep piece on datum side B010 @ 1201.5 mm

step 14 of 42 | cut

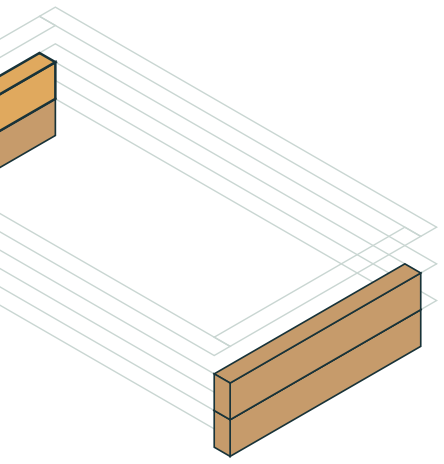
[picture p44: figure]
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

15

## Prepare board B011

step 15 of 42 | receive

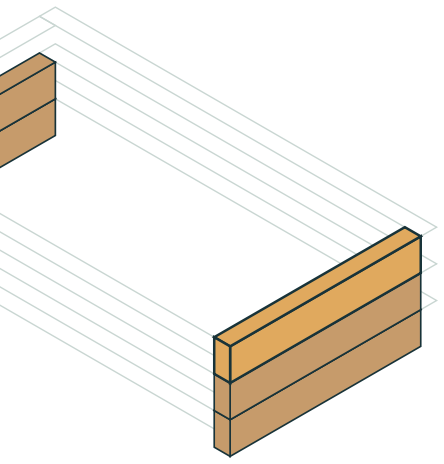
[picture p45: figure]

wickes-256948 | gross 1800 mm | reject twisted, split or unsound stock. Trims: start 0
mm, end 0 mm. Write board ID B011 on the timber and mark datum A. All cut coordinates run from this original A datum, even after squaring. Apply the compatible cut-end preservative per the timber supplier's method before assembly.

16

## Crosscut; keep piece on datum side B011 @ 1201.5 mm

step 16 of 42 | cut

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

17

## Prepare board B012

step 17 of 42 | receive

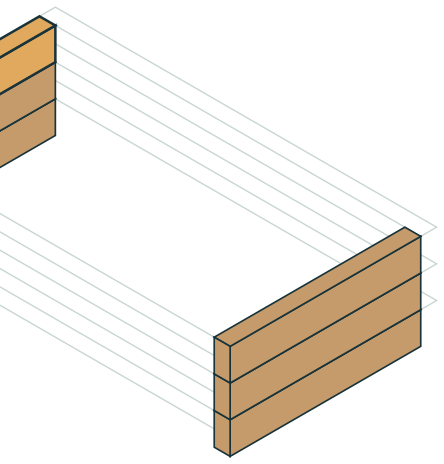
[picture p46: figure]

wickes-256948 | gross 1800 mm | reject twisted, split or unsound stock. Trims: start 0
mm, end 0 mm. Write board ID B012 on the timber and mark datum A. All cut coordinates run from this original A datum, even after squaring. Apply the compatible cut-end preservative per the timber supplier's method before assembly.

18

## Crosscut; keep piece on datum side B012 @ 1201.5 mm

step 18 of 42 | cut

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

19

## Place first-bed-01 course 1

step 19 of 42 | place

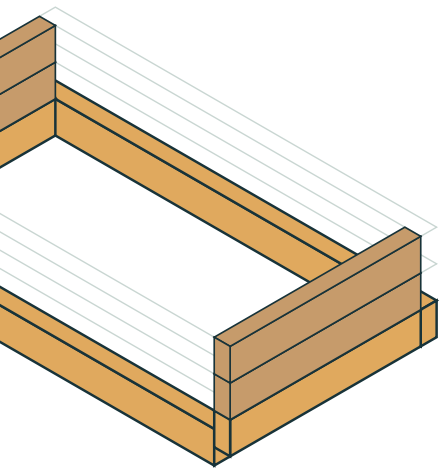
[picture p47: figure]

Lay the course-1 members for first-bed-01 in the drawn positions (outside 2400 x 1400 mm).

20

## Clamp and check first-bed-01 course 1

step 20 of 42 | clamp

Clamp the course, check square (equal outside diagonals) and level. Do not release the clamps until this course's fixings are driven.

21

## Fit corner screws - first-bed-01-C1-N

step 21 of 42 | mark

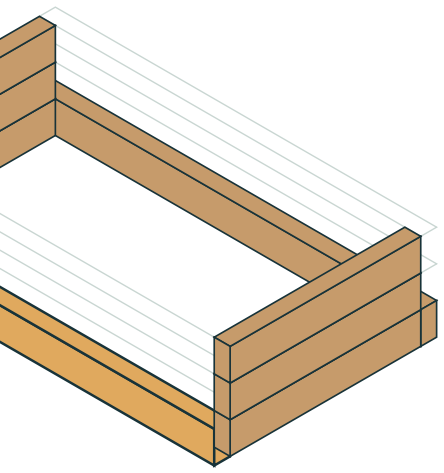
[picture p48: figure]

through member | receiver

mating plane

MARK ONLY - do not drill
100 mm

Scaled section along the fixed screw axis; not a 1:1 template.

Pilot spec UNCONFIRMED: mark the centre only. Do NOT drill or drive until a recorded trial or manufacturer instruction confirms diameter and depth. horizontally into the
OUTER face at U 50 / V 100 / W 50 mm from piece datum A (50, 1400, 50 global). Drive wickes-287686 square to the entry face into receiver first-bed-01-C1-W. Nominal penetration 50 mm (includes the point; not rated embedment). Head seat: confirm against
the actual hardware - heads and recesses are NOT modelled. Repeat identically at all 4 corner positions on this member (coordinates differ; preparation is identical).

Scaled section along the screw axis. All positions for this member: mark-out sheet first-bed-01-C1-N-fixings.svg.

22

## Seated view - corner screws

step 22 of 42 | drive
through member | receiver

mating plane

head

pen 50 mm

Head bears on the entry face; confirm the seat detail with the actual hardware.

100 mm

Scaled section along the fixed screw axis; not a 1:1 template.

This is how a correctly seated screw looks in section: head bearing on the entry face, point inside the receiver. The head-seat detail must be confirmed with the actual hardware before any course is stacked over driven screws.

Seated view along the screw axis.

23

## Fit corner screws - first-bed-01-C1-S

step 23 of 42 | mark
through member | receiver

mating plane

MARK ONLY - do not drill
100 mm

Scaled section along the fixed screw axis; not a 1:1 template.

Pilot spec UNCONFIRMED: mark the centre only. Do NOT drill or drive until a recorded trial or manufacturer instruction confirms diameter and depth. horizontally into the
OUTER face at U 50 / V 0 / W 50 mm from piece datum A (50, 0, 50 global). Drive wickes-287686 square to the entry face into receiver first-bed-01-C1-W. Nominal penetration 50 mm (includes the point; not rated embedment). Head seat: confirm against
the actual hardware - heads and recesses are NOT modelled. Repeat identically at all 4 corner positions on this member (coordinates differ; preparation is identical).

Scaled section along the screw axis. All positions for this member: mark-out sheet first-bed-01-C1-S-fixings.svg.

24

## Place first-bed-01 course 2

step 24 of 42 | place

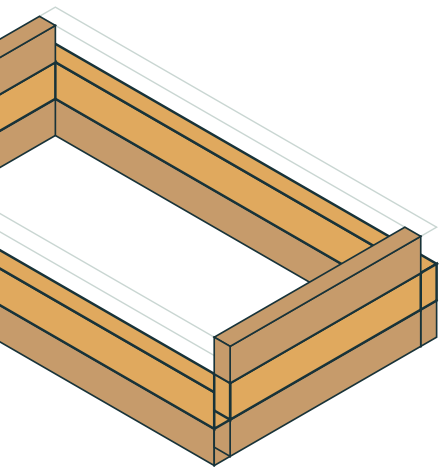
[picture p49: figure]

Lay the course-2 members for first-bed-01 in the drawn positions (outside 2400 x 1400 mm).

25

## Clamp and check first-bed-01 course 2

step 25 of 42 | clamp

Clamp the course, check square (equal outside diagonals) and level. Do not release the clamps until this course's fixings are driven.

26

## Fit stack screws - first-bed-01-C2-E

step 26 of 42 | mark

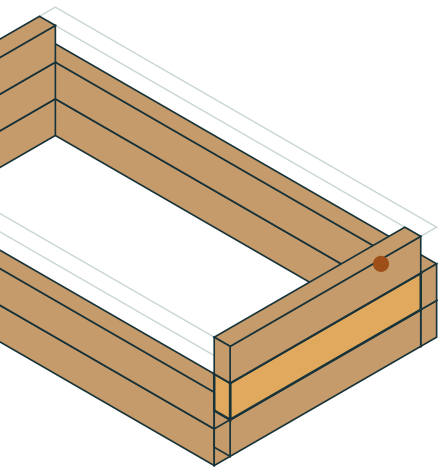
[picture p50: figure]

through member | receiver

mating plane

MARK ONLY - do not drill
200 mm

Scaled section along the fixed screw axis; not a 1:1 template.

Pilot spec UNCONFIRMED: mark the centre only. Do NOT drill or drive until a recorded trial or manufacturer instruction confirms diameter and depth. vertically through the
TOP face at U 200 / V 50 / W 200 mm from piece datum A (2350, 300, 400 global). Drive wickes-287688 square to the entry face into receiver first-bed-01-C1-E. Nominal penetration 50 mm (includes the point; not rated embedment). Head seat: confirm against
the actual hardware - heads and recesses are NOT modelled. Repeat identically at all 3
stack positions on this member (coordinates differ; preparation is identical).

Scaled section along the screw axis. All positions for this member: mark-out sheet first-bed-01-C2-E-fixings.svg.

27

## Seated view - stack screws

step 27 of 42 | drive
through member | receiver

mating plane

head

pen 50 mm

Head bears on the entry face; confirm the seat detail with the actual hardware.

200 mm

Scaled section along the fixed screw axis; not a 1:1 template.

This is how a correctly seated screw looks in section: head bearing on the entry face, point inside the receiver. The head-seat detail must be confirmed with the actual hardware before any course is stacked over driven screws.

Seated view along the screw axis.

28

## Fit corner screws - first-bed-01-C2-N

step 28 of 42 | mark

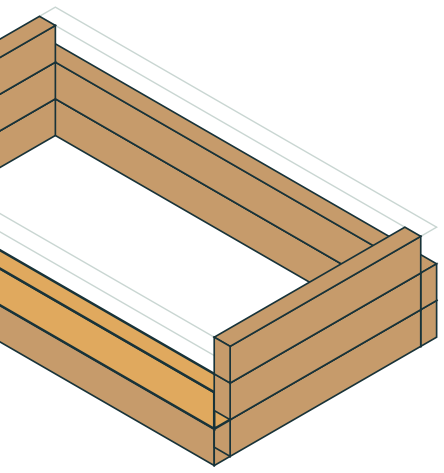
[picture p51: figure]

through member | receiver

mating plane

MARK ONLY - do not drill
100 mm

Scaled section along the fixed screw axis; not a 1:1 template.

Pilot spec UNCONFIRMED: mark the centre only. Do NOT drill or drive until a recorded trial or manufacturer instruction confirms diameter and depth. horizontally into the
OUTER face at U 50 / V 100 / W 50 mm from piece datum A (50, 1400, 250 global). Drive wickes-287686 square to the entry face into receiver first-bed-01-C2-W. Nominal penetration 50 mm (includes the point; not rated embedment). Head seat: confirm against
the actual hardware - heads and recesses are NOT modelled. Repeat identically at all 4 corner positions on this member (coordinates differ; preparation is identical).

Scaled section along the screw axis. All positions for this member: mark-out sheet first-bed-01-C2-N-fixings.svg.

29

## Fit stack screws - first-bed-01-C2-N

step 29 of 42 | mark
through member | receiver

mating plane

MARK ONLY - do not drill
200 mm

Scaled section along the fixed screw axis; not a 1:1 template.

Pilot spec UNCONFIRMED: mark the centre only. Do NOT drill or drive until a recorded trial or manufacturer instruction confirms diameter and depth. vertically through the
TOP face at U 200 / V 50 / W 200 mm from piece datum A (200, 1350, 400 global). Drive wickes-287688 square to the entry face into receiver first-bed-01-C1-N. Nominal penetration 50 mm (includes the point; not rated embedment). Head seat: confirm against
the actual hardware - heads and recesses are NOT modelled. Repeat identically at all 5
stack positions on this member (coordinates differ; preparation is identical).

Scaled section along the screw axis. All positions for this member: mark-out sheet first-bed-01-C2-N-fixings.svg.

30

## Fit corner screws - first-bed-01-C2-S

step 30 of 42 | mark
through member | receiver

mating plane

MARK ONLY - do not drill
100 mm

Scaled section along the fixed screw axis; not a 1:1 template.

Pilot spec UNCONFIRMED: mark the centre only. Do NOT drill or drive until a recorded trial or manufacturer instruction confirms diameter and depth. horizontally into the
OUTER face at U 50 / V 0 / W 50 mm from piece datum A (50, 0, 250 global). Drive wickes-287686 square to the entry face into receiver first-bed-01-C2-W. Nominal penetration 50 mm (includes the point; not rated embedment). Head seat: confirm against
the actual hardware - heads and recesses are NOT modelled. Repeat identically at all 4 corner positions on this member (coordinates differ; preparation is identical).

Scaled section along the screw axis. All positions for this member: mark-out sheet first-bed-01-C2-S-fixings.svg.

31

## Fit stack screws - first-bed-01-C2-S

step 31 of 42 | mark

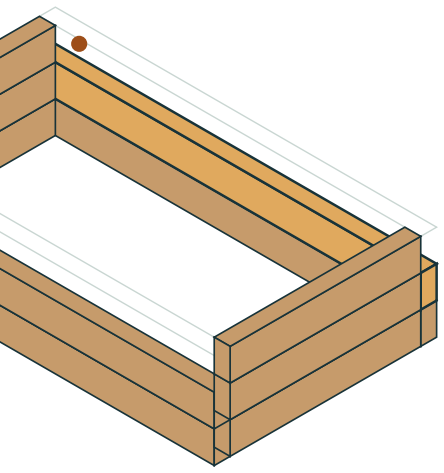
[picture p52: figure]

through member | receiver

mating plane

MARK ONLY - do not drill
200 mm

Scaled section along the fixed screw axis; not a 1:1 template.

Pilot spec UNCONFIRMED: mark the centre only. Do NOT drill or drive until a recorded trial or manufacturer instruction confirms diameter and depth. vertically through the
TOP face at U 200 / V 50 / W 200 mm from piece datum A (200, 50, 400 global). Drive wickes-287688 square to the entry face into receiver first-bed-01-C1-S. Nominal penetration 50 mm (includes the point; not rated embedment). Head seat: confirm against
the actual hardware - heads and recesses are NOT modelled. Repeat identically at all 5
stack positions on this member (coordinates differ; preparation is identical).

Scaled section along the screw axis. All positions for this member: mark-out sheet first-bed-01-C2-S-fixings.svg.

32

## Fit stack screws - first-bed-01-C2-W

step 32 of 42 | mark
through member | receiver

mating plane

MARK ONLY - do not drill
200 mm

Scaled section along the fixed screw axis; not a 1:1 template.

Pilot spec UNCONFIRMED: mark the centre only. Do NOT drill or drive until a recorded trial or manufacturer instruction confirms diameter and depth. vertically through the
TOP face at U 200 / V 50 / W 200 mm from piece datum A (50, 300, 400 global). Drive wickes-287688 square to the entry face into receiver first-bed-01-C1-W. Nominal penetration 50 mm (includes the point; not rated embedment). Head seat: confirm against
the actual hardware - heads and recesses are NOT modelled. Repeat identically at all 3
stack positions on this member (coordinates differ; preparation is identical).

Scaled section along the screw axis. All positions for this member: mark-out sheet first-bed-01-C2-W-fixings.svg.

33

## Place first-bed-01 course 3

step 33 of 42 | place


Lay the course-3 members for first-bed-01 in the drawn positions (outside 2400 x 1400 mm).

34

## Clamp and check first-bed-01 course 3

step 34 of 42 | clamp

Clamp the course, check square (equal outside diagonals) and level. Do not release the clamps until this course's fixings are driven.

35

## Fit stack screws - first-bed-01-C3-E

step 35 of 42 | mark


through member | receiver

mating plane

MARK ONLY - do not drill
200 mm

Scaled section along the fixed screw axis; not a 1:1 template.

Pilot spec UNCONFIRMED: mark the centre only. Do NOT drill or drive until a recorded trial or manufacturer instruction confirms diameter and depth. vertically through the
TOP face at U 240 / V 50 / W 200 mm from piece datum A (2350, 340, 600 global). Drive wickes-287688 square to the entry face into receiver first-bed-01-C2-E. Nominal penetration 50 mm (includes the point; not rated embedment). Head seat: confirm against
the actual hardware - heads and recesses are NOT modelled. Repeat identically at all 3
stack positions on this member (coordinates differ; preparation is identical).

Scaled section along the screw axis. All positions for this member: mark-out sheet first-bed-01-C3-E-fixings.svg.

36

## Fit corner screws - first-bed-01-C3-N

step 36 of 42 | mark


through member | receiver

mating plane

MARK ONLY - do not drill
100 mm

Scaled section along the fixed screw axis; not a 1:1 template.

Pilot spec UNCONFIRMED: mark the centre only. Do NOT drill or drive until a recorded trial or manufacturer instruction confirms diameter and depth. horizontally into the
OUTER face at U 50 / V 100 / W 50 mm from piece datum A (50, 1400, 450 global). Drive wickes-287686 square to the entry face into receiver first-bed-01-C3-W. Nominal penetration 50 mm (includes the point; not rated embedment). Head seat: confirm against
the actual hardware - heads and recesses are NOT modelled. Repeat identically at all 4 corner positions on this member (coordinates differ; preparation is identical).

Scaled section along the screw axis. All positions for this member: mark-out sheet first-bed-01-C3-N-fixings.svg.

37

## Fit stack screws - first-bed-01-C3-N

step 37 of 42 | mark
through member | receiver

mating plane

MARK ONLY - do not drill
200 mm

Scaled section along the fixed screw axis; not a 1:1 template.

Pilot spec UNCONFIRMED: mark the centre only. Do NOT drill or drive until a recorded trial or manufacturer instruction confirms diameter and depth. vertically through the
TOP face at U 240 / V 50 / W 200 mm from piece datum A (240, 1350, 600 global). Drive wickes-287688 square to the entry face into receiver first-bed-01-C2-N. Nominal penetration 50 mm (includes the point; not rated embedment). Head seat: confirm against
the actual hardware - heads and recesses are NOT modelled. Repeat identically at all 5
stack positions on this member (coordinates differ; preparation is identical).

Scaled section along the screw axis. All positions for this member: mark-out sheet first-bed-01-C3-N-fixings.svg.

38

## Fit corner screws - first-bed-01-C3-S

step 38 of 42 | mark


through member | receiver

mating plane

MARK ONLY - do not drill
100 mm

Scaled section along the fixed screw axis; not a 1:1 template.

Pilot spec UNCONFIRMED: mark the centre only. Do NOT drill or drive until a recorded trial or manufacturer instruction confirms diameter and depth. horizontally into the
OUTER face at U 50 / V 0 / W 50 mm from piece datum A (50, 0, 450 global). Drive wickes-287686 square to the entry face into receiver first-bed-01-C3-W. Nominal penetration 50 mm (includes the point; not rated embedment). Head seat: confirm against
the actual hardware - heads and recesses are NOT modelled. Repeat identically at all 4 corner positions on this member (coordinates differ; preparation is identical).

Scaled section along the screw axis. All positions for this member: mark-out sheet first-bed-01-C3-S-fixings.svg.

39

## Fit stack screws - first-bed-01-C3-S

step 39 of 42 | mark
through member | receiver

mating plane

MARK ONLY - do not drill
200 mm

Scaled section along the fixed screw axis; not a 1:1 template.

Pilot spec UNCONFIRMED: mark the centre only. Do NOT drill or drive until a recorded trial or manufacturer instruction confirms diameter and depth. vertically through the
TOP face at U 240 / V 50 / W 200 mm from piece datum A (240, 50, 600 global). Drive wickes-287688 square to the entry face into receiver first-bed-01-C2-S. Nominal penetration 50 mm (includes the point; not rated embedment). Head seat: confirm against
the actual hardware - heads and recesses are NOT modelled. Repeat identically at all 5
stack positions on this member (coordinates differ; preparation is identical).

Scaled section along the screw axis. All positions for this member: mark-out sheet first-bed-01-C3-S-fixings.svg.

40

## Fit stack screws - first-bed-01-C3-W

step 40 of 42 | mark


through member | receiver

mating plane

MARK ONLY - do not drill
200 mm

Scaled section along the fixed screw axis; not a 1:1 template.

Pilot spec UNCONFIRMED: mark the centre only. Do NOT drill or drive until a recorded trial or manufacturer instruction confirms diameter and depth. vertically through the
TOP face at U 240 / V 50 / W 200 mm from piece datum A (50, 340, 600 global). Drive wickes-287688 square to the entry face into receiver first-bed-01-C2-W. Nominal penetration 50 mm (includes the point; not rated embedment). Head seat: confirm against
the actual hardware - heads and recesses are NOT modelled. Repeat identically at all 3
stack positions on this member (coordinates differ; preparation is identical).

Scaled section along the screw axis. All positions for this member: mark-out sheet first-bed-01-C3-W-fixings.svg.

41

## Install reviewed supports, liner and drainage

step 41 of 42 | supports

Fit the separately reviewed restraint/bracing and protection details. Keep the base open-bottomed and drained; never turn the bed into an undrained tank.

42

## Final check and fill to freeboard

step 42 of 42 | final


Re-check level, square and all fixing seats. Fill to the specified freeboard. Record actual purchases, labour, corrections and useful offcuts; merge the inventory proposal only after the job is completed.

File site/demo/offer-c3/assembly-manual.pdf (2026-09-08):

# Assembly guide

## First rectangular bed draft - 2400 x 1400 DRAFT_MARK_OUT_ONLY | as of 2026-09-06 | physical 2724d16028a0

### In this pack

42 numbered steps - one dominant action per step
3D keyframes: highlighted = current part, solid = installed, ghost outline = later Scaled joint sections for every preparation/driving operation
12 labelled parts, 56 fixings, 12 sleepers
Full coordinates in fixings.csv; saw bands in cuts.csv

STOP entries are mark-out only:
where a pilot diameter/depth or head-seat detail is unconfirmed, do not drill or drive until confirmed for the actual hardware. This guide is not structural certification.

1

## Prepare board B001

step 1 of 42 | receive


wickes-276785 | gross 2400 mm | reject twisted, split or unsound stock. Trims: start 0
mm, end 0 mm. Write board ID B001 on the timber and mark datum A. All cut coordinates run from this original A datum, even after squaring. Apply the compatible cut-end preservative per the timber supplier's method before assembly.
Sleeperplan | 8f84fcf99d0a | DRAFT_MARK_OUT_ONLY | 1

2

## Prepare board B002

step 2 of 42 | receive


wickes-276785 | gross 2400 mm | reject twisted, split or unsound stock. Trims: start 0
mm, end 0 mm. Write board ID B002 on the timber and mark datum A. All cut coordinates run from this original A datum, even after squaring. Apply the compatible cut-end preservative per the timber supplier's method before assembly.

3

## Prepare board B003

step 3 of 42 | receive


wickes-276785 | gross 2400 mm | reject twisted, split or unsound stock. Trims: start 0
mm, end 0 mm. Write board ID B003 on the timber and mark datum A. All cut coordinates run from this original A datum, even after squaring. Apply the compatible cut-end preservative per the timber supplier's method before assembly.

4

## Prepare board B004

step 4 of 42 | receive


wickes-276785 | gross 2400 mm | reject twisted, split or unsound stock. Trims: start 0
mm, end 0 mm. Write board ID B004 on the timber and mark datum A. All cut coordinates run from this original A datum, even after squaring. Apply the compatible cut-end preservative per the timber supplier's method before assembly.

5

## Prepare board B005

step 5 of 42 | receive


wickes-276785 | gross 2400 mm | reject twisted, split or unsound stock. Trims: start 0
mm, end 0 mm. Write board ID B005 on the timber and mark datum A. All cut coordinates run from this original A datum, even after squaring. Apply the compatible cut-end preservative per the timber supplier's method before assembly.

6

## Prepare board B006

step 6 of 42 | receive


wickes-276785 | gross 2400 mm | reject twisted, split or unsound stock. Trims: start 0
mm, end 0 mm. Write board ID B006 on the timber and mark datum A. All cut coordinates run from this original A datum, even after squaring. Apply the compatible cut-end preservative per the timber supplier's method before assembly.

7

## Prepare board B007

step 7 of 42 | receive


wickes-256948 | gross 1800 mm | reject twisted, split or unsound stock. Trims: start 0
mm, end 0 mm. Write board ID B007 on the timber and mark datum A. All cut coordinates run from this original A datum, even after squaring. Apply the compatible cut-end preservative per the timber supplier's method before assembly.

8

## Crosscut; keep piece on datum side B007 @ 1201.5 mm

step 8 of 42 | cut

crosscut; keep piece on datum side at blade centre 1201.5 mm from A. Kerf band 1200..1203 mm is WASTE - do not centre the blade on a finished-length boundary. One complete crosscut through the section.

9

## Prepare board B008

step 9 of 42 | receive
wickes-256948 | gross 1800 mm | reject twisted, split or unsound stock. Trims: start 0
mm, end 0 mm. Write board ID B008 on the timber and mark datum A. All cut coordinates run from this original A datum, even after squaring. Apply the compatible cut-end preservative per the timber supplier's method before assembly.

10

## Crosscut; keep piece on datum side B008 @ 1201.5 mm

step 10 of 42 | cut


crosscut; keep piece on datum side at blade centre 1201.5 mm from A. Kerf band 1200..1203 mm is WASTE - do not centre the blade on a finished-length boundary. One complete crosscut through the section.

11

## Prepare board B009

step 11 of 42 | receive
wickes-256948 | gross 1800 mm | reject twisted, split or unsound stock. Trims: start 0
mm, end 0 mm. Write board ID B009 on the timber and mark datum A. All cut coordinates run from this original A datum, even after squaring. Apply the compatible cut-end preservative per the timber supplier's method before assembly.

12

## Crosscut; keep piece on datum side B009 @ 1201.5 mm

step 12 of 42 | cut


crosscut; keep piece on datum side at blade centre 1201.5 mm from A. Kerf band 1200..1203 mm is WASTE - do not centre the blade on a finished-length boundary. One complete crosscut through the section.

13

## Prepare board B010

step 13 of 42 | receive
wickes-256948 | gross 1800 mm | reject twisted, split or unsound stock. Trims: start 0
mm, end 0 mm. Write board ID B010 on the timber and mark datum A. All cut coordinates run from this original A datum, even after squaring. Apply the compatible cut-end preservative per the timber supplier's method before assembly.

14

## Crosscut; keep piece on datum side B010 @ 1201.5 mm

step 14 of 42 | cut

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

15

## Prepare board B011

step 15 of 42 | receive


wickes-256948 | gross 1800 mm | reject twisted, split or unsound stock. Trims: start 0
mm, end 0 mm. Write board ID B011 on the timber and mark datum A. All cut coordinates run from this original A datum, even after squaring. Apply the compatible cut-end preservative per the timber supplier's method before assembly.

16

## Crosscut; keep piece on datum side B011 @ 1201.5 mm

step 16 of 42 | cut

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

17

## Prepare board B012

step 17 of 42 | receive


wickes-256948 | gross 1800 mm | reject twisted, split or unsound stock. Trims: start 0
mm, end 0 mm. Write board ID B012 on the timber and mark datum A. All cut coordinates run from this original A datum, even after squaring. Apply the compatible cut-end preservative per the timber supplier's method before assembly.

18

## Crosscut; keep piece on datum side B012 @ 1201.5 mm

step 18 of 42 | cut

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

19

## Place first-bed-01 course 1

step 19 of 42 | place


Lay the course-1 members for first-bed-01 in the drawn positions (outside 2400 x 1400 mm).

20

## Clamp and check first-bed-01 course 1

step 20 of 42 | clamp

Clamp the course, check square (equal outside diagonals) and level. Do not release the clamps until this course's fixings are driven.

21

## Fit corner screws - first-bed-01-C1-N

step 21 of 42 | mark


through member | receiver

mating plane

MARK ONLY - do not drill
100 mm

Scaled section along the fixed screw axis; not a 1:1 template.

Pilot spec UNCONFIRMED: mark the centre only. Do NOT drill or drive until a recorded trial or manufacturer instruction confirms diameter and depth. horizontally into the
OUTER face at U 50 / V 100 / W 50 mm from piece datum A (50, 1400, 50 global). Drive wickes-287686 square to the entry face into receiver first-bed-01-C1-W. Nominal penetration 50 mm (includes the point; not rated embedment). Head seat: confirm against
the actual hardware - heads and recesses are NOT modelled. Repeat identically at all 4 corner positions on this member (coordinates differ; preparation is identical).

Scaled section along the screw axis. All positions for this member: mark-out sheet first-bed-01-C1-N-fixings.svg.

22

## Seated view - corner screws

step 22 of 42 | drive
through member | receiver

mating plane

head

pen 50 mm

Head bears on the entry face; confirm the seat detail with the actual hardware.

100 mm

Scaled section along the fixed screw axis; not a 1:1 template.

This is how a correctly seated screw looks in section: head bearing on the entry face, point inside the receiver. The head-seat detail must be confirmed with the actual hardware before any course is stacked over driven screws.

Seated view along the screw axis.

23

## Fit corner screws - first-bed-01-C1-S

step 23 of 42 | mark
through member | receiver

mating plane

MARK ONLY - do not drill
100 mm

Scaled section along the fixed screw axis; not a 1:1 template.

Pilot spec UNCONFIRMED: mark the centre only. Do NOT drill or drive until a recorded trial or manufacturer instruction confirms diameter and depth. horizontally into the
OUTER face at U 50 / V 0 / W 50 mm from piece datum A (50, 0, 50 global). Drive wickes-287686 square to the entry face into receiver first-bed-01-C1-W. Nominal penetration 50 mm (includes the point; not rated embedment). Head seat: confirm against
the actual hardware - heads and recesses are NOT modelled. Repeat identically at all 4 corner positions on this member (coordinates differ; preparation is identical).

Scaled section along the screw axis. All positions for this member: mark-out sheet first-bed-01-C1-S-fixings.svg.

24

## Place first-bed-01 course 2

step 24 of 42 | place


Lay the course-2 members for first-bed-01 in the drawn positions (outside 2400 x 1400 mm).

25

## Clamp and check first-bed-01 course 2

step 25 of 42 | clamp

Clamp the course, check square (equal outside diagonals) and level. Do not release the clamps until this course's fixings are driven.

26

## Fit stack screws - first-bed-01-C2-E

step 26 of 42 | mark


through member | receiver

mating plane

MARK ONLY - do not drill
200 mm

Scaled section along the fixed screw axis; not a 1:1 template.

Pilot spec UNCONFIRMED: mark the centre only. Do NOT drill or drive until a recorded trial or manufacturer instruction confirms diameter and depth. vertically through the
TOP face at U 200 / V 50 / W 200 mm from piece datum A (2350, 300, 400 global). Drive wickes-287688 square to the entry face into receiver first-bed-01-C1-E. Nominal penetration 50 mm (includes the point; not rated embedment). Head seat: confirm against
the actual hardware - heads and recesses are NOT modelled. Repeat identically at all 3
stack positions on this member (coordinates differ; preparation is identical).

Scaled section along the screw axis. All positions for this member: mark-out sheet first-bed-01-C2-E-fixings.svg.

27

## Seated view - stack screws

step 27 of 42 | drive
through member | receiver

mating plane

head

pen 50 mm

Head bears on the entry face; confirm the seat detail with the actual hardware.

200 mm

Scaled section along the fixed screw axis; not a 1:1 template.

This is how a correctly seated screw looks in section: head bearing on the entry face, point inside the receiver. The head-seat detail must be confirmed with the actual hardware before any course is stacked over driven screws.

Seated view along the screw axis.

28

## Fit corner screws - first-bed-01-C2-N

step 28 of 42 | mark


through member | receiver

mating plane

MARK ONLY - do not drill
100 mm

Scaled section along the fixed screw axis; not a 1:1 template.

Pilot spec UNCONFIRMED: mark the centre only. Do NOT drill or drive until a recorded trial or manufacturer instruction confirms diameter and depth. horizontally into the
OUTER face at U 50 / V 100 / W 50 mm from piece datum A (50, 1400, 250 global). Drive wickes-287686 square to the entry face into receiver first-bed-01-C2-W. Nominal penetration 50 mm (includes the point; not rated embedment). Head seat: confirm against
the actual hardware - heads and recesses are NOT modelled. Repeat identically at all 4 corner positions on this member (coordinates differ; preparation is identical).

Scaled section along the screw axis. All positions for this member: mark-out sheet first-bed-01-C2-N-fixings.svg.

29

## Fit stack screws - first-bed-01-C2-N

step 29 of 42 | mark
through member | receiver

mating plane

MARK ONLY - do not drill
200 mm

Scaled section along the fixed screw axis; not a 1:1 template.

Pilot spec UNCONFIRMED: mark the centre only. Do NOT drill or drive until a recorded trial or manufacturer instruction confirms diameter and depth. vertically through the
TOP face at U 200 / V 50 / W 200 mm from piece datum A (200, 1350, 400 global). Drive wickes-287688 square to the entry face into receiver first-bed-01-C1-N. Nominal penetration 50 mm (includes the point; not rated embedment). Head seat: confirm against
the actual hardware - heads and recesses are NOT modelled. Repeat identically at all 5
stack positions on this member (coordinates differ; preparation is identical).

Scaled section along the screw axis. All positions for this member: mark-out sheet first-bed-01-C2-N-fixings.svg.

30

## Fit corner screws - first-bed-01-C2-S

step 30 of 42 | mark
through member | receiver

mating plane

MARK ONLY - do not drill
100 mm

Scaled section along the fixed screw axis; not a 1:1 template.

Pilot spec UNCONFIRMED: mark the centre only. Do NOT drill or drive until a recorded trial or manufacturer instruction confirms diameter and depth. horizontally into the
OUTER face at U 50 / V 0 / W 50 mm from piece datum A (50, 0, 250 global). Drive wickes-287686 square to the entry face into receiver first-bed-01-C2-W. Nominal penetration 50 mm (includes the point; not rated embedment). Head seat: confirm against
the actual hardware - heads and recesses are NOT modelled. Repeat identically at all 4 corner positions on this member (coordinates differ; preparation is identical).

Scaled section along the screw axis. All positions for this member: mark-out sheet first-bed-01-C2-S-fixings.svg.

31

## Fit stack screws - first-bed-01-C2-S

step 31 of 42 | mark


through member | receiver

mating plane

MARK ONLY - do not drill
200 mm

Scaled section along the fixed screw axis; not a 1:1 template.

Pilot spec UNCONFIRMED: mark the centre only. Do NOT drill or drive until a recorded trial or manufacturer instruction confirms diameter and depth. vertically through the
TOP face at U 200 / V 50 / W 200 mm from piece datum A (200, 50, 400 global). Drive wickes-287688 square to the entry face into receiver first-bed-01-C1-S. Nominal penetration 50 mm (includes the point; not rated embedment). Head seat: confirm against
the actual hardware - heads and recesses are NOT modelled. Repeat identically at all 5
stack positions on this member (coordinates differ; preparation is identical).

Scaled section along the screw axis. All positions for this member: mark-out sheet first-bed-01-C2-S-fixings.svg.

32

## Fit stack screws - first-bed-01-C2-W

step 32 of 42 | mark
through member | receiver

mating plane

MARK ONLY - do not drill
200 mm

Scaled section along the fixed screw axis; not a 1:1 template.

Pilot spec UNCONFIRMED: mark the centre only. Do NOT drill or drive until a recorded trial or manufacturer instruction confirms diameter and depth. vertically through the
TOP face at U 200 / V 50 / W 200 mm from piece datum A (50, 300, 400 global). Drive wickes-287688 square to the entry face into receiver first-bed-01-C1-W. Nominal penetration 50 mm (includes the point; not rated embedment). Head seat: confirm against
the actual hardware - heads and recesses are NOT modelled. Repeat identically at all 3
stack positions on this member (coordinates differ; preparation is identical).

Scaled section along the screw axis. All positions for this member: mark-out sheet first-bed-01-C2-W-fixings.svg.

33

## Place first-bed-01 course 3

step 33 of 42 | place


Lay the course-3 members for first-bed-01 in the drawn positions (outside 2400 x 1400 mm).

34

## Clamp and check first-bed-01 course 3

step 34 of 42 | clamp

Clamp the course, check square (equal outside diagonals) and level. Do not release the clamps until this course's fixings are driven.

35

## Fit stack screws - first-bed-01-C3-E

step 35 of 42 | mark


through member | receiver

mating plane

MARK ONLY - do not drill
200 mm

Scaled section along the fixed screw axis; not a 1:1 template.

Pilot spec UNCONFIRMED: mark the centre only. Do NOT drill or drive until a recorded trial or manufacturer instruction confirms diameter and depth. vertically through the
TOP face at U 240 / V 50 / W 200 mm from piece datum A (2350, 340, 600 global). Drive wickes-287688 square to the entry face into receiver first-bed-01-C2-E. Nominal penetration 50 mm (includes the point; not rated embedment). Head seat: confirm against
the actual hardware - heads and recesses are NOT modelled. Repeat identically at all 3
stack positions on this member (coordinates differ; preparation is identical).

Scaled section along the screw axis. All positions for this member: mark-out sheet first-bed-01-C3-E-fixings.svg.

36

## Fit corner screws - first-bed-01-C3-N

step 36 of 42 | mark


through member | receiver

mating plane

MARK ONLY - do not drill
100 mm

Scaled section along the fixed screw axis; not a 1:1 template.

Pilot spec UNCONFIRMED: mark the centre only. Do NOT drill or drive until a recorded trial or manufacturer instruction confirms diameter and depth. horizontally into the
OUTER face at U 50 / V 100 / W 50 mm from piece datum A (50, 1400, 450 global). Drive wickes-287686 square to the entry face into receiver first-bed-01-C3-W. Nominal penetration 50 mm (includes the point; not rated embedment). Head seat: confirm against
the actual hardware - heads and recesses are NOT modelled. Repeat identically at all 4 corner positions on this member (coordinates differ; preparation is identical).

Scaled section along the screw axis. All positions for this member: mark-out sheet first-bed-01-C3-N-fixings.svg.

37

## Fit stack screws - first-bed-01-C3-N

step 37 of 42 | mark
through member | receiver

mating plane

MARK ONLY - do not drill
200 mm

Scaled section along the fixed screw axis; not a 1:1 template.

Pilot spec UNCONFIRMED: mark the centre only. Do NOT drill or drive until a recorded trial or manufacturer instruction confirms diameter and depth. vertically through the
TOP face at U 240 / V 50 / W 200 mm from piece datum A (240, 1350, 600 global). Drive wickes-287688 square to the entry face into receiver first-bed-01-C2-N. Nominal penetration 50 mm (includes the point; not rated embedment). Head seat: confirm against
the actual hardware - heads and recesses are NOT modelled. Repeat identically at all 5
stack positions on this member (coordinates differ; preparation is identical).

Scaled section along the screw axis. All positions for this member: mark-out sheet first-bed-01-C3-N-fixings.svg.

38

## Fit corner screws - first-bed-01-C3-S

step 38 of 42 | mark


through member | receiver

mating plane

MARK ONLY - do not drill
100 mm

Scaled section along the fixed screw axis; not a 1:1 template.

Pilot spec UNCONFIRMED: mark the centre only. Do NOT drill or drive until a recorded trial or manufacturer instruction confirms diameter and depth. horizontally into the
OUTER face at U 50 / V 0 / W 50 mm from piece datum A (50, 0, 450 global). Drive wickes-287686 square to the entry face into receiver first-bed-01-C3-W. Nominal penetration 50 mm (includes the point; not rated embedment). Head seat: confirm against
the actual hardware - heads and recesses are NOT modelled. Repeat identically at all 4 corner positions on this member (coordinates differ; preparation is identical).

Scaled section along the screw axis. All positions for this member: mark-out sheet first-bed-01-C3-S-fixings.svg.

39

## Fit stack screws - first-bed-01-C3-S

step 39 of 42 | mark
through member | receiver

mating plane

MARK ONLY - do not drill
200 mm

Scaled section along the fixed screw axis; not a 1:1 template.

Pilot spec UNCONFIRMED: mark the centre only. Do NOT drill or drive until a recorded trial or manufacturer instruction confirms diameter and depth. vertically through the
TOP face at U 240 / V 50 / W 200 mm from piece datum A (240, 50, 600 global). Drive wickes-287688 square to the entry face into receiver first-bed-01-C2-S. Nominal penetration 50 mm (includes the point; not rated embedment). Head seat: confirm against
the actual hardware - heads and recesses are NOT modelled. Repeat identically at all 5
stack positions on this member (coordinates differ; preparation is identical).

Scaled section along the screw axis. All positions for this member: mark-out sheet first-bed-01-C3-S-fixings.svg.

40

## Fit stack screws - first-bed-01-C3-W

step 40 of 42 | mark


through member | receiver

mating plane

MARK ONLY - do not drill
200 mm

Scaled section along the fixed screw axis; not a 1:1 template.

Pilot spec UNCONFIRMED: mark the centre only. Do NOT drill or drive until a recorded trial or manufacturer instruction confirms diameter and depth. vertically through the
TOP face at U 240 / V 50 / W 200 mm from piece datum A (50, 340, 600 global). Drive wickes-287688 square to the entry face into receiver first-bed-01-C2-W. Nominal penetration 50 mm (includes the point; not rated embedment). Head seat: confirm against
the actual hardware - heads and recesses are NOT modelled. Repeat identically at all 3
stack positions on this member (coordinates differ; preparation is identical).

Scaled section along the screw axis. All positions for this member: mark-out sheet first-bed-01-C3-W-fixings.svg.

41

## Install reviewed supports, liner and drainage

step 41 of 42 | supports

Fit the separately reviewed restraint/bracing and protection details. Keep the base open-bottomed and drained; never turn the bed into an undrained tank.

42

## Final check and fill to freeboard

step 42 of 42 | final


Re-check level, square and all fixing seats. Fill to the specified freeboard. Record actual purchases, labour, corrections and useful offcuts; merge the inventory proposal only after the job is completed.

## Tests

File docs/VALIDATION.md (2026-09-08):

# Validation record

## Executed in the build environment

Date: 6 September 2026. Environment: Linux, CPython 3.13.5. The optional ReportLab renderer was available.

`python -m unittest discover -v`: **83 tests passed**. Within those tests are:

- 200 seeded rectangular-ring geometry cases.
- 40 seeded fixing-layout cases, checking all modelled pairs of screw shafts.
- 100 seeded cutting/material-conservation cases.
- 70 small cutting-stock instances checked against an independent exhaustive subset-partition oracle.
- The same plan exported twice and compared byte-for-byte, including optional PDFs.
- CLI checks, explicit release failures, independent height alternatives, bad inputs, finite inventory, saw kerf/end trims, screw pack rounding and incomplete-cost handling.

The example three-course plan, the two/three-course comparison, and a multi-bed batch were also generated with the real CLI. SVGs and rendered PDF pages were inspected for geometry, coordinate labels and legibility. The tests do not prove all possible combinations correct; the supported model and explicit rejects are documented in ENGINEERING.md.

## Included but not executed here

A GitHub Actions matrix is provided for **native Windows and Ubuntu, Python 3.11 and 3.13**, plus optional PDF output on Ubuntu. CI currently verifies generation of OpenSCAD source only; external OpenSCAD compilation is verified on native Windows via the health script.

## Executed on Native Windows host

Date: 6 September 2026. Environment: Windows 11, CPython 3.12.10 (64-bit), PowerShell / CMD.

- Virtual environment `.venv` created and package installed in editable mode (`pip install -e ".[pdf]" pytest ruff`).
- Full test suite execution: `python -m unittest discover -v` and `pytest -v` — **83 passed, 60 subtests passed** in 3.0s.
- Native PowerShell and CMD runners verified (`health.cmd`, `health.ps1`, `sleeperplan.cmd`).
- OpenSCAD 2021.01 installation detected and compile smoke test run (`demo/batch/model.scad` to CSG) through `health.ps1`.
- Batch planning, multi-option comparison (`compare`), and vector PDF generation verified with ReportLab 4.5.1 (`height-comparison.pdf`, `workshop.pdf`).
- Release review pipeline tested end-to-end with confirmed pilot specifications and full job costing (`examples/reviewed-example.json`), successfully generating `REVIEWED_WORKSHOP_PLAN`.

## Not physically validated

No real timber was cut or drilled for this delivery. No site was surveyed. The neighbour's measurements, branch stock, timber condition, real saw kerf, exact screw pilot specification, connection strength, bracing/supports, soil pressure, foundation or drainage detail have been verified on site. The shipped examples therefore remain **DRAFT_MARK_OUT_ONLY**, and `--release` rejects them.

This is a working software foundation and a field-trial workflow, not a certified kit design. Field corrections should become regression tests before standardising the installation service or offering kits for sale.

## Static customer visualiser checks

Date: 7 September 2026. Environment: Windows 11 + Vercel production deployment.

- Confirmed `site/` deploys as static assets via Vercel and serves the production alias.
- Verified offer manifests resolve for all three options: `demo/offer-c1`, `demo/offer-c2`, `demo/offer-c3`.
- Verified module loading is self-contained (`site/vendor/three.module.js`, `site/vendor/OrbitControls.module.js`) to avoid browser import-specifier failures.
- Verified viewer camera uses Z-up orientation and renders course boundaries with explicit per-piece edge lines.
- Verified client links surface assembled/process/manual/PDF artifacts from manifest paths.

These checks validate web presentation and integration, not structural correctness. Release gating and pilot evidence requirements are unchanged.

## v0.3.0 hardening checks

Date: 8 September 2026. Environment: Windows 11, CPython 3.12.10. Full suite: `python -m unittest discover -v` — **99 tests passed**.

New regression coverage, each tied to a review finding (REVIEW_37db13b):

- **Publication gate (F01):** the tracked public tree (`published/`, `site/demo`) contains no `REVIEWED_WORKSHOP_PLAN`; every published manifest matches its plan's `input_sha256`; published bundles ship `operations.json`. Stale `build/` packs were removed and `build/` is git-ignored again.
- **Price-independent hardware (F02):** with two competing same-length screws, repricing changes neither the selected screw nor the `physical_design_hash`; commercial rules (spares %, price-age) also do not move the physical hash.
- **Fixture evidence (F04):** `pilot_evidence_kind` is required for confirmed pilot modes; fixture evidence blocks issuance even with a matching approval hash; `recorded_trial` evidence can release.
- **Unified readiness (F05):** a missing approval hash is a blocker in draft/check (`release_ready: false`), not only at `--release`.
- **Options PDF (per-height content):** deterministic per-height sections; workshop/options PDFs paginate parts boards with table-only continuation pages and paginate stock boards (8/page); `options-and-build.pdf` byte-reproducible.
- **Viewer fixes (F11/F12/F14):** DPR-correct resize tracking, per-bed display groups, recursive geometry disposal, manifest↔plan hash refusal; verified by JS syntax check and deployed-bundle fetches (offer manifests + `operations.json` for all three heights return `sleeperplan.operations.v1` with matching plan hashes).

Not yet executable in software: physical joint/head-seat confirmation (F03) and browser-level interaction tests; the assembly player's screw insertion is deterministic by construction but needs on-screen review with the trial hardware.

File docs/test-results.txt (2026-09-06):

test_bad_job_returns_clean_error (tests.test_cli_exports.CLITests.test_bad_job_returns_clean_error) ... ok
test_check_draft_has_distinct_exit_code (tests.test_cli_exports.CLITests.test_check_draft_has_distinct_exit_code) ... ok
test_compare_generates_independent_alternatives (tests.test_cli_exports.CLITests.test_compare_generates_independent_alternatives) ... ok
test_help (tests.test_cli_exports.CLITests.test_help) ... ok
test_release_fails_without_leaving_partial_output (tests.test_cli_exports.CLITests.test_release_fails_without_leaving_partial_output) ... ok
test_version (tests.test_cli_exports.CLITests.test_version) ... ok
test_csv_formula_injection_protection (tests.test_cli_exports.ExportTests.test_csv_formula_injection_protection) ... ok
test_existing_output_is_not_overwritten (tests.test_cli_exports.ExportTests.test_existing_output_is_not_overwritten) ... ok
test_export_complete_and_reproducible (tests.test_cli_exports.ExportTests.test_export_complete_and_reproducible) ... ok
test_optional_pdf_generation (tests.test_cli_exports.ExportTests.test_optional_pdf_generation) ... ok
test_scad_uses_model_dimensions (tests.test_cli_exports.ExportTests.test_scad_uses_model_dimensions) ... ok
test_svg_is_valid_xml (tests.test_cli_exports.ExportTests.test_svg_is_valid_xml) ... ok
test_all_examples_parse_and_plan (tests.test_config_costs.ConfigTests.test_all_examples_parse_and_plan) ... ok
test_bad_date (tests.test_config_costs.ConfigTests.test_bad_date) ... ok
test_bad_pilot_mode (tests.test_config_costs.ConfigTests.test_bad_pilot_mode) ... ok
test_bool_not_integer (tests.test_config_costs.ConfigTests.test_bool_not_integer) ... ok
test_duplicate_stock_ids (tests.test_config_costs.ConfigTests.test_duplicate_stock_ids) ... ok
test_margin_less_than_100_percent (tests.test_config_costs.ConfigTests.test_margin_less_than_100_percent) ... ok
test_measured_section_override (tests.test_config_costs.ConfigTests.test_measured_section_override) ... ok
test_missing_labour_rate (tests.test_config_costs.ConfigTests.test_missing_labour_rate) ... ok
test_mm_not_metres (tests.test_config_costs.ConfigTests.test_mm_not_metres) ... ok
test_negative_price (tests.test_config_costs.ConfigTests.test_negative_price) ... ok
test_negative_quantity (tests.test_config_costs.ConfigTests.test_negative_quantity) ... ok
test_no_path_traversal_ids (tests.test_config_costs.ConfigTests.test_no_path_traversal_ids) ... ok
test_no_unlimited_inventory (tests.test_config_costs.ConfigTests.test_no_unlimited_inventory) ... ok
test_non_integer_pence (tests.test_config_costs.ConfigTests.test_non_integer_pence) ... ok
test_pilot_depth_not_beyond_screw_tip (tests.test_config_costs.ConfigTests.test_pilot_depth_not_beyond_screw_tip) ... ok
test_pilot_needs_diameter_and_depth (tests.test_config_costs.ConfigTests.test_pilot_needs_diameter_and_depth) ... ok
test_pilot_needs_evidence (tests.test_config_costs.ConfigTests.test_pilot_needs_evidence) ... ok
test_quantity_limit (tests.test_config_costs.ConfigTests.test_quantity_limit) ... ok
test_relative_catalogue_from_another_working_directory (tests.test_config_costs.ConfigTests.test_relative_catalogue_from_another_working_directory) ... ok
test_trim_at_least_kerf (tests.test_config_costs.ConfigTests.test_trim_at_least_kerf) ... ok
test_unknown_fields_rejected (tests.test_config_costs.ConfigTests.test_unknown_fields_rejected) ... ok
test_unknown_site_type (tests.test_config_costs.ConfigTests.test_unknown_site_type) ... ok
test_zero_cavity (tests.test_config_costs.ConfigTests.test_zero_cavity) ... ok
test_global_pack_rounding_not_one_pack_per_bed (tests.test_config_costs.CostAndGateTests.test_global_pack_rounding_not_one_pack_per_bed) ... ok
test_hash_changes_when_kerf_changes (tests.test_config_costs.CostAndGateTests.test_hash_changes_when_kerf_changes) ... ok
test_hash_deterministic (tests.test_config_costs.CostAndGateTests.test_hash_deterministic) ... ok
test_height_limit_not_mislabeled_as_strength (tests.test_config_costs.CostAndGateTests.test_height_limit_not_mislabeled_as_strength) ... ok
test_inventory_proposal_never_mutates_input (tests.test_config_costs.CostAndGateTests.test_inventory_proposal_never_mutates_input) ... ok
test_margin_not_markup_and_labour_rounded (tests.test_config_costs.CostAndGateTests.test_margin_not_markup_and_labour_rounded) ... ok
test_out_of_scope_sites_block_release (tests.test_config_costs.CostAndGateTests.test_out_of_scope_sites_block_release) ... ok
test_pack_rounding_and_spares (tests.test_config_costs.CostAndGateTests.test_pack_rounding_and_spares) ... ok
test_recorded_review_release (tests.test_config_costs.CostAndGateTests.test_recorded_review_release) ... ok
test_release_refuses_unreviewed_job (tests.test_config_costs.CostAndGateTests.test_release_refuses_unreviewed_job) ... ok
test_release_requires_pilot_confirmation_even_if_other_flags_true (tests.test_config_costs.CostAndGateTests.test_release_requires_pilot_confirmation_even_if_other_flags_true) ... ok
test_stale_prices_visible (tests.test_config_costs.CostAndGateTests.test_stale_prices_visible) ... ok
test_unknown_cost_blocks_target_price (tests.test_config_costs.CostAndGateTests.test_unknown_cost_blocks_target_price) ... ok
test_unknowns_not_zero (tests.test_config_costs.CostAndGateTests.test_unknowns_not_zero) ... ok
test_allocation_is_one_to_one (tests.test_cutting.CuttingTests.test_allocation_is_one_to_one) ... ok
test_cheapest_purchase_not_fewest_boards (tests.test_cutting.CuttingTests.test_cheapest_purchase_not_fewest_boards) ... ok
test_default_job_golden_counts (tests.test_cutting.CuttingTests.test_default_job_golden_counts) ... ok
test_exact_cost_matches_independent_oracle_70_cases (tests.test_cutting.CuttingTests.test_exact_cost_matches_independent_oracle_70_cases) ... ok
test_exact_final_piece_does_not_need_phantom_cut (tests.test_cutting.CuttingTests.test_exact_final_piece_does_not_need_phantom_cut) ... ok
test_exhausted_budget_labels_heuristic (tests.test_cutting.CuttingTests.test_exhausted_budget_labels_heuristic) ... ok
test_finite_stock_infeasibility (tests.test_cutting.CuttingTests.test_finite_stock_infeasibility) ... ok
test_full_nominal_length_impossible_after_trim (tests.test_cutting.CuttingTests.test_full_nominal_length_impossible_after_trim) ... ok
test_full_uncut_stock_needs_zero_cuts (tests.test_cutting.CuttingTests.test_full_uncut_stock_needs_zero_cuts) ... ok
test_mixed_lengths_and_finite_inventory (tests.test_cutting.CuttingTests.test_mixed_lengths_and_finite_inventory) ... ok
test_reusable_offcut_threshold (tests.test_cutting.CuttingTests.test_reusable_offcut_threshold) ... ok
test_seeded_conservation_100_cases (tests.test_cutting.CuttingTests.test_seeded_conservation_100_cases) ... ok
test_terminal_sliver_not_treated_as_full_kerf (tests.test_cutting.CuttingTests.test_terminal_sliver_not_treated_as_full_kerf) ... ok
test_trim_includes_kerf_without_double_count (tests.test_cutting.CuttingTests.test_trim_includes_kerf_without_double_count) ... ok
test_two_1200_do_not_fit_2400 (tests.test_cutting.CuttingTests.test_two_1200_do_not_fit_2400) ... ok
test_two_short_pieces_need_two_cuts_if_tail_remains (tests.test_cutting.CuttingTests.test_two_short_pieces_need_two_cuts_if_tail_remains) ... ok
test_unsupported_splice_is_not_invented (tests.test_cutting.CuttingTests.test_unsupported_splice_is_not_invented) ... ok
test_52_fixing_entries (tests.test_geometry.GeometryTests.test_52_fixing_entries) ... ok
test_absent_long_screws_fail_not_shorten (tests.test_geometry.GeometryTests.test_absent_long_screws_fail_not_shorten) ... ok
test_all_screw_tips_in_named_receiver (tests.test_geometry.GeometryTests.test_all_screw_tips_in_named_receiver) ... ok
test_all_sections_uniform (tests.test_geometry.GeometryTests.test_all_sections_uniform) ... ok
test_alternating_exact_lengths (tests.test_geometry.GeometryTests.test_alternating_exact_lengths) ... ok
test_cavity_and_fill (tests.test_geometry.GeometryTests.test_cavity_and_fill) ... ok
test_corner_entry_faces_not_end_faces (tests.test_geometry.GeometryTests.test_corner_entry_faces_not_end_faces) ... ok
test_first_course_never_screws_down_into_ground (tests.test_geometry.GeometryTests.test_first_course_never_screws_down_into_ground) ... ok
test_flat_orientation_swaps_hardware_lengths (tests.test_geometry.GeometryTests.test_flat_orientation_swaps_hardware_lengths) ... ok
test_local_world_roundtrip (tests.test_geometry.GeometryTests.test_local_world_roundtrip) ... ok
test_long_through_option_is_not_silently_interlocked (tests.test_geometry.GeometryTests.test_long_through_option_is_not_silently_interlocked) ... ok
test_multiple_beds_have_unique_parts_and_fixings (tests.test_geometry.GeometryTests.test_multiple_beds_have_unique_parts_and_fixings) ... ok
test_screw_paths_are_pairwise_clear (tests.test_geometry.GeometryTests.test_screw_paths_are_pairwise_clear) ... ok
test_seeded_fixing_geometry_40_cases (tests.test_geometry.GeometryTests.test_seeded_fixing_geometry_40_cases) ... ok
test_seeded_ring_geometry_invariants_200_cases (tests.test_geometry.GeometryTests.test_seeded_ring_geometry_invariants_200_cases) ... ok
test_stack_fixings_stagger_between_courses (tests.test_geometry.GeometryTests.test_stack_fixings_stagger_between_courses) ... ok
test_stack_screws_have_correct_penetration (tests.test_geometry.GeometryTests.test_stack_screws_have_correct_penetration) ... ok

----------------------------------------------------------------------
Ran 83 tests in 6.056s

OK

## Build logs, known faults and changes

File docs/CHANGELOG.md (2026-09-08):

# Changelog

## 2026-09-08 (v0.4.0) — IKEA-style assembly manual + animation upgrade

### Added
- **`assembly-manual.pdf`** (`sleeperplan/manual.py` + `pdf.py`): a numbered, one-action-per-page step guide compiled from the same operations as the web player:
  - 3D keyframe per panel: active part highlighted, installed parts solid, pending parts ghost outlines, orange marker on the active fixing's entry point.
  - Scaled joint cross-sections (`joint_closeup_scene`): entry face, mating plane, receiver continuation, penetration/depth datum; mark-ONLY, drill and seated-drive variants.
  - Equivalent fixings grouped with explicit repeat counts and mark-out sheet references (3-course guide: 43 panels).
  - Deterministic output (byte-identical regeneration, regression-tested).
- **Animation upgrades** (`site/app.js`): ghosted timber on close-up operations, drill-bit model at the entry axis during drill steps, persistent drilled holes that remain visible once made, deterministic per-step tooling state.
- **F10 fixes:** piece-sheet callouts now select one representative per operation type (corner + stack); vertical drilling directions draw the into-page symbol instead of a zero-length line.
- Hardware-agnostic wording throughout the manual ("the actual hardware"); Wickes remains a dated price snapshot only.

### Changed
- "OUTER outer face" wording fix in operation details; manual merges prepare+drive per fixing group.
- Version 0.4.0; 100 tests passing. Published/demo bundles regenerated (v04).

## 2026-09-08 (v0.3.0) — review-of-review hardening (REVIEW_37db13b)

### Added
- **Operations model** (`sleeperplan/operations.py`): every export now compiles a deterministic, ordered workshop operation schedule (`operations.json`, schema `sleeperplan.operations.v1`) — receive/label/cut/treat per board, place/clamp per course, then mark (STOP) or drill + drive per fixing, then supports/final checks. Dependencies are explicit; unknown pilot specs surface as STOP operations, never invented instructions.
- **Assembly player** on the customer site: play/pause/step/scrub through the compiled operations; pieces appear when placed, screws animate insertion with `head(u) = E - d*(L+g)*(1-u)` so the final frame equals the approved model exactly; per-step camera hints; active pieces highlighted.
- **Status & blockers panel** on the site showing the loaded plan's real status, hashes and unresolved blockers (F14).
- Evidence-kind field (`pilot_evidence_kind`: `fixture` | `manufacturer_instruction` | `recorded_trial`, required for pilot/none modes). **Fixture evidence can never issue a workshop plan**, even with a matching approval hash (F04).
- Publication gate tests: the public tree (`published/`, `site/demo`) must contain no `REVIEWED_WORKSHOP_PLAN`, every published manifest must match its plan hash, and published bundles must ship the operations schedule (F01).

### Changed
- **Screw selection is now price-independent** (`length, diameter, id`): repricing can no longer swap installed hardware under an unchanged approval (F02). Regression test with competing same-length screws.
- **Physical-design hash tightened:** excludes commercial rules (spares %, price-age days), includes generator version (F02b).
- **Single readiness calculation:** a missing approval hash now blocks draft/check (`release_ready=false`) the same as release — no more "draft looks clear, release fails" divergence (F05).
- **Public tree quarantine:** stale `build/*` packs removed from the repo and `build/` re-ignored; only the current v0.3.0 options pack is tracked under `published/` with identity checks. `tools/viewer.py` defaults to the published pack and now HTML-escapes plan values (F01/F14).
- **Viewer fixes:** DPR-correct resize tracking (no more per-frame resize at high DPI, F11); per-bed display groups so batch jobs render side by side without altering manufacturing coordinates (F12); recursive geometry disposal on offer switch (F14).
- **Print sizing:** parts board paginates with table-only continuation pages (readable ~11pt rows); stock-arrival board paginated at 8 boards/page (~9.6pt); options PDF now includes stock pages.

### Notes
- F03 (modelled head seats/joint recipes) and the full keyed drilling-recipe work remain gated on the physical trial; the operations model already carries the STOP semantics until then.
- Version 0.3.0: physical-design hashes changed (generator version now included); demo fixture approval hash re-embedded. 99 tests passing.

## 2026-09-08 (v0.2.0) — engineering review fixes

### Added
- **Physical-design approval binding (release gate):** plans now carry `physical_design_hash` (SHA-256 over profile/beds/orientation/stock lengths+trims/screw specs/geometric rules; excludes prices, packs, availability, provenance text, review block and as-of date). `--release` requires `review.approved_physical_design_hash` to match: mismatch blocks (`stale_approval`), missing hash blocks (`approval_hash_required`). Price-only revisions keep a physical approval; dimension/hardware/machining changes invalidate it.
- **Head-seat honesty:** explicit non-blocking `head_seat_unmodeled` issue on every multi-course bed (screw heads, bearing seats, recesses and driver access are not modelled), plus BUILD.md step 7 text and an ENGINEERING.md section.
- CLI summary and BUILD.md header now print the physical design hash for copy-into-job workflow.
- Regression tests: approval binding (missing/stale/machining-change/price-only), hash format validation, head-seat presence, demo-fixture markers. Suite: 91 tests.

### Changed
- `examples/reviewed-example.json` and `catalogues/wickes-reviewed-2026-09-06.json` are now explicitly marked **DEMONSTRATION ONLY** (reviewer "DEMO FIXTURE", placeholder pilot-evidence strings). Their previous text could be mistaken for real workshop evidence; no real timber was ever cut or drilled for this repo.
- Version bump to 0.2.0 (results-affecting change per AGENTS.md invariant 12).

### Fixed (drawing/PDF)
- Piece-sheet zoom callouts no longer overlap the member views (views narrowed to reserved callout column).
- Parts/fixings board paginates in PDFs (18 rows/page) instead of shrinking to fit one page; applies to workshop.pdf and options-and-build.pdf.

## 2026-09-08

### Added
- Combined height-options PDF: `compare --pdf` now also writes `options-and-build.pdf`, one document covering every requested height (1/2/3 courses) with:
  - Options overview table (courses, outside size, pieces, fixings, sleepers, saw cuts, timber + screws cost).
  - Same-scale comparison drawing page.
  - Per-option section: build sequence, corner-pattern instruction, assembled view, one plan page per course, cutting diagrams, process and parts boards.
  - Pointer to each option's full `workshop.pdf` / `cuts.csv` / `fixings.csv`.
- Regression test for deterministic options-PDF generation (`test_options_pdf_covers_each_height`).
- Generated pack `build/first-model-2400x1400-options-1-2-3/` for the 2400 x 1400 example across 1, 2 and 3 courses.

### Fixed
- "1 courses" pluralisation on height-comparison drawings.

## 2026-09-07

### Added
- Static customer visualiser under `site/` for 1/2/3 course offer presentation.
- Interactive browser 3D controls (orbit/pan/zoom) with Z-up orientation.
- Clear per-piece black edge lines in the viewer to make course splits visible.
- Exported `web-manifest.json` for static-web artifact discovery and viewer camera defaults.
- Exported `quality-report.json` for deterministic export integrity checks.
- Client-facing panel content: option summary, process flow, and links to assembled/process/manual/PDF artifacts.

### Changed
- Reworked the site UI into a modern visual layout focused on client presentation rather than internal pack details.
- Updated repository docs to reflect static web scope and deployment status.

### Fixed
- Browser import resolution failure (`Failed to resolve module specifier "three"`) by switching to local vendor module imports.
- Viewer axis alignment to model coordinates (forced Z-up camera/object orientation).

### Deployment
- Vercel production alias verified: `https://site-rho-six-fdck1jw7c6.vercel.app`

### Notes
- Engineering/release safety gates are unchanged: draft plans remain draft until physical review and confirmed pilot evidence are recorded.

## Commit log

2026-09-06 Initial import of sleeperplan from NAS
    [comparison.csv, cuts.csv, fixings.csv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]
2026-09-07 Add view-cad.cmd helper to launch OpenSCAD 3D GUI
2026-09-08 Add customer web visualiser, web export artifacts, and combined height-options PDF
    [cuts.csv, fixings.csv, model.scad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]
2026-09-08 v0.2.0: bind release approval to physical design, mark demo fixtures, honest head-seat warning, PDF layout fixes
    [cuts.csv, fixings.csv, model.scad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]
2026-09-08 Include generated build packs and make repository public-ready
    [comparison.csv, cuts.csv, fixings.csv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]
2026-09-08 v0.3.0: operations model + assembly player, fixture-evidence gate, publication quarantine
    [comparison.csv, cuts.csv, fixings.csv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]
2026-09-08 v0.4.0: IKEA-style assembly manual + animation upgrade
2026-09-08 Add external construction-pack exemplar as the manual design standard
    [mark_out_2400x1400_three_courses.csv]
2026-09-09 Record 9-sleeper optimisation for 3-tier bed
